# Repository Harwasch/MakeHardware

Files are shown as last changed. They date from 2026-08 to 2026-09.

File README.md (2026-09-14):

# MakeHardware

A Claude Code **plugin** that teaches AI agents to do hardware engineering, and
the cloud environment that gives them the tools to do it.

This repo is not a hardware project. It holds the workflow, practices, skills
and definitions; the projects themselves live in their own repos and install
this plugin.

```
MakeHardware  (this repo)          your-widget  (a project repo)
├── the workflow                   ├── plan.yaml
├── the skills                 ──► ├── requirements/
├── the house practices            ├── cad/  hw/  sim/
└── the environment setup          └── docs/{reference,design,user}
```

## Using it on a project

**Start here: [docs/03-using-it.md](docs/03-using-it.md)** walks through a whole
project from a one-sentence idea to a verified design.

The short version — in the project repo's `.claude/settings.json`:

```json
{
  "extraKnownMarketplaces": {
    "makehardware": {
      "source": { "source": "github", "repo": "Harwasch/MakeHardware" }
    }
  },
  "enabledPlugins": { "makehardware@makehardware": true }
}
```

That is enough on a local machine you have trusted for plugins. **In a cloud
session it is not sufficient on its own** — a repo-declared marketplace is
ignored for an untrusted folder, and `enabledPlugins` never installs anything.
The environment's setup script therefore installs the plugin at user scope; see
[docs/01-environment.md](docs/01-environment.md#why-the-setup-script-installs-the-plugin).

Then point the project at a cloud environment built from [`env/`](env/) and run
`/hw-new-project` to scaffold it.

To stop copying that file into every new repo by hand, make a **GitHub template
repository** out of [`templates/github-repo/`](templates/github-repo) — see
[docs/04-template-repo.md](docs/04-template-repo.md).

## The workflow

```
1 VISION ─► 2 PLAN ─► 3 REQS ─► 4 ARCHITECTURE ─► 5 DESIGN ─► 6 SIMULATE ─► 7 VERIFY
 interview   chunks &  decompose  block diagram    schematic   ngspice       evidence
 + renders   deps      + validate  + power budget   + CAD       FEA           + gate
     ▲          ▲          ▲            ▲              ▲           │            │
     │          │          │            │              └───────────┘            │
     │          │          │            └──── a rail is short ──────┤            │
     │          │          └────────── numbers must move ───────────┤            │
     └──────────┴──────── the thing is not what they meant ─────────────────────┘
```

Stages 1–4 are agreements with a human. Stages 5–7 are a loop. Full detail in
[docs/02-workflow.md](docs/02-workflow.md).

**Every agreement is a recorded one.** The agent is normally working in a cloud
VM, so the human's only review surface is this repository on github.com. At each
milestone the agent commits an artefact that renders there — a vision document,
the plan's scope and Gantt, the requirements map, the block diagram, a schematic
PDF — asks the human directly with the link, and records what they said in
`docs/review/reviews.yaml`. `review-gate check --gate` fails while a milestone
is unanswered, or while an artefact has changed since it was signed off. A
chunk in `plan.yaml` cannot be marked `done` until its review is signed and its
declared outputs exist on disk.

Alongside the repo there is **one review page per project** — `review-artifact`
builds `docs/review/artifact.html` from the repo and it is published as a
Claude Artifact: a tab per phase, every figure and number read from the file
that owns it, and the human comments on it in place. GitHub is the record; the
page is the thing they actually read. `review-artifact --init` writes its
config, and `--url` records where it was published so every later session
updates that page rather than making a second one.

The rule behind it: **an artefact the human has not seen is not a deliverable.**
And its corollary, which is what most of 0.4.0 is about: an artefact they
cannot *read* has not been seen. A schematic nobody can follow, a STEP file
that opens as one unnamed solid, and a wall of numbers where a chart belongs
are all deliverables in name only.

## What the plugin provides

| | |
|---|---|
| **Skills** | `hw-vision`, `hw-planning`, `hw-requirements`, `hw-block-diagram`, `hw-schematic`, `hw-pcb-layout`, `hw-cad`, `hw-optimize`, `hw-review`, `hw-visuals`, `hw-sourcing`, `hw-simulation`, `hw-magnetics`, `hw-verification`, `hw-documentation`, `hw-imagegen`, `hw-retro` |
| **Commands** | `/hw-new-project`, `/hw-status`, `/hw-review`, `/hw-retro` |
| **Gates** | `sch-lint`, `pcb-lint`, `cad-export --check`, `req-trace --gate`, `block-diagram --check`, `plan-render --check`, `review-gate check`, `hw-iterate status --gate` |
| **Tools on PATH** | `hw-doctor`, `hw-repair`, `plan-render`, `req-trace`, `block-diagram`, `vision-board`, `review-gate`, `review-artifact`, `sch-lint`, `pcb-lint`, `cad-export`, `hw-chart`, `hw-iterate`, `hw-feedback`, `imagegen` |
| **MCP servers** | `spice` (ngspice/LTspice), `build123d` |
| **Templates** | An A3 KiCad drawing sheet and the house grid, text sizes and net classes |
| **Practices** | House standards for schematic and board drawing, sourcing, connectors, passives and charts — edited over time to steer the agent |

## The toolchain

| Layer | Tool |
|---|---|
| Human review | `review-gate` — artefacts that render on GitHub, a link put to the human, a committed sign-off with a digest per artefact |
| Requirements | StrictDoc, with a hardware grammar and a traceability gate, plus a draw.io/SVG requirements map |
| Architecture | `block-diagram` — one YAML spec renders an editable draw.io file, a review SVG, and a power budget with a gate |
| Planning | `plan-render` — a dependency Gantt, an editable draw.io graph, and a scope document, with `done` checked against the filesystem |
| Schematic / PCB | KiCad 10 + [KiStack](https://github.com/American-Embedded/KiStack) skills over `kicad-cli` and `kicad-python` |
| Circuit simulation | ngspice via `ltspice-mcp`; LTspice opt-in |
| 3D CAD | build123d + `build123d-mcp` |
| Meshing / FEA | gmsh + CalculiX |
| Vision imagery | build123d renders for geometry; HF Spaces or a keyed API for styling |
| Design review | [kicad-happy](https://github.com/aklofas/kicad-happy) — EMC, thermal, derating, distributor search |

Why each, and what was rejected: [docs/00-stack.md](docs/00-stack.md).

## Setting up the environment

Three fields in the cloud environment dialog at
[claude.ai/code](https://claude.ai/code):

1. **Network access → Full.** Nothing to paste. Sourcing and documentation
   mean fetching datasheets from vendors you can't enumerate in advance, so an
   allowlist makes every new manufacturer a config change.
   [`env/allowed-domains.txt`](env/allowed-domains.txt) has the tighter
   Custom fallback if you'd rather not run open — note that on **Trusted** you
   silently get KiCad 7 instead of 10.
2. **Environment variables** ← [`env/environment-variables.env`](env/environment-variables.env)
3. **Setup script** ← [`env/setup.sh`](env/setup.sh) — this also installs the
   plugin itself, which is why a cloud session gets the skills and MCP servers
   without a trust dialog.

Then run `hw-doctor` in a session. Details and the five failure modes the
script works around: [docs/01-environment.md](docs/01-environment.md).

## Layout

```
.claude-plugin/marketplace.json   marketplace manifest
plugins/makehardware/
├── skills/                       the workflow stages
├── commands/                     /hw-new-project, /hw-status, /hw-review, /hw-retro
├── bin/                          hw-doctor, hw-repair, plan-render, req-trace,
│                                 block-diagram, vision-board, review-gate,
│                                 review-artifact, hw-chart, hw-iterate, imagegen
├── scripts/                      their implementations
└── .mcp.json                     spice, build123d
templates/github-repo/            contents of the GitHub template repository
examples/thermal-probe/           a worked project, part-way through — see below
env/                              cloud environment configuration
docs/                             stack rationale, environment, workflow
tests/smoke.sh                    scaffolds a throwaway project and drives the gates
tests/real-tool-output.sh         what the review page does with real exporter output
tests/version-bump.sh             refuses a plugin change that did not bump the version
CHANGELOG.md                      what changed, per version
CLAUDE.md                         house rules for working on this repo
```

`tests/smoke.sh` needs only `python3` with `pyyaml`. It scaffolds a project
from the template and checks the things that used to have nothing behind them:
a `done` chunk whose outputs are missing, a `done` chunk whose review is
unsigned, an artefact edited after sign-off, and the power budget's voltage
referral.

`tests/real-tool-output.sh` covers the other half: what the review page does
when it is handed what the real tools emit rather than what we would write by
hand. Page size in millimetres, a `<style>` block whose selectors are global
once inlined, KiCad 10's layer-named ids colliding between sheets, a
megabyte-and-a-half render, a PDF, and an export that silently did not happen.

## Releasing

Any change under `plugins/makehardware/` must bump the version in **both**
`.claude-plugin/marketplace.json` and
`plugins/makehardware/.claude-plugin/plugin.json`, with a `CHANGELOG.md` entry
in the same commit.

This is not housekeeping. `claude plugin install` treats an already-installed
plugin at the same version as nothing to do, so a version that does not move
means a user who runs `claude plugin marketplace update makehardware` fetches
the new source, sees a version they already have and **keeps running the old
code**. `tests/version-bump.sh` fails the build when it happens.

Users on an existing cloud environment pick up a release either by rebuilding
the environment — `env/setup.sh` installs the plugin at container build — or
with `claude plugin marketplace update makehardware` in a live session.

## The worked example

[`examples/thermal-probe/`](examples/thermal-probe) is a project caught
part-way through: one milestone approved, one awaiting an answer, one gone
stale because an artefact moved underneath it, and one never requested. It is
what the review page is developed against.

```bash
cd examples/thermal-probe && ./build-fixture.sh
```

rebuilds every artefact from its spec — including the schematic sheets, which
are genuine `kicad-cli sch export svg` output where `kicad-cli` is installed,
because what a plotter emits is nothing like what you would draw by hand.

## Docs

* [docs/00-stack.md](docs/00-stack.md) — choices, rejections, measured build budget
* [docs/01-environment.md](docs/01-environment.md) — environment configuration
* [docs/02-workflow.md](docs/02-workflow.md) — the seven stages and their exit conditions
* [docs/03-using-it.md](docs/03-using-it.md) — how you actually run a project with it
* [docs/04-template-repo.md](docs/04-template-repo.md) — a GitHub template repo so new projects start correct

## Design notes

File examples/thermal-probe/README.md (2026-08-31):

# Thermal Probe

Example project used to develop the MakeHardware review artifact.

<!-- PLAN:BEGIN -->
<!-- generated by plan_render.py — edit plan.yaml, not this block -->

Project plan

**0/11 chunks complete** · 10 sessions on the critical path · [editable version](docs/plan.drawio)

<!-- PLAN:END -->

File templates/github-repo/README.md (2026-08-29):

# <project name>

A hardware project built with the [MakeHardware](https://github.com/Harwasch/MakeHardware)
workflow. Replace this paragraph with one sentence about what the thing is.

<!-- PLAN:BEGIN -->
<!-- PLAN:END -->

## Getting started

This repo was created from the MakeHardware project template, so
`.claude/settings.json` is already correct. In the **first** session, run:

```
/hw-new-project
```

That scaffolds `plan.yaml`, `requirements/`, `hw/`, `cad/`, `concepts/`,
`sim/`, `docs/`, `strictdoc.toml` and a project `CLAUDE.md` from the plugin's
current templates, then runs `hw-doctor` and `imagegen --list` so you know what
the toolchain can actually do before you plan around it.

Then start the vision interview:

```
Use hw-vision. I want to build <one sentence>.
```

## The commands you will use

```bash
hw-doctor                 # what the toolchain can actually do right now
/hw-status                # progress, what is ready to start, what is waiting on you
/hw-review <milestone>    # build the artefact, ask you about it, record the answer
plan-render               # refresh docs/plan.{svg,md,drawio} and the block above
plan-render --check       # exit 1 on a `done` chunk whose outputs or review are missing
block-diagram             # refresh the architecture diagram and power budget
block-diagram --check     # architecture gate; exit 1 on an over-budget rail
req-trace --gate          # traceability gate; exit 1 while gaps remain
req-trace --map           # redraw the requirements map
review-gate list          # where every human review stands
```

## How you get asked things

Claude runs in a cloud VM, so it cannot show you anything directly. At each
milestone — the vision, the plan, the requirements, the architecture, and each
large design stage — it commits something that renders here on GitHub and then
asks you, with the link:

| Look at | For |
|---|---|
| `docs/design/vision.md` | the concepts, their envelopes and masses |
| `docs/plan.md` | what each chunk of work actually is |
| `docs/design/requirements-map.svg` | the requirement tree and its gaps |
| `docs/design/block-diagram.svg` | the power tree and the buses |
| `docs/design/*.pdf` | schematics and board layer plots |

Your answer goes into `docs/review/reviews.yaml`, and nothing downstream is
marked done without it. If Claude later changes something you signed off, that
review goes stale and it has to come back and ask again.

## Before you start: the environment

The plugin's skills are useless without the toolchain behind them. This repo
needs a Claude Code cloud environment built from
[MakeHardware's `env/`](https://github.com/Harwasch/MakeHardware/tree/HEAD/env) —
network access **Full**, the environment variables file, and the setup script.

The setup script is not optional. `.claude/settings.json` declares the plugin
but does not install it: in a cloud session a repo-declared marketplace is
ignored for an untrusted folder, so the setup script installs the plugin at
user scope. Without it you get a repo with no skills in it.

See [docs/01-environment.md](https://github.com/Harwasch/MakeHardware/blob/HEAD/docs/01-environment.md).

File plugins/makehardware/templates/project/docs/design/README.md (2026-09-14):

# Design documentation

How and why this system was built, written as the work happens.

* `adr-NNNN-<slug>.md` — decision records. One per decision that constrains
  anything downstream.
* `architecture.md` — the block-level picture and how the pieces divide.
* `interfaces.md` — board outline, connector pinouts, mounting, anything two
  disciplines have to agree on.
* `verification-report.md` — the output of the verification stage.
* `friction-log.md` — three-line entries written during the work, whenever a
  correction or an avoidable loop happens, each naming the MakeHardware file
  that should change. See the `hw-retro` skill.
* `retro.md` — the synthesis, written by `/hw-retro` at a milestone.
* `feedback/` — one file per finding about the **toolbox**, written by
  `hw-feedback new` and published as an issue on the plugin's repo at the
  retro. Findings about *this design* are not these; they are ADRs.

An ADR has: Status, Context, Decision, Consequences, Alternatives considered.
Write the Consequences honestly, the bad ones included — that section is what a
future session reads when the number has to move.

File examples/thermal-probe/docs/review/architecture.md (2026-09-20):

# Review — Block diagram, power tree and buses

`architecture` · requested 2026-09-20 · branch `claude/board-docs`

Four rails. VBUS is the tight one at 90% of the USB-C default
500 mA while charging, which is fine because it is a charge-only rail — but it
is the number to check. Standby on V3P3 comes to 12 uA of the 40 uA budget.

## What you are agreeing to

**block-diagram.svg**



## For context

Sources and working files. Not part of the agreement — these change as work goes on, and changing them does not invalidate your sign-off.

| File | Opens in |
|---|---|
| [hw/block-diagram.drawio](https://github.com/Harwasch/MakeHardware/blob/claude/board-docs/hw/block-diagram.drawio) | draw.io / VS Code extension |
| [hw/block-diagram.yaml](https://github.com/Harwasch/MakeHardware/blob/claude/board-docs/hw/block-diagram.yaml) | plain text on GitHub |

## What we need decided

1. Is a rail or a part missing?
2. SPI1 shares flash and LCD on one bus — acceptable, or separate them?
3. Is charging at 450 mA off a 500 mA port too close?

## Decision

**Not yet reviewed — this is waiting on you.**

Answer in the Claude session that sent you this link. There is nothing to run and nothing to sign here.

Say which option you want **and why**: the reason is worth more than the choice, and it is what gets re-read later when a number has to move. If something is wrong, say what would be right.

<details><summary>How the answer gets recorded</summary>

The agent writes your decision, in your words, into [`docs/review/reviews.yaml`](https://github.com/Harwasch/MakeHardware/blob/claude/board-docs/docs/review/reviews.yaml):

```bash
review-gate sign architecture --approve --by <name> --note "..."
review-gate sign architecture --changes "what to change"
```

Until that happens, any chunk of work depending on this review cannot be marked done.

</details>

---

<sub>Generated by `review-gate`. The sign-off record is [`docs/review/reviews.yaml`](https://github.com/Harwasch/MakeHardware/blob/claude/board-docs/docs/review/reviews.yaml).</sub>

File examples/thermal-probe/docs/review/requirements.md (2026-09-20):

# Review — Requirements tree

`requirements` · requested 2026-09-20 · branch `claude/board-docs`

Fifteen requirements. SYS-001 moved from 12 h to 7 d after the
logging interval was settled at one minute, which is the number worth arguing
about.

## What you are agreeing to

**requirements-map.svg**



## For context

Sources and working files. Not part of the agreement — these change as work goes on, and changing them does not invalidate your sign-off.

| File | Opens in |
|---|---|
| [requirements/00-vision.sdoc](https://github.com/Harwasch/MakeHardware/blob/claude/board-docs/requirements/00-vision.sdoc) | StrictDoc source |
| [requirements/10-system.sdoc](https://github.com/Harwasch/MakeHardware/blob/claude/board-docs/requirements/10-system.sdoc) | StrictDoc source |
| [requirements/hardware.sgra](https://github.com/Harwasch/MakeHardware/blob/claude/board-docs/requirements/hardware.sgra) | download |

## What we need decided

1. Is 7 days the right target, or is 5 with a smaller cell better?
2. Is anything here that nobody asked for?

## Decision

**Approved** 2026-09-20 by harrison. Nothing is needed from you here.

> 7 days. A week means Friday-to-Friday and nobody has to think.

---

<sub>Generated by `review-gate`. The sign-off record is [`docs/review/reviews.yaml`](https://github.com/Harwasch/MakeHardware/blob/claude/board-docs/docs/review/reviews.yaml).</sub>

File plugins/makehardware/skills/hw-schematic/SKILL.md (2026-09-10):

---
name: hw-schematic
description: House practice for a schematic a human can actually read - how to split a design into sheets from the agreed block diagram, where on the sheet each thing goes, and the gate that checks it. Use before starting schematic capture, whenever a sheet is being laid out or re-laid out, when a schematic needs to go in front of a reviewer, and when asked whether a drawing is readable or why a sheet is too big. KiStack's kicad-schematic does the placing and wiring; this decides what goes where and what good looks like, and wins where the two disagree.
---

# Drawing a schematic somebody can read

The tooling will place a symbol anywhere you tell it to. That is the problem.
Nothing in the toolchain has an opinion about *where*, so a capture loop that
is only trying to satisfy a netlist produces a drawing that is electrically
correct and visually unreadable — and the review that was supposed to catch
the design error instead gets spent on deciphering the picture.

The rule this skill exists to enforce:

> **A schematic is a document, not a netlist with coordinates.** Its job is to
> let a human find a circuit, follow it, and judge it. If it does not do that,
> it does not matter that it is correct.

**Start at `ki-stack-orient`, and work `references/kicad-channels.md` when a
step fails.** Between them they answer the recurring question: `kicad-cli`
cannot author — it has no `add`, `place`, `route` or `connect` verb — so
authoring is either live IPC (`kipy`, needs `hw-kicad-up`) or an edit to the
file itself. It also has the table of where KiStack's house practice and this
skill's disagree — the sheet strategy is the one that matters.

Run the gate:

```bash
sch-lint hw/probe.kicad_sch                    # the report
sch-lint hw/probe.kicad_sch --gate             # exit 1 on any ERROR
sch-lint hw/probe.kicad_sch --svg docs/design/lint      # the findings, drawn
sch-lint hw/probe.kicad_sch --plan hw/block-diagram.yaml
```

`--svg` is the one to use in a review: it writes a light overlay of the sheet
with every finding circled and numbered. About three hundred elements against
the sixty thousand a real KiCad plot costs, so it inlines on the review page
and renders on github.com, which the plot does not.

## Before any symbol is placed: plan the sheets

Capture starts from `hw/block-diagram.yaml`, not from a blank page. The
architecture was already agreed with a human at the architecture review; the
sheet plan is that agreement turned into pages.

The default partition, which you deviate from only for a reason you write down:

| Sheet | Carries | Why it is its own sheet |
|---|---|---|
| 1 | **Root** — one hierarchical block per sheet below, wired to each other | It is the block diagram. A reviewer who has seen the block diagram can read page 1 in ten seconds. |
| 2 | **Power** — the whole tree: input, protection, every regulator, every rail's bulk | A rail is a system-level object. Split across sheets, nobody can see the tree. |
| 3 | **Processor core** — the MCU/SoC, its crystal, reset, boot straps, debug header, and *its* decoupling | Decoupling lives beside its part, never on a "capacitors" sheet. |
| 4..n | **One sheet per functional group** — one sensor chain, one radio, one motor driver | One sheet, one job. A sheet you cannot name in three words is two sheets. |
| last | **Connectors, test points, mounting, fiducials** | The mechanical/external interface, which is what someone bringing the board up looks at first. |

`sch-lint --plan hw/block-diagram.yaml` checks this bound the other way: every
block the human agreed to has to appear on exactly one sheet. A block in the
agreed architecture and on no sheet was dropped without a decision, and that is
the failure this catches — silently, otherwise, until layout.

See `references/sheet-plan.md` for how to derive the plan and how to size a
sheet before you fill it.

## The rules, and what each one costs when broken

Full list with the reasoning in `references/readability.md`. The short version,
in the order they bite:

**Signal flows left to right, power flows top to bottom.** Inputs and their
connectors on the left, processing in the middle, outputs and their connectors
on the right. Rails drawn upward out of a part, grounds downward. This is the
one convention every reader already has, and every violation costs them a
re-read of the sheet. `SCH-FLOW`, `SCH-PWRDIR`.

**Everything on the 1.27 mm grid.** Not aesthetics — a pin 0.01 mm off grid
looks connected and is not, and ERC will not tell you. `SCH-GRID`.

**Wires orthogonal.** No diagonals. `SCH-DIAG`.

**Every net that matters carries a name a human chose.** `3V3_ANA`, not
`Net-(U2-Pad3)`; `SPI1_MOSI`, not `N$32`. A net name is the only handle a
reviewer, a layout engineer and a bring-up engineer share. `SCH-AUTONET`.

**Use labels instead of long wires.** Past about a third of the sheet, a wire
is worse than a label: it crosses things, and following it is work. Short stub,
name it, move on.

**Decoupling is drawn beside the pin it decouples.** Not in a row at the edge
of the sheet. A cap drawn 60 mm from its IC is a cap that ends up 12 mm from it
on the board, because whoever placed the board read the schematic. `SCH-DECAP`,
and then `pcb-lint`'s `PCB-DECAP` measures the copper.

**One text size.** 1.27 mm, with 1.524 and 2.54 for headings. Five sizes on a
sheet reads as five levels of importance that do not exist. `SCH-TEXTSIZE`.

**Designators count the way the eye moves** — left to right, top to bottom, per
sheet. Someone is holding a BOM line looking for R47. `SCH-ANNOT`.

**A filled title block, and the same revision on every sheet.** A printed sheet
with no name, revision or date is not a document, and two sheets at different
revisions means nobody can say which drawing was agreed to. `SCH-TITLE`,
`SCH-REVSKEW`.

**Hierarchical pins match the child's labels exactly.** `VPP-MCLR` against
`VPP_MCLR` is a broken connection that looks fine on both pages.
`SCH-SHEETPIN`.

**A sheet the review page cannot embed is a sheet nobody will review.** KiCad
writes one path per glyph stroke, so an ordinary A4 sheet is 60,000 SVG
elements and three megabytes — twice what `hw-review`'s page can inline. Over
budget is not a rendering problem, it is too much on one page. `SCH-DENSITY`.

## Doing the work

1. **Sheet plan first**, from `hw/block-diagram.yaml`. Write it down in
   `docs/design/` before placing anything.
2. **Create the sheets and the hierarchy**, then the sheet pins, then wire the
   root. Page 1 should look like the block diagram.
3. **Fill one sheet at a time**, in reading order: connectors and inputs on the
   left edge, the main part in the middle, outputs right. Place the main part
   first, then its decoupling against its power pins, then everything else.
4. **Name every net as you make it.** Renaming later is a diff nobody reviews.
5. **Run `sch-lint` after every sheet**, not at the end. Every finding is
   cheaper now than after the next sheet.
6. **Run ERC as well** — `kicad-cli sch erc` — and put the count in the review
   summary as a number, not as an attachment.
7. **Export and look at it yourself** before showing anyone. Half of what a
   reviewer would catch, you will catch first.

Edits go through the **IPC bindings** where a KiCad is running, and through the
file itself otherwise — that is what KiStack's `kicad-schematic` assumes. Never
hand-roll an S-expression edit: `sed` or a regex on a `.kicad_sch` invalidates
UUIDs and symbol instance paths, the file still opens, and the netlist is
quietly wrong. Change one thing, re-export, and look at the plot. `sch-lint`
only ever reads.

## Setting up a new project's schematic

```bash
# The house drawing sheet: A3 frame, title block wired to the project fields.
cp "${CLAUDE_PLUGIN_ROOT}/templates/kicad/makehardware.kicad_wks" hw/
```

Then point the project at it (`Page Settings -> Drawing sheet`, or
`schematic.page_layout_descr_file` in the `.kicad_pro`), and merge the house
grid and text defaults from `templates/kicad/house-defaults.json` into the
`.kicad_pro` — a `.kicad_pro` is JSON, so this is one of the few KiCad files a
structured edit can touch without a KiCad parser. `/hw-new-project` does both.

A3 is the default because A4 forces a split that is about paper rather than
about function, and a sheet split for the wrong reason is worse than a slightly
full one.

## What this skill is not

It is not a circuit-design skill. What the circuit *should be* comes from the
requirements, the block diagram, `hw-sourcing` for the parts and the datasheet
for the topology. This is only about the drawing — which is the half that
decides whether anybody catches the mistake in the other half.

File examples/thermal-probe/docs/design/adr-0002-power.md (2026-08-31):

# ADR-0002: Linear regulator for the always-on rail

## Status
Accepted — 2026-08-14

## Context
`ELE-001` caps standby draw at 40 uA on the always-on rail. The rail is 3.3 V
and carries under 12 mA even when the display is refreshing, so the question is
quiescent current, not efficiency at load.

## Decision
MCP1700 LDO from VBAT, rather than a buck converter.

## Consequences
- Quiescent current 1.6 uA typ, 4 uA max over temperature. That is 10% of the
  40 uA budget, which leaves room for the reference and the MCU's stop-mode
  leakage.
- Dropout is 178 mV at 100 mA, so the minimum usable cell voltage is 3.48 V.
  That truncates the discharge curve and costs roughly 4% of nameplate
  capacity — accepted, and it feeds the `SYS-001` analysis.
- Efficiency above 5 mA is poor. The display refresh burst runs at 12 mA for
  40 ms once a minute, which is 8 uAh per hour of waste. Negligible here, but
  if a backlight is ever added this decision has to be revisited.

## Alternatives considered
- **TPS62740 buck**: 360 nA Iq and far better burst efficiency, but it needs a
  2.2 uH inductor and 4 mm² of board the `MEC-001` envelope does not have at
  the agreed 38 mm width.
- **Direct from VBAT, no regulator**: the ADC reference would then move with
  the cell, and `ELE-003` asks for 0.2 degC over the range. Ratiometric
  measurement against a gated REF3025 was cheaper than a regulator good enough
  to be a reference.

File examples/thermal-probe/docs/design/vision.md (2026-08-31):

# Vision — Thermal Probe

A handheld probe that logs temperature in a walk-in freezer for a week on one charge, readable with gloves on. Every image below comes from a parametric model, so the numbers are measured off the geometry rather than estimated.

## The choice

| | **Wand** | **Bench instrument** |
|---|---|---|
| Envelope (mm) | 38 × 164 × 22 | 92 × 118 × 34 |
| Volume (mm³) | 72,840 | 214,600 |
| Approx. mass (g) | 102 | 300 |

## Wand

One-handed. Probe on a 300 mm flex lead so the body never enters the cold zone. Two-digit display, one button.

**What this one bets on:** That the freezer walk is the whole job, so the display can be small and the body has to survive a glove.

**38 × 164 × 22 mm** · 72,840 mm³ · ~102 g at 1.4 g/cm³

Wand

## Bench instrument

Sits on a shelf in the plant room and gets picked up. Four-digit display with a trend strip, dock contacts on the base.

**What this one bets on:** That it lives in one place and is read at arm's length, so it can be wider and carry a bigger cell.

**92 × 118 × 34 mm** · 214,600 mm³ · ~300 g at 1.4 g/cm³

Bench instrument

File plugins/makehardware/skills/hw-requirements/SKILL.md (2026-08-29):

---
name: hw-requirements
description: Author, decompose and validate hardware requirements as StrictDoc .sdoc files with full parent/child traceability. Use after the vision is agreed, whenever requirements need adding, splitting or renumbering, or when asked whether a design actually satisfies what was asked for.
---

# Requirements

Requirements live in `requirements/*.sdoc` and share the grammar in
`requirements/hardware.sgra`. They are plain text in git, so they diff and
review like code.

## The levels

The UID prefix carries the decomposition level. Nothing else does.

| Prefix | Level | Testable? | Refines |
|---|---|---|---|
| `VIS-` | vision intent, in the human's words | no, deliberately | nothing |
| `SYS-` | system requirement | yes | a `VIS-` |
| `ELE-` `MEC-` `FW-` `MFG-` | discipline requirement | yes | a `SYS-` |

Two rules make the tree mean something:

* **Every non-vision requirement Refines exactly one parent.** If you cannot
  name the parent, nobody asked for the requirement — raise it with the human
  instead of inventing a parent.
* **Every leaf carries EVIDENCE before it can be Verified.** A requirement with
  no evidence is a claim.

## Writing one

One "shall" per requirement, with a number and a unit wherever physics allows
one. "Low power" is not a requirement; "<= 40 uA in standby" is.

`RATIONALE` is the field that earns its keep. Write down *why this number*.
It is what you re-read when the number has to move, and it is what stops a
later session quietly relaxing a limit.

Use `BUDGET` when a parent's number is being divided among children, so the
roll-up can be checked: a 12 h parent against 40 uA + 180 uA children.

Multi-line fields need explicit block markers, and the body is rendered as
RST — a bare `SYS-*` will break the build on an unterminated emphasis span,
so write ``` ``SYS-`` ``` instead:

```
RATIONALE: >>>
Derived from SYS-001: a 900 mAh cell, 12 h active at 65 mA, and a 7-day
standby tail leaves 40 uA for the always-on rail.
<<<
```

## Validating

StrictDoc enforces referential integrity — duplicate UIDs and parents pointing
at nothing both fail the build:

```bash
/opt/hw-py/bin/strictdoc export requirements \
    --output-dir build/requirements --formats=html,json
```

What StrictDoc will not judge is whether the decomposition is any good. That
is `req-trace`, which finds orphans, undecomposed mid-level requirements,
leaves with no evidence, requirements with no design artefact linked, and
status/evidence mismatches:

```bash
req-trace              # report
req-trace --gate       # exit 1 on any gap
req-trace --map        # the requirements map: SVG + draw.io
```

Run the gate before claiming a stage is complete.

## Draw the tree, because that is what a human can review

A requirement set is a graph. Its two real failure modes — something hanging
loose, and a number that traces to nothing anybody asked for — are shape
questions, and reading a list of UIDs is how a gap survives a review.

```bash
req-trace --map        # docs/design/requirements-map.{svg,drawio}
```

The SVG renders inline on github.com: one column per decomposition level,
an arrow from each requirement to the one that refines it, the status on every
node, and the gate's findings marked in red on the nodes that have them. The
`.drawio` is the same graph, editable.

The StrictDoc HTML export is the complete, navigable version:

```bash
/opt/hw-py/bin/strictdoc export requirements \
    --output-dir docs/design/requirements-html --formats=html
```

GitHub will not render it, so it is a download — link it, say so, and do not
mistake generating it for having shown it to anyone. That export was produced
on every validation run of one project and never once mentioned.

## Validate the set, not just each requirement

Before starting design, check the things a per-requirement check cannot see:

* **Roll-up.** Do the children's budgets actually add up to the parent's? Say
  the arithmetic out loud.
* **Contradiction.** Two requirements that cannot both hold (an IP67 seal and
  a passive vent).
* **Over-constraint.** A requirement set with no feasible solution is more
  common than it sounds; if you cannot find one, say so now.
* **Missing verification.** Every leaf's `VERIFICATION` must be something this
  environment or the human can actually perform.

Report what you find to the human and get the numbers changed before design
starts, not after.

## Leaving the stage

The numbers in here are what every later stage is built on, and they are much
cheaper to argue about now. So the stage is not finished when the tree
validates — it is finished when a human has looked at it and agreed to the
numbers, recorded in the repo.

```bash
req-trace --map
git add requirements/ docs/design/requirements-map.* && git commit && git push

review-gate open requirements \
    --title "Requirements tree" \
    --summary "<the numbers that moved, the roll-ups, what you are unsure of>" \
    --artifact docs/design/requirements-map.svg \
    --reference requirements/ --reference docs/design/requirements-html/ \
    --question "Are these the right numbers?" \
    --question "Is anything here that nobody asked for, or missing that you assumed?"
```

Ask directly with the link, block on the answer, and record it with
`review-gate sign` — see `hw-review`. Lead the request with the arithmetic
you had to do to make the budgets roll up, and with any requirement you could
not find a parent for. Those are the two places a human catches something you
cannot.

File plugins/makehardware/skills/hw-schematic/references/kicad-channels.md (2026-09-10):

# Which channel touches a KiCad file, where KiStack fits, and who wins

Four things can read or write a `.kicad_*` file here, and they do not overlap.
Reaching for the wrong one is most of what "KiCad automation is flaky" turns
out to be, so this is the map — followed by the part that actually costs time,
which is what to do where KiStack's house practice and this toolbox's disagree.

**Two packs preceded this one.** Konnect (an MCP server, 214 tools) through
0.6.0; ki-stack through 0.7.0. If you are reading guidance that says "all
writes go through Konnect MCP tools", or that names a `ki-stack-*` skill, it is
stale — run `hw-repair kicad`, which installs
[KiStack](https://github.com/American-Embedded/KiStack) and clears the old pack
out of the snapshot.

## The four channels

| | `kicad-cli` | `kicad-python` (IPC) | direct file edit | `sch-lint` / `pcb-lint` |
|---|---|---|---|---|
| **Authors** | **no** | yes, live | yes, and this is what KiStack assumes | no |
| **Checks** — ERC, DRC | yes | via the running app | no | yes, plus house rules the CLI has no concept of |
| **Exports** — PDF, SVG, Gerber, BOM, 3D | yes | no | no | writes the findings overlay |
| **Needs a running KiCad** | no | **yes** | no | no |

`kicad-cli` has no `add`, `place`, `route` or `connect` verb on KiCad 10 and
never has, so authoring is IPC or the file itself. KiStack's own rule:
**prefer the IPC bindings wherever they are available** — `hw-kicad-up` starts
a KiCad and `kipy` connects to it. Fall back to editing the file when there is
no session to talk to.

When you do edit a file: change one thing, re-export, and look at it. Never
`sed` a `.kicad_sch` — a text-level edit invalidates UUIDs, symbol instance
paths and cross-sheet references, the file still opens, and the netlist is
quietly wrong. `scripts/kicad_sexpr.py` here is a **reader**; `sch-lint` and
`pcb-lint` go through it and only ever read.

## The KiStack skills

`kicad-schematic`, `kicad-pcb`, `kicad-layout`, `kicad-symbol`,
`kicad-footprint`, `kicad-bom`, `kicad-export`, `kicad-gerbers`,
`kicad-panelize`, `pcb-product-render`. `kicad-export` carries a reference page
for every `kicad-cli` verb, which is the fastest way to get an export flag
right.

They are human-written house practice from a working shop, and the best thing
in them is the insistence on **iterating on rendered images**: plot the sheet
to SVG, look at it, fix what is ugly, look again. That is the same instinct as
`review-artifact` and `hw-optimize`, applied at a finer grain, and it is worth
following.

## Where KiStack and this toolbox disagree — and who wins

**The gate wins.** `sch-lint`, `pcb-lint` and `review-gate` are the things that
actually fail a stage, and a design that satisfies advice while failing a gate
is not shippable. KiStack supplies craft where the gates are silent.

Three specific collisions, so nobody has to discover them at review time:

| | KiStack says | This toolbox says | Take |
|---|---|---|---|
| **Sheet strategy** | prefer a single sheet you can see at once, bigger paper if needed | a sheet plan derived from the agreed block diagram, A3 default, one sheet per functional group | **the sheet plan.** `sch-lint --plan` binds every sheet back to the architecture a human signed off, and its density check fails an overfull sheet. A single huge sheet also does not render on the review page. |
| **Changing the schematic during layout** | feel free, do pin swaps to clean up routing | the schematic is an agreed artefact | **do it, then re-open the review.** The advice is right — pin swaps are how a board gets routable. But `review-gate` marks the schematic review stale the moment its artefact changes, and that is correct: the human agreed to a different drawing. Say what moved and why. |
| **Autorouting** | avoid it; route manually unless the board is very dense | `hw-verification/references/pcb-layout.md` documents freerouting | **no conflict.** Both say manual first. The freerouting notes exist for the dense case KiStack also allows. |

One that people expect to collide and does not: KiStack's **50 mil label text**
is exactly the house `text_size_mm: 1.27` in `templates/kicad/house-defaults.json`,
which is what `SCH-TEXTSIZE` checks. They agree.

## When a KiCad step fails

1. **Check the obvious first.** `kicad-cli version` (must be 10.x — a KiCad 7
   from Ubuntu universe has no IPC API at all), and that the path you are
   passing is the project's canonical file.
2. **`kipy` cannot connect.** No KiCad running (`hw-kicad-up`), the API server
   disabled in preferences, a busy KiCad, or a version mismatch. Not a reason
   to reach for a text editor — work on the file with a parser, or export and
   check what you have.
3. **The pack is missing.** `hw-doctor` reports `kistack`; `hw-repair kicad`
   installs it and clears any previous pack.
4. **`kicad-cli` refuses the file.** Almost always a major-version mismatch —
   `kicad-cli sch upgrade` / `pcb upgrade`, and say in the review that the file
   format moved.
5. **Only now escalate**, with the command, its output, and what you tried. A
   failure you worked around silently is worse than one you reported: the next
   session hits it again with none of what you learned.

## What to tell the human

**No success claim without evidence** — an artefact path, ERC/DRC output, a
changed-file list, or a render. A plot-after-edit is the cheapest proof there
is. Put it on the review page rather than describing it.

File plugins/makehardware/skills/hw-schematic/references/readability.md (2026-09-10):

# Every rule, and the failure it prevents

Each rule below has a `sch-lint` code beside it. A rule with no code is one
nothing can check yet — treat those as the ones needing the most attention,
because nothing else will catch them.

---

## 1. Direction

### Signal flows left to right — `SCH-FLOW`

Inputs and their connectors on the left edge, processing in the middle,
outputs and their connectors on the right. Feedback is the exception and is
drawn returning above or below the forward path, never through it.

This is not taste. A reader arrives at a sheet with an expectation about where
things are, and every sheet that violates it costs a full re-read. On a design
review that is the difference between a reviewer spending their attention on
your circuit and spending it on your drawing.

`sch-lint` reports the flow as a number — the mean normalised x of the outputs
minus that of the inputs — and warns below +0.15. It never gates: a power
sheet legitimately flows top to bottom and a connector sheet flows nowhere.

### Power flows up, ground flows down — `SCH-PWRDIR`

A rail symbol points up out of the part it feeds; a ground symbol points down.
A reader scans a sheet for supply structure by silhouette, before reading a
single label. A ground drawn sideways breaks that read for the whole sheet, and
`sch-lint` finds them by comparing each power symbol's body centroid against
its pin.

Corollary: on a part with power pins on the left and right, do not route the
rail through the body. Bring it in at the top.

---

## 2. Geometry

### The 1.27 mm grid — `SCH-GRID`

Everything electrical: symbol origins, pin ends, wire endpoints, junctions,
labels, sheet pins. 1.27 mm is 50 mil, KiCad's default, and the pitch every
library is drawn on.

The failure is not ugliness. **A pin 0.01 mm off the grid looks connected and
is not**, ERC reports nothing, and the defect surfaces as a net missing from
the netlist at layout time. It is the cheapest possible check and it catches
one of the most expensive possible mistakes.

Property *text* positions are deliberately not checked. KiCad's autoplacer
writes a reference at (27.3812, 91.5416) on a design that is otherwise
perfectly on-grid; checking those emits about forty errors on finished work,
and a gate that fires on clean work is a gate somebody switches off.

### Wires orthogonal — `SCH-DIAG`

No diagonals, ever. A diagonal wire cannot be followed across a crossing,
cannot be aligned with anything, and reads as an error even when it is not.
Graphic polylines — a dashed box around a functional group — are exempt and
are encouraged.

### Nothing overlapping — `SCH-OVERLAP`

Two symbol bodies overlapping by more than 0.5 mm² is a drawing defect. It
usually means an automated placement pass ran without a courtyard concept.
Stacked power flags are excluded, because stacking them is deliberate.

---

## 3. Naming

### One net, one name, chosen by a human — `SCH-AUTONET`

`3V3_ANA`, not `Net-(U2-Pad3)`. `SPI1_MOSI`, not `N$32`. `THERM_SENSE`, not
`Net-(R14-Pad2)`.

The net name is the only handle shared by the schematic reviewer, whoever lays
out the board, whoever writes the test plan and whoever brings the board up at
2 a.m. An auto-generated name carries the one fact nobody needs — which pad the
autonamer happened to reach first — and destroys the one they do.

Conventions worth holding to:

* Rails by voltage and domain: `3V3`, `3V3_ANA`, `5V_USB`, `VBAT`.
* Grounds by domain: `GND`, `AGND`, `PGND`. If there is only one, `GND`.
* Buses by peripheral and signal: `I2C1_SDA`, `SPI2_SCK`, `UART_DEBUG_TX`.
* Nets that cross a sheet get a name whether or not they need one. Nets local
  to a corner of one sheet do not.

`sch-lint` warns on an unnamed or auto-named net carrying four or more pins.
Three-pin local nets are ordinary and are left alone.

### Designators in reading order — `SCH-ANNOT`

Per sheet, per prefix: left to right, top to bottom. Someone is holding a BOM
line looking for R47 on a printed sheet; scattered annotation turns that into a
search. Re-annotate rather than arguing about it — it is one command and it is
never controversial.

### Value fields say the value — nothing checks this

`100nF 16V X7R 0603`, not `C`. `10k 1% 0402`, not `RES`. The value on the sheet
is what a reviewer checks against the datasheet; making them open the BOM to
find out what the part is defeats the point of drawing it.

---

## 4. Layout of a sheet

### One sheet, one job

If you cannot name what a sheet does in three words, it is two sheets. Group
related circuits and put a dashed graphic box around each group with a text
label — a "Boost converter, 3V3 -> 13V" box costs four polylines and saves
every reader thirty seconds.

### Labels beat long wires — nothing checks this

Past about a third of the sheet's width, a wire is worse than a label: it
crosses other wires, and following it is work. Draw a short stub, name it, and
put the matching stub where it is used. Buses for anything that travels
together — an address bus, a segment drive, an eight-channel ADC front end.

The failure mode in the other direction is real too: a sheet where *everything*
is a label is a sheet with no visible topology. Wire what is local; label what
travels.

### Decoupling beside the pin — `SCH-DECAP`

Every bypass capacitor is drawn immediately beside the power pin it serves,
with its ground symbol directly below it. Never a row of capacitors at the edge
of the sheet, and never on a separate "passives" sheet.

This is a *drawing* rule with a *layout* consequence, which is why it is worth
a gate. Whoever places the board reads the schematic; a cap drawn 60 mm from
its IC is placed 12 mm from it, and 12 mm of trace at 100 MHz is not a
decoupling capacitor. `pcb-lint`'s `PCB-DECAP` then measures the copper.

`sch-lint` warns past 25.4 mm and errors past 50.8 mm, and always errors when
the cap is on a different sheet from its IC.

### Pin ordering follows function, not the package — nothing checks this

Draw an IC symbol grouped by function: power at the top, grounds at the bottom,
inputs left, outputs right, control and configuration wherever it keeps the
wires short. A symbol laid out in physical pin order is a symbol that forces
every reader to do the mapping the symbol was supposed to do for them. Split a
large part into functional units rather than drawing an 80-pin rectangle.

---

## 5. Typography and the frame

### One text size — `SCH-TEXTSIZE`

1.27 mm, with 1.524 mm and 2.54 mm available for headings. Five sizes on a
sheet reads as five levels of importance, and there are not five.

### A filled title block, and one revision across the set — `SCH-TITLE`, `SCH-REVSKEW`

Title and revision are errors when missing; date and company are warnings. A
set of sheets at mixed revisions is a warning that matters more than it looks:
it means nobody can say which drawing the human agreed to at the review, which
is the whole basis of `review-gate`.

### A drawing sheet that is the house one

`templates/kicad/makehardware.kicad_wks`. A3, a title block wired to the
project's own fields, and a note saying the drawing is generated. Consistency
across projects is worth more than any individual frame.

---

## 6. Hierarchy

### Page 1 is the block diagram — `SCH-PLAN`

The root sheet carries one hierarchical block per sheet below it, wired to each
other, and nothing else. A reviewer who has already agreed to
`hw/block-diagram.yaml` should recognise page 1 immediately. Keep the tree one
level deep unless a sub-assembly genuinely repeats.

`sch-lint --plan hw/block-diagram.yaml` checks the binding: every block in the
agreed architecture appears on exactly one sheet. A block that reaches no sheet
was dropped without a decision — the exact failure the architecture review
exists to prevent, arriving two stages later where it costs a respin.

### Sheet pins match the child's labels exactly — `SCH-SHEETPIN`

`VPP-MCLR` on the parent against `VPP_MCLR` in the child is a broken connection
that looks correct on both pages. `sch-lint` reports the near-miss by name so
the fix is obvious.

Directions have to agree too: a pin declared `input` on the parent against a
label shaped `output` in the child is a warning worth reading.

### A sheet the review page cannot embed — `SCH-DENSITY`

KiCad's SVG exporter writes one path per line segment, glyph strokes included.
An ordinary A4 sheet measures around 60,000 elements and three megabytes,
against the 30,000/1.5 MB budget `hw-review/references/exports.md` documents
for a single inlined SVG.

Do not try to solve this by exporting smaller. It is not a rendering problem —
it is a sheet with too much on it. Split it.

`sch-lint` shells out to `kicad-cli` and measures, because the number cannot be
estimated: the two committed example sheets measure 60 and 29 elements per
rendered character, a factor of two apart on the same design. Where `kicad-cli`
is unavailable the estimate only warns, and only when it is half again over.

---

## What nothing checks, and you have to

* **Is the circuit right.** Everything above is about the drawing.
* **Does the symbol match the datasheet pinout.** A symbol with two pins
  swapped passes every check here and every ERC.
* **Are the values right.** `100nF` where the datasheet says `1uF` is invisible
  to a linter.
* **Is anything missing.** A pull-up that was never drawn has no defect for a
  gate to find. This is what the block diagram and the requirements trace are
  for, and it is why `SCH-PLAN` is the check worth caring about most.

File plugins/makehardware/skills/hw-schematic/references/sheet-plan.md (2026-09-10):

# Planning the sheets before drawing on any of them

Capture starts from `hw/block-diagram.yaml`. That file was agreed with a human
at the architecture review; the sheet plan is that agreement turned into pages,
and `sch-lint --plan` checks the two never drift apart.

## Derive it

```bash
block-diagram --summary        # the blocks, the rails, the current budget
```

Then write `docs/design/sheet-plan.md` — a table, committed, before any symbol
is placed:

```markdown
| Sheet | Name | Blocks from the architecture | Rails present |
|---|---|---|---|
| 1 | Root | (hierarchy only) | — |
| 2 | Power | VIN protection, U1 buck 5V, U2 LDO 3V3, VBAT charger | all |
| 3 | MCU | U3 STM32G031, crystal, SWD, boot straps | 3V3 |
| 4 | Sense | U4 instrumentation amp, thermistor front end, filter | 3V3, 3V3_ANA |
| 5 | Display | U5 segment driver, contrast, backlight | 3V3, 5V |
| 6 | Interface | J1 USB-C, J2 probe, TP1-8, mounting, fiducials | 5V_USB |
```

Two sentences under it: what you split and why, and anything you deviated from
the default partition for. That is what a reviewer reads when a sheet turns out
to be in the wrong place.

## The default partition

| Sheet | Carries |
|---|---|
| 1 | **Root.** One hierarchical block per sheet below, wired to each other. Nothing else. |
| 2 | **Power.** The whole tree in one picture: input, protection, every regulator, every rail's bulk, and the battery path if there is one. |
| 3 | **Processor core.** The MCU/SoC, crystal, reset, boot straps, debug header, and its own decoupling. |
| 4..n | **One sheet per functional group.** One sensor chain, one radio, one motor driver, one display. |
| last | **Interface.** Connectors, test points, mounting holes, fiducials. |

Deviate when a real reason says so, and write the reason down. Two that come up:

* **A repeated channel** — four identical sensor front ends — is one sheet
  instantiated four times, not four sheets. That is what hierarchy is for.
* **A very small design** — under about forty parts — can be one sheet, and
  splitting it into six makes it worse. Skip the hierarchy and say so.

## Two things that are always their own sheet

**The power tree.** A rail is a system-level object; split across sheets,
nobody can see the tree, and "is a rail missing" — the question the
architecture review exists to answer — becomes unanswerable from the drawing.

**Never a "passives" or "capacitors" sheet.** Every bypass capacitor belongs
beside the pin it decouples, on that pin's sheet. A capacitors sheet is the
single most common way a schematic becomes unreadable, and it propagates
straight into a board with 12 mm decoupling loops.

## Sizing a sheet before you fill it

The constraint that actually binds is not paper, it is the review page.
`hw-review/references/exports.md` gives a single inlined SVG 1.5 MB and 30,000
elements. KiCad writes one path per glyph stroke, so an ordinary A4 sheet
measures around 60,000 elements — twice the budget.

Rules of thumb that keep a sheet inside it:

* **Under about 35 placed symbols per sheet**, power symbols excluded.
* **One IC with more than about 30 pins per sheet**, plus its immediate
  support. A 100-pin MCU is its own sheet and probably two.
* **Page fill between 15% and 80%.** Below that, the sheet is too big for what
  is on it; above it, there is no margin left to read or to add anything.

Check it rather than trusting the rule:

```bash
kicad-cli sch export svg hw/probe.kicad_sch --output build/sheets/
sch-lint hw/probe.kicad_sch --svg-measure build/sheets/
```

`sch-lint` does this for you when `kicad-cli` is on `PATH`. When it is not, the
number in the header is a rough estimate and says so.

## Naming sheets

The sheet name shows on the root page, in the hierarchy navigator and on every
sheet's title block. Name it after **what the circuit does**, not after the
part: `Sense front end`, not `INA333`. Parts get substituted; jobs do not.

Filenames follow: `power.kicad_sch`, `mcu.kicad_sch`, `sense.kicad_sch`. The
root takes the project name.

## Wiring the root

Page 1 should be recognisably the same picture as
`docs/design/block-diagram.svg`, laid out the same way: sources left, sinks
right, power along the top. A reviewer who agreed to the block diagram then
reads page 1 in ten seconds and can go straight to the sheet they care about.

Bring out on a sheet pin only what genuinely crosses the boundary. A sheet with
forty pins is a sheet split in the wrong place — the partition, not the wiring,
is what needs fixing.

## Keeping it honest afterwards

```bash
sch-lint hw/probe.kicad_sch --plan hw/block-diagram.yaml --gate
```

Every block in the agreed architecture on exactly one sheet. Two failure modes,
both silent otherwise:

* **A block on no sheet** — dropped without a decision. This surfaces at
  layout, or at bring-up, or in the field.
* **A block on two sheets** — usually a part duplicated during a copy-paste of
  a similar circuit, and it produces two BOM lines and one part.

When the architecture legitimately changes, change `hw/block-diagram.yaml`
first, re-run `block-diagram --check`, and re-open the architecture review —
`review-gate` will already be reading stale, because the artefact the human
signed has moved.

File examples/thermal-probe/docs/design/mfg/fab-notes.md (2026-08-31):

# Fabrication notes

What the fab needs in writing, beyond the gerbers. Everything here is quoted
against, so a change to any of it invalidates the prices in `quotes.csv`.

## Board

| Item | Value |
|---|---|
| Layers | 2 |
| Material | FR-4 TG150 |
| Finished thickness | 1.62 mm ±10% |
| Copper | 1 oz both sides |
| Finish | ENIG |
| Soldermask | Green, both sides |
| Silkscreen | White, top only |
| Outline tolerance | ±0.15 mm |
| Min track / gap | 0.15 mm |
| Min drill, finished | 0.30 mm |
| Min annular ring | 0.13 mm |
| Electrical test | 100% netlist |
| Acceptance | IPC-A-600 class 2 |

## Panelisation

Ship as singles at 25 off. At 100 off, a 2 x 3 panel on 3 mm tab routing with
breakaway rails — the assembler's conveyor needs 3 mm of clearance on the long
edges and the current outline does not leave it.

## Things a fab has queried before

* **ENIG at 25 off.** Two of the three quotes carry a surcharge below 50
  pieces. It is priced in above; if the run grows to 50 the unit cost drops
  more than the quantity alone suggests.
* **The 1.00 mm test point** is the smallest hole on the board and the only
  one not on the M3 pattern. It is deliberate and it is plated.
* **No impedance control is specified.** Nothing on this board is a
  transmission line at the speeds involved, and asking for it adds a coupon
  and about 30% to the fab cost.

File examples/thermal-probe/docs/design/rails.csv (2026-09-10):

name | used | budget | unit
VBUS | 450 | 500 | mA
VBAT | 11.05 | 1200 | mA
V3P3 | 12.38 | 250 | mA
VREF | 0.25 | 10 | mA

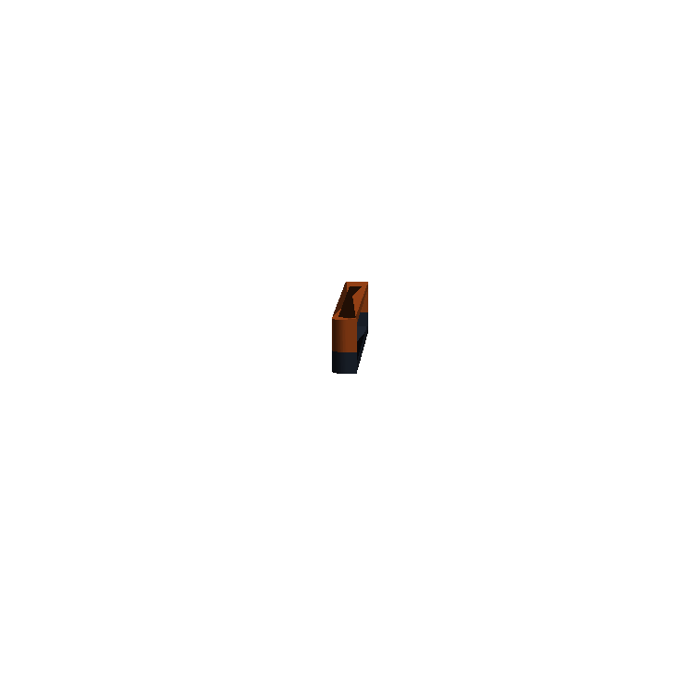
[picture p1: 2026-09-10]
examples/thermal-probe/docs/design/cad/enclosure-section.png

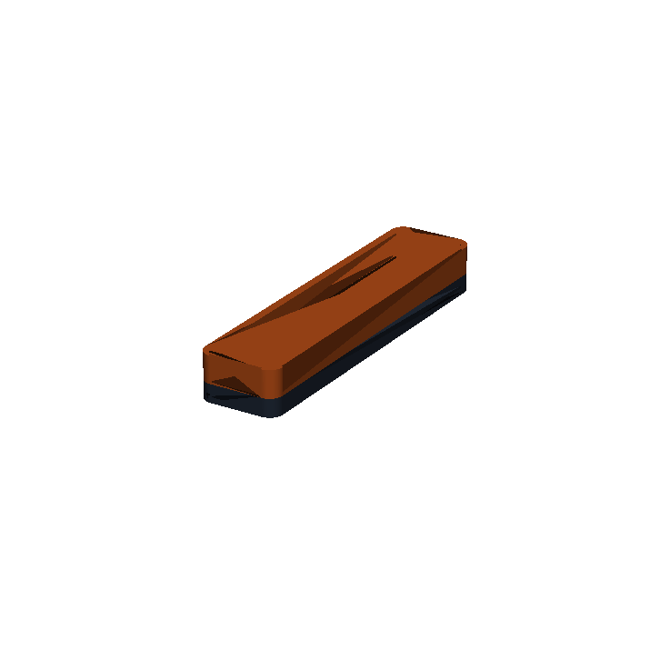
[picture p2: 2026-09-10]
examples/thermal-probe/docs/design/cad/enclosure-render.png

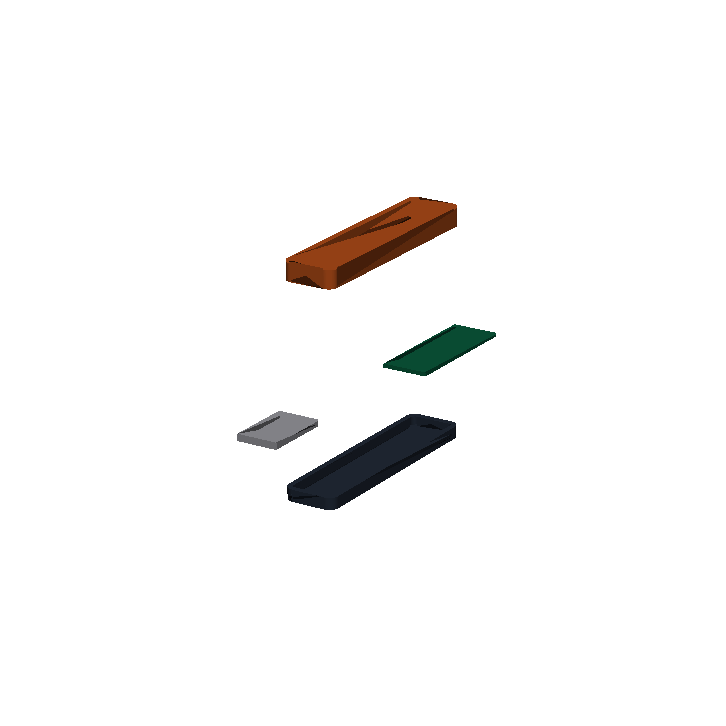
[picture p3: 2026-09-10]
examples/thermal-probe/docs/design/cad/enclosure-exploded.png

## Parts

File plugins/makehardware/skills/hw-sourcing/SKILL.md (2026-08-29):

---
name: hw-sourcing
description: Select components and suppliers according to house practice - how to choose a part, when to prefer a known family over an optimal one, and which brands and series this shop standardises on. Use whenever a part needs picking, a BOM line needs filling, an alternate needs qualifying, or someone asks "what connector should I use".
---

# Sourcing and component selection

House practice lives in `references/` next to this file. Read the relevant one
before picking a part — they encode decisions already made and paid for.

| File | Covers |
|---|---|
| `references/philosophy.md` | How to make a selection decision at all |
| `references/connectors.md` | Connector families this shop standardises on |
| `references/passives.md` | Resistors, capacitors, inductors, tolerances |

These are living files. When the human overrules a choice, **write the new
preference into the reference file in the same session**, with the reason. That
is how this gets better; a correction that only lives in a chat transcript is a
correction you will make again.

## Finding candidates vs. choosing between them

**kicad-happy finds; this skill decides.** Use its `digikey`, `mouser`, `lcsc`
and `element14` skills for real stock, pricing and parametric search, and its
`datasheets` skill to pull specs out of a PDF. Then apply the philosophy below
to pick between what they return. Do not do parametric search from memory when
a distributor skill can answer it.

## Read datasheets locally, and do not fan out

Datasheet research is unusually token-heavy: every PDF arrives as one large
blob, and a parametric comparison wants several of them. Two rules keep that
from consuming a session's whole budget.

**Fetch and extract locally rather than pulling a PDF through an agent's
context.** `WebFetch` cannot read most datasheets — it comes back saying the
specifications are "embedded within the compressed PDF content stream and are
not directly readable". The environment installs `pypdf` and `poppler-utils`
for exactly this:

```bash
curl -sL -o docs/reference/lmg2610-ds.pdf https://www.ti.com/lit/ds/symlink/lmg2610.pdf

/opt/hw-py/bin/python -c '
from pypdf import PdfReader
r = PdfReader("docs/reference/lmg2610-ds.pdf")
text = "\n".join(p.extract_text() or "" for p in r.pages)
open("build/lmg2610.txt", "w").write(text)
print(len(r.pages), "pages,", len(text), "chars")'

grep -n -i -E -A4 "quiescent|thermal resistance|R_DS" build/lmg2610.txt
```

Then read the section you need, not the document. `pdftotext -layout` is the
fallback when `pypdf` mangles a table.

**Serialise the research, or cap it at two or three concurrent agents.** Seven
parallel research agents each fetching and parsing multi-megabyte datasheets
exhausted a five-hour account limit before all but one had returned, taking
out the other six and every verification agent behind them. The work was not
wrong, it was sized wrong. Extract locally as above and fan out over the
*extracted text* if you fan out at all — never over PDF fetches.

Every datasheet you fetch is recorded in `docs/reference/manifest.yaml` with
its revision and retrieval date; see `hw-documentation`.

## The short version

Selection is a constraint problem with a tie-break, not an optimisation:

1. **Filter on the hard constraints** — the electrical and mechanical numbers
   the requirement actually demands, plus temperature range and package.
2. **Filter on availability** — in stock, in quantity, at more than one
   distributor, not marked NRND or last-time-buy. A perfect part you cannot buy
   is not a candidate.
3. **Prefer a family already on the BOM.** Second-sourcing an existing part
   beats introducing a new one, even when the new one is slightly better.
4. **Then** tie-break on cost, footprint size, and datasheet quality.

Never lead with cost. A part chosen on unit price that fails step 2 costs far
more than it saved.

## Always record why

Every non-obvious part choice gets a line in the design documentation — which
alternatives were considered and what decided it. Use
`hw-documentation` and write an ADR when the decision constrains anything
downstream (a regulator that sets the thermal budget, a connector that sets the
enclosure opening).

Link the part choice back to the requirement that drove it with a `File`
relation, so `req_trace.py` can see it.

## What to hand back to the human

When you present a selection, give:

* the part number, and one sentence on why it wins
* the constraint that eliminated the runner-up
* stock and lead time as of now, with the date you checked
* anything that makes it risky: single source, long lead, new silicon, an
  end-of-life notice

If a requirement forces a part that is risky on availability, say so at
selection time — that is a requirements conversation, and it is much cheaper
now than after layout.

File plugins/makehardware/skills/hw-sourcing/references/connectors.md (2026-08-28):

# Connectors

House preferences. **These are placeholders pending the human's real
standards** — ask before treating them as settled, and replace this file with
what they actually use.

## Principles that hold regardless of brand

* **Keyed and polarised** wherever a reversed insertion could damage anything.
* **Locking** for anything that moves, ships assembled, or carries power.
* **Pitch follows current and assembly method**, not board space. Do not put a
  1.0 mm pitch part where a technician has to hand-assemble it in the field.
* **One family per function per product.** Mixing three board-to-wire families
  on one board is an assembly error waiting to happen.
* **Check the mating half is stocked too.** A connector is only as available as
  its least available half, and the crimps and the tool count.

## To be filled in with the shop's actual standards

| Function | Preferred family | Notes |
|---|---|---|
| Board-to-wire, signal | _TBD_ | |
| Board-to-wire, power | _TBD_ | |
| Board-to-board | _TBD_ | |
| External / user-facing | _TBD_ | |
| Debug / programming | _TBD_ | |

Ask the human to fill this in the first time a connector is chosen, then keep
it current.

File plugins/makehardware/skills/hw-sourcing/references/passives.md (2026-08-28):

# Passives

House preferences. **Placeholders pending the human's real standards.**

## Defaults until told otherwise

* **Size:** 0402 for dense digital, 0603 where hand-rework is plausible.
  Nothing smaller than 0402 without a reason recorded in the design docs.
* **Resistors:** thick film, 1%, E96 only where 1% is actually needed;
  otherwise E24 to keep the BOM short.
* **Ceramics:** X7R or better for anything in a control loop, decoupling or
  timing path. **Never Y5V.** Derate MLCC capacitance for DC bias — a 10 uF
  0603 at 5 V can be a third of its marked value, and this is the single most
  common quiet failure in a power design.
* **Voltage rating:** 2x the working voltage as a floor, more on anything
  behind an inductor or exposed to a transient.
* **Electrolytics:** avoid where a ceramic or polymer will do; when required,
  check the ripple current and the endurance rating at the actual operating
  temperature, not at 20 °C.

## Tolerance stack

When several passives set one number (a divider, a filter corner, a current
limit), do the worst-case stack rather than assuming nominal. If the stack
misses the requirement, tighten one part deliberately — do not tighten all of
them.

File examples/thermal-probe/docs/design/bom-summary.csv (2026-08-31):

Ref | Part | MPN | Qty | @1 | @100 | @1k | Basis
U1 | Battery charger | MCP73831T-2ACI/OT | 1 | 0.71 | 0.52 | 0.41 | Quoted — Digi-Key, 8140 in stock, checked 2026-08-28
U2 | 3.3 V LDO | MCP1700T-3302E/TT | 1 | 0.48 | 0.34 | 0.27 | Quoted — Digi-Key, 21k in stock, checked 2026-08-28
U3 | MCU | STM32L071KBU6 | 1 | 3.62 | 3.11 | 2.68 | Quoted — Mouser, 1204 in stock, checked 2026-08-28
U4 | Voltage reference | REF3025AIDBZR | 1 | 1.94 | 1.55 | 1.28 | Quoted — Mouser, 640 in stock, checked 2026-08-28
U5 | Log flash 16 Mbit | W25Q16JVUXIQ | 1 | 0.63 | 0.44 | 0.36 | Quoted — LCSC, 30k in stock, checked 2026-08-28
DS1 | Segment LCD | VIM-878-DP-RC-S-LV | 1 | 4.10 | 3.40 | 2.90 | ESTIMATE — no distributor stock, factory quote requested 2026-08-29
BT1 | LiPo cell 900 mAh | LP503035 | 1 | 3.80 | 3.20 | 2.60 | ESTIMATE — cell pricing moves with lithium; no quote yet
RT1 | NTC thermistor | NTCLE100E3103JB0 | 1 | 0.34 | 0.21 | 0.16 | Quoted — Digi-Key, 46k in stock, checked 2026-08-28
J1 | USB-C receptacle | TYPE-C-31-M-12 | 1 | 0.29 | 0.16 | 0.11 | Quoted — LCSC, 120k in stock, checked 2026-08-28
SW1 | Wake button | TL3305AF160QG | 1 | 0.22 | 0.14 | 0.10 | Quoted — Digi-Key, 90k in stock, checked 2026-08-28
— | Passives (24 parts) | various | 24 | 1.90 | 0.95 | 0.62 | Quoted — LCSC basket, checked 2026-08-28
— | PCB 2-layer ENIG | — | 1 | 12.40 | 2.10 | 0.94 | Quoted — JLCPCB, 5-day, checked 2026-08-28
— | Enclosure | — | 1 | 18.00 | 6.50 | 2.20 | ESTIMATE — printed at 1-100; injection tooling not quoted
— | BOARD TOTAL | — | 1 | 52.43 | 24.62 | 15.63 | Mixed — 3 lines estimated

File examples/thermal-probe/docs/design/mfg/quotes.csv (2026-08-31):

Scope | Supplier | Qty | Unit GBP | Tooling GBP | Lead time | Quoted | Valid until | Basis
PCB fab, 2 layer ENIG | JLCPCB | 25 | 4.12 | 0 | 8 working days | 2026-08-26 | 2026-09-25 | Quoted online
PCB fab, 2 layer ENIG | Eurocircuits | 25 | 11.80 | 0 | 5 working days | 2026-08-26 | 2026-09-26 | Quoted online
PCB fab, 2 layer ENIG | JLCPCB | 100 | 1.94 | 0 | 8 working days | 2026-08-26 | 2026-09-25 | Quoted online
Assembly, top side only | JLCPCB | 25 | 3.60 | 6.40 | +3 working days | 2026-08-26 | 2026-09-25 | Quoted online
Assembly, top side only | Aisler | 25 | 9.10 | 0 | +7 working days | 2026-08-27 | 2026-09-10 | Quoted online
Enclosure, SLS nylon | Protolabs | 25 | 14.70 | 0 | 7 working days | 2026-08-27 | 2026-09-26 | Quoted online
Enclosure, injection moulded | Protolabs | 100 | 2.85 | 4820.00 | 25 working days | 2026-08-28 | 2026-10-12 | Quoted | engineer reviewed
Enclosure, injection moulded | Xometry | 100 | 3.10 | 3950.00 | 30 working days | 2026-08-28 | 2026-09-28 | Quoted online
Probe lead, moulded 4-pin 1 m | Unsourced | 25 |  |  |  |  |  | Estimated at 6.00 from a similar part
Test fixture, bed of nails | Unsourced | 1 |  |  |  |  |  | Estimated at 400 from the last project

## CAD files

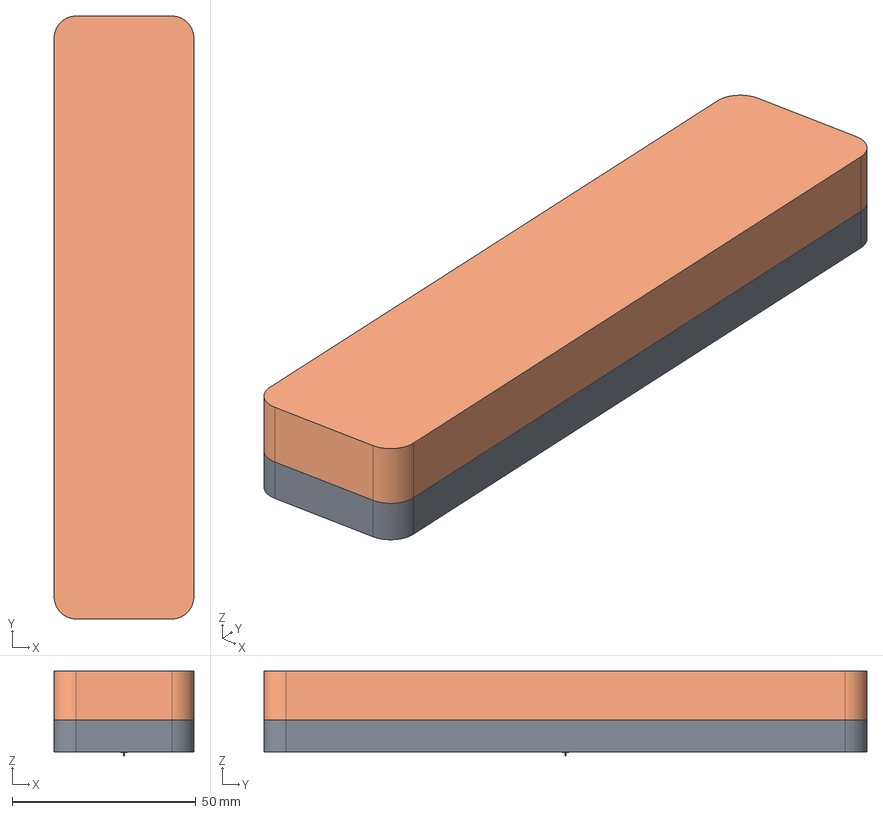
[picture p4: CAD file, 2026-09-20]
examples/thermal-probe/docs/design/cad/enclosure.step
38.0 x 164.0 x 23.0 mm
lid
pcb
cell

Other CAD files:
examples/thermal-probe/docs/design/cad/enclosure.3mf
examples/thermal-probe/docs/design/cad/enclosure.stl

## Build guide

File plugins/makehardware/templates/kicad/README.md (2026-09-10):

# House KiCad templates

Copied into a project by `/hw-new-project`. Two files, and one trap.

## `makehardware.kicad_wks` — the drawing sheet

A3 frame, zone rulers, and a title block at the bottom right carrying the
company, the project title, the sheet name and hierarchical path, the source
filename, the date, the revision and *sheet n of m*. Every field is a KiCad
text variable, so nothing in this file is ever edited per project: set Title,
Revision, Date and Company in Page Settings and they appear here.

The last line of the frame says the drawing is generated and points at the
source. That is not decoration — a reader who thinks a drawing was drawn by
hand will edit the drawing, and the edit will be gone on the next render.

Install it:

```bash
cp "${CLAUDE_PLUGIN_ROOT}/templates/kicad/makehardware.kicad_wks" hw/
kicad-cli sch export pdf hw/probe.kicad_sch \
    --drawing-sheet hw/makehardware.kicad_wks --output build/check.pdf
```

Then point the project at it permanently, either in Page Settings or as
`schematic.page_layout_descr_file` in the `.kicad_pro`.

**The trap: a bad drawing sheet fails silently.** KiCad's page-layout parser is
not the same parser as the rest of the S-expression files — it rejects `;;`
comments, and on any parse error `kicad-cli` prints one line to stderr,
**still exits 0**, and plots with the built-in sheet instead. So a broken
template produces a perfectly good-looking PDF with the wrong frame on it. That
is why this file carries no comments, and why the check above is worth running
once after any edit:

```bash
grep -c MakeHardware build/check.pdf     # 0 means the template did not load
```

## `house-defaults.json` — grid, sizes and net classes

Merged into the project's `.kicad_pro`, which is plain JSON. Every number in it is one that
`sch-lint` or `pcb-lint` checks, so if you change one here, change the gate's
default with it — a house standard and a gate that disagree is worse than
neither.

The net-class widths deserve their own note. They are set to values a router
can physically enter a pad with, not to final current-carrying widths. A
`Power` class at 1.20 mm against a 0.25 mm QFN pad is not an error and not a
DRC violation; it is simply unroutable, and it presents as a router returning
almost every connection as a failure with no explanation. Route at the widths
here, then widen the power nets and re-run DRC. `final_track_width_mm` records
what the widening has to reach. See
`hw-verification/references/pcb-layout.md` §1.

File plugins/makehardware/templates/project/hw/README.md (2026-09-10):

# Electrical design

| File | What it is |
|---|---|
| `block-diagram.yaml` | the architecture spec — **the only file here you hand-edit** |
| `block-diagram.drawio` | generated; open in draw.io to rearrange, positions are kept |
| `*.kicad_sch`, `*.kicad_pcb` | KiCad project — change these through KiStack (live IPC, or the file with a re-render after), never with `sed` |

The block diagram is settled before schematic capture. See the
`hw-block-diagram` skill; run `block-diagram --check` before calling the
architecture agreed.

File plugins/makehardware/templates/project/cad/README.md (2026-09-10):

# CAD

build123d models. Each file defines the geometry as code so a changed number is
a re-render, not a redraw.

**Model an assembly, not a solid.** Every part gets a `label` and a `color`,
and parts are positioned by `Joint`s rather than by `.move()` — a joint is a
relationship and survives a changed dimension, a coordinate does not. Expose
the whole thing as `ASSEMBLY`.

```bash
cad-export cad/enclosure.py --check      # the gate: labels, colours, joints
cad-export cad/enclosure.py --out docs/design/cad --name enclosure
```

That writes the STEP (AP242, assembly tree, part names, colours, and a named
datum at every joint), a GLB for the review page's orbit viewer, an STL for
GitHub's own 3D viewer, a 3MF for print, `joints.json`, a FreeCAD 1.0 macro
that rebuilds the assembly with **real, draggable joints**, and the renders:
assembled, exploded, sectioned and isometric.

STEP carries the tree, the names, the colours and the placement. It does not
carry mates — no CAD tool imports STEP kinematics today. That is what the JSON
and the macro are for. See the `hw-cad` skill.

Link each model back to the requirement it realises with a `File` relation in
`requirements/`.

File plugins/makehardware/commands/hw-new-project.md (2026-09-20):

---
description: Scaffold a new hardware project repository with the MakeHardware workflow structure
# scaffolds a repository, writes files and makes the first commit,
# so it runs when a person asks for it and never on the model's own initiative.
disable-model-invocation: true
---

Set up the current repository for the MakeHardware workflow.

Copy the scaffolding from `${CLAUDE_PLUGIN_ROOT}/templates/project/` into the
repository root, skipping anything that already exists — never overwrite the
human's work:

```
.claude/settings.json     declares the plugins (see step 1)
.env.example              image API keys, if you use a keyed provider
plan.yaml                 project plan (renders into the README)
requirements/             StrictDoc tree + hardware grammar
concepts/                 build123d concept modules for the vision stage
cad/                      design models
hw/                       block-diagram spec + the KiCad project
sim/                      SPICE decks and results
docs/reference/           external datasheets and app notes + manifest.yaml
docs/design/              ADRs, architecture, vision doc, verification report
docs/review/              human sign-off ledger and review packets
docs/user/                manuals and the product spec sheet
strictdoc.toml
CLAUDE.md                 project-level agent instructions
```

Then:

1. Confirm `.claude/settings.json` declares both plugins. It must declare this
   one, or the session would not have loaded this command — but check that
   `kicad-happy` is there too, and add it if not:

   ```json
   {
     "extraKnownMarketplaces": {
       "makehardware": {
         "source": { "source": "github", "repo": "Harwasch/MakeHardware" }
       },
       "kicad-happy": {
         "source": { "source": "github", "repo": "aklofas/kicad-happy" }
       }
     },
     "enabledPlugins": {
       "makehardware@makehardware": true,
       "kicad-happy@kicad-happy": true
     }
   }
   ```

2. Add the plan markers to the README if it has none, so the chart has
   somewhere to render:

   ```
   <!-- PLAN:BEGIN -->
   <!-- PLAN:END -->
   ```

3. Ask the human for the project name and which disciplines apply
   (`mechanical`, `electrical`, `firmware`, `software`, `test`,
   `manufacturing`, `documentation`) and write them into `plan.yaml`. Delete
   the example chunks — they are illustrative, not a starting plan.

4. Replace the example requirements in `requirements/` with empty documents
   that keep the grammar import, and strip `hw/block-diagram.yaml` back to the
   project name with empty `rails`, `blocks` and `buses`. The example widget is
   there to show the shape of the file, not to be edited into a real design.

5. Scaffold the review page's config, which is what decides the human ever
   sees the design stages:

   ```bash
   review-artifact --init      # writes docs/review/artifact.yaml
   ```

   Vision, plan, requirements and architecture are built from the repo and
   need nothing. Every design stage — schematic, layout, enclosure,
   simulation, the release checklist — appears **only if it is listed there**,
   so the file arrives with all of them written out and the ones whose
   artefacts do not exist yet commented. Turning one on later is uncommenting
   three lines; noticing it was never there at all is much harder.

6. Install the house KiCad settings, so the first schematic is drawn on the
   right grid inside the right frame rather than being fixed afterwards:

   ```bash
   cp "${CLAUDE_PLUGIN_ROOT}/templates/kicad/makehardware.kicad_wks" hw/
   ```

   Then point the project at it — Page Settings → Drawing sheet, or
   `schematic.page_layout_descr_file` in the `.kicad_pro` — and load
   merge `templates/kicad/house-defaults.json` into the `.kicad_pro`, which
   is plain JSON. Check the sheet actually took: a bad `.kicad_wks`
   makes `kicad-cli` print one line to stderr, **still exit 0**, and plot with
   the built-in frame, so a broken template yields a good-looking PDF with the
   wrong sheet on it. `templates/kicad/README.md` has the one-line check.

7. Run `hw-doctor` and `imagegen --list` and report what the
   environment can actually do, so the human knows up front if KiCad or a
   simulator is missing.

8. Confirm the repository has a **remote on github.com** — `git remote -v`.
   The whole review mechanism links the human at
   `https://github.com/<owner>/<repo>/blob/<branch>/...`, and without a remote
   `review-gate` can only print paths. If there is no remote, say so now
   rather than at the first review.

Do **not** invent a vision, a plan or requirements here. Scaffolding creates
the empty structure; `hw-vision` fills the first of it, with the human.

Then say plainly how the workflow will run: each of the first four stages —
vision, plan, requirements, architecture — and each large design stage ends
with an artefact committed to this repository and **a question put to them
with a link to it**, and nothing moves on until they answer. That is worth
saying once at the start, because it sets the expectation that they will be
interrupted, which is the point.

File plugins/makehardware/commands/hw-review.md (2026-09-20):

---
description: Put the current stage in front of the human for review - build the artefacts they can see on GitHub, ask them directly with a link, and record the sign-off
# commits, pushes and puts a request in front of a human,
# so it runs when a person asks for it and never on the model's own initiative.
disable-model-invocation: true
---

Run a human review for `$ARGUMENTS` (a milestone id — `vision`, `plan`,
`requirements`, `architecture` — or a design stage id such as `schematic`,
`layout`, `enclosure`). With no argument, report where every review stands and
ask which one to open.

Follow the `hw-review` skill. The short form:

1. **See where things stand.**

   ```bash
   review-gate list
   ```

   A review that is `stale` is the urgent one: the human agreed to something
   and it has since changed.

2. **Build the artefacts they can actually open.** The human is in a browser
   on github.com, not at this terminal. Refresh whatever this stage owns:

   ```bash
   plan-render          # docs/plan.md, docs/plan.svg, docs/plan.drawio
   req-trace --map      # docs/design/requirements-map.svg
   block-diagram        # docs/design/block-diagram.svg
   ```

   and for a design stage, export a PDF or a PNG per
   `hw-review/references/exports.md` — a `.kicad_sch` or a `.step` is a
   download, not a review.

   **Look at what you produced before you send it.** Half of what the review
   would catch, you will catch here.

3. **Rebuild the review page and look at it.**

   ```bash
   review-artifact --init     # once per project: writes docs/review/artifact.yaml
   review-artifact            # rebuild docs/review/artifact.html from the repo
   review-artifact --check    # exits 1 and names anything it cannot show
   ```

   `--check` is not optional. An export that failed leaves no file and an
   oversized render cannot be embedded; both are reported on the page rather
   than dropped, but a page with "not shown here" boxes on it is not a review
   and the human is the most expensive place to find that out.

   Then publish it with the **Artifact tool**. One project has **one** page:

   ```bash
   review-artifact --url https://claude.ai/code/artifact/<id>   # first time only
   ```

   records it in the ledger, and every later run prints that URL back so you
   pass it as `url` and update in place. Publish without it and the human ends
   up with two review pages showing different things.

4. **Commit and push.** A link to an uncommitted file is a 404.

5. **Open the review**, tracking what they are agreeing to and referencing
   what merely churns:

   ```bash
   review-gate open <id> --title "..." --summary "..." \
       --artifact <the thing that renders> \
       --reference <the source file> \
       --question "..." --question "..."
   ```

6. **Ask them directly, with the link.** Use `AskUserQuestion` — not a
   paragraph at the end of a message. Put the github.com URL of the review
   packet in the question, lead with the decision you need, name the thing
   you are least sure about, and offer real alternatives with their
   consequences rather than yes/no.

7. **Block on the answer.** Do not start the next stage. Work on something
   genuinely independent if there is any, and do not answer the question
   yourself.

8. **Record it in their words** and commit:

   ```bash
   review-gate sign <id> --approve --by <name> --note "<what they said>"
   review-gate sign <id> --changes "<what they want different>"
   ```

   On changes: make them, re-run step 2, and ask again.

9. **Confirm the gate is clear** before marking anything done:

   ```bash
   review-gate check --gate
   plan-render --check
   ```

Do not sign a review on the human's behalf, do not infer approval from
silence or from a message about something else, and do not mark a chunk
`done` while its review is open or stale. An artefact the human has not seen
is not a deliverable.

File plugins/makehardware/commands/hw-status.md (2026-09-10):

---
description: Report project status - plan progress, requirements coverage, and what is ready to work on next
---

Give the human an honest status report on this project. Run all three, and
report what they say rather than a summary impression:

1. **Reviews** — `review-gate list`. This goes first because it is the one
   that blocks other people rather than you.
2. **Plan** — `plan-render --summary`, then `plan-render` to refresh
   `docs/plan.{svg,md,drawio}` and the README block so the chart is not stale.
   `plan-render --check` for `done` chunks whose outputs or reviews are
   missing.
3. **Requirements** — `req-trace` for coverage and gaps, and `req-trace --map`
   to refresh the requirements map.
4. **Architecture** — if `hw/block-diagram.yaml` exists, `block-diagram
   --summary` for the power budget, and `block-diagram` to refresh the diagram
   and the review image if the spec is newer than them.
5. **Design checks** — if a KiCad project exists, `kicad-cli sch erc` and
   `kicad-cli pcb drc` against the *current* files.
5b. **Design loops** — `hw-iterate list`. A loop still `running` is unfinished
   work nobody can see; one that closed `escalated` is a decision waiting on the
   human that may never have been asked. Re-render the evolution chart for any
   loop whose ledger is newer than its SVG.
6. **The review page** — `review-artifact` to rebuild it from everything the
   steps above just refreshed, then `review-artifact --check`. A status run is
   exactly when the page goes stale, because the numbers on it come from files
   the earlier steps have just rewritten.

Then report, in this order:

* **What the human owes an answer on** — every review that is `requested` or
  `stale`, with the github.com link. A stale review is the urgent one: they
  agreed to something and it has since changed underneath them. If the page
  moved, republish it to the URL `review-artifact` prints and give them that
  link too — it is the one they will actually open.
* **What is blocked**, and on what.
* **What is ready to start now** — chunks whose dependencies are all done.
* **Requirements coverage**, as the number the gate prints. If it is 60%, say
  60%.
* **Any rail over or near its budget**, with the largest contributors. A rail
  at 95% is worth saying out loud even though the gate passes.
* **What changed** since the last report, if you can tell.

Commit the refreshed artefacts. A status report whose chart is a week old is
worse than none.

Lead with gaps, not with the percentage complete. Do not describe the project
as on track while the gate is failing, a chunk is blocked, or a milestone
review is unsigned — name the blocker and what it would take to clear it. A
stage whose review has never been requested is not done, however much of its
work is finished.

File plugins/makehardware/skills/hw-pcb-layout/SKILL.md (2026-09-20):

---
name: hw-pcb-layout
description: House practice for laying out a board that works and can be reviewed - placement order, stackup and reference planes, decoupling geometry, return paths, silkscreen an assembler can read - plus pcb-lint, the pre-route gate that measures it. Use before placing footprints, while placing or re-placing them, before routing, before generating fabrication output, and when asked whether a board is ready or why a router will not route it. KiStack's kicad-layout does the placing and routing; this decides where things go and what has to be true before a track is drawn, and wins where the two disagree.
---

# Laying out a board

A schematic that is right can still produce a board that does not work, and
the failures are geometric: a decoupling capacitor twelve millimetres from the
pin it serves is not a decoupling capacitor, a signal layer with no reference
plane beside it has no return path, and a via array under an exposed pad lands
on whatever is opposite.

None of those are DRC errors. DRC checks that the copper obeys the rules you
gave it; it has no opinion about whether the rules or the placement were any
good. That is what this skill and `pcb-lint` are for.

```bash
pcb-lint hw/probe.kicad_pcb                     # the report
pcb-lint hw/probe.kicad_pcb --gate              # exit 1 on any ERROR
pcb-lint hw/probe.kicad_pcb --svg docs/design/pcb-lint.svg
pcb-lint hw/probe.kicad_pcb --keepout J5=6.60   # check a constant against the part
```

The `--svg` is the board drawn at 1:1 with every finding numbered on it and
every decoupling loop drawn as a coloured line with its length written beside
it. That is the picture a layout review actually needs; a render shows a human
nothing they can act on.

**Net classes are not in the `.kicad_pcb`.** They are in the sibling
`.kicad_pro`, under `net_settings.classes`. This is worth knowing before you go
looking: a script that searches the board file for them finds nothing and
concludes the board is fine.

## Order of work, and why this order

1. **Stackup first, before a single footprint.** Layer count, which layers are
   planes, and what each signal layer references. Changing it later re-routes
   the board.
2. **Board outline, mounting holes, keepouts and connectors.** These are
   mechanical constraints from the enclosure, not layout choices — read the
   dimensions from `cad/`, never from memory.
3. **Check the net classes against the footprints, before placing.** Arithmetic,
   one minute, and it is what stands between you and a router that returns
   almost every connection as a failure. `pcb-lint --only PCB-TRACKW,PCB-CLEAR`.
4. **Place by function, in the same groups as the schematic sheets.** Power
   input to regulator to load, following the current. Sensitive analogue away
   from switching nodes. The board should be recognisably the block diagram.
5. **Place decoupling with its IC, not after.** Cap on the same side, against
   the pin, ground via at the cap's ground pad. This is placement, not routing.
6. **Run DRC on the placed, unrouted board.** Before a single track. It found
   721 errors on one board, three of them real, and every one of those three
   would otherwise have been found after routing, when fixing it means
   re-routing.
7. **Route the critical nets by hand** — switching node, feedback, crystal,
   differential pairs, anything with a current spike in it. Then the rest.
8. **Pour, re-run DRC, then `pcb-lint --gate`, then look at the render.**

## The rules `pcb-lint` measures

| Code | Rule | Section |
|---|---|---|
| `PCB-THERMVIA` | A `_ThermalVias` footprint's via array must not land on opposite-side copper on another net | §3 |
| `PCB-TRACKW` | A net class track width must fit the narrowest pad on its nets | §1 |
| `PCB-CLEAR` | A net class clearance must be smaller than the pad gaps inside its own footprints | §1 |
| `PCB-KEEPOUT` | A keepout radius must come from the footprint, not from memory | §4 |
| `PCB-DECAP` | Decoupling loop length, ranked worst first | — |
| `PCB-SILK` | No silkscreen crossing a pad | — |
| `PCB-REFTEXT` | A reference designator an assembler can read | — |
| `PCB-COURTYARD` | No overlapping courtyards, by real polygon area | §5 |
| `PCB-REFPLANE` | Every signal layer next to a reference plane | — |

Sections are in `hw-verification/references/pcb-layout.md`, which is where the
diagnosis stories live. Read it once; every one of those hours was spent
looking somewhere else first.

## The rules nothing measures, which you have to hold

**Return current follows the signal, not the schematic.** Above a few
kilohertz, return current runs directly under its trace in the nearest plane.
So a gap or a slot in the plane under a fast signal is a loop the size of the
detour, and it radiates. Never route a fast signal across a plane split.

**Every layer change is a return-path change.** A signal that vias from one
layer to another needs its return to via too — a ground stitching via next to
the signal via, within a couple of millimetres. Without it the return goes the
long way round.

**Decoupling is a loop, not a distance.** The loop is IC power pin → cap →
cap's ground pad → ground via → plane → back to the IC's ground. Shortening
the power side and leaving 8 mm of ground return achieves nothing.
`pcb-lint` reports both halves separately for that reason.

**Place the small capacitor closest.** A 100 nF at 1 mm and a 10 µF at 5 mm,
not the other way round. The small one is the high-frequency one, and it is
the one that cares about the millimetre.

**Analogue and switching share a board, not a return path.** Keep the
switching-converter loop — input cap, switch, inductor, output cap — physically
tiny and on one side, and keep the analogue ground referenced away from it.

**Silkscreen is for the human who assembles and debugs the board.** Reference
designators outside the courtyard, readable from one direction, pin 1 marked on
every polarised part, connectors labelled with what they connect to. A board
with hidden refdes is a board nobody can find a part on.

**Test points are a design feature.** Every rail, every reset, every bus, and
the ground next to them. Add them at placement, not after bring-up fails.

## Then look at it

```bash
kicad-cli pcb drc hw/probe.kicad_pcb --output docs/design/drc-report.rpt \
    --severity-error --severity-warning
kicad-cli pcb render hw/probe.kicad_pcb --output docs/design/pcb-top.png \
    --side top --quality high --width 1600 --height 1200
kicad-cli pcb render hw/probe.kicad_pcb --output docs/design/pcb-bottom.png \
    --side bottom --quality high --width 1600 --height 1200
```

Both sides, always — the opposite side of a board is where the surprises are.
Put the DRC count in the review as a number, and the stackup as a table. See
`hw-review/references/exports.md`.

Board edits go through the **`kicad-python` IPC bindings** where a KiCad is
running (`hw-kicad-up`) — KiStack's `kicad-layout` says to prefer them wherever
they are available — and through the board file otherwise. Never text-edit a
`.kicad_pcb`. Save each milestone back to the project's canonical board rather
than to a staging copy. `pcb-lint` only ever reads.

## When a board step fails mid-layout

`hw-schematic/references/kicad-channels.md` has the recovery list. The short
version: check `kicad-cli version` is 10.x and that you are on the project's
canonical board; a failed IPC connect means no KiCad is running, so
`hw-kicad-up` or work the file directly; and `hw-repair kicad` if the KiStack
pack itself is missing. `kicad-cli pcb` can do your DRC, your Gerbers and your 3D
render directly, but it cannot place or route anything — there is no headless
authoring CLI to fall back to.

## The board documentation gate

The nine layout rules ask whether the board works. Four more ask whether
anybody can build, stuff, test and trace it — the half a contract manufacturer
and a bring-up engineer see first, and the half that is invisible until the
boards arrive and nobody can tell rev B from rev C.

```bash
pcb-lint hw/board.kicad_pcb --only PCB-IDENT,PCB-FIDUCIAL,PCB-TESTPOINT,PCB-PIN1
```

| | what it wants, and why |
|---|---|
| `PCB-IDENT` | A part number and a revision **in silkscreen**, plus a serial and a date/lot field. A bare board with nothing printed on it cannot be told from the previous spin the moment it leaves its bag, and every later question — which rev is this fault on, which build shipped — becomes guesswork. The fab will not add it and it costs nothing now. |
| `PCB-FIDUCIAL` | Three global fiducials, not collinear, and one on the back if anything SMD is placed there. Two fix translation and rotation; the third resolves scale and mirror; three in a row resolve nothing. Without them the placer registers on the board outline, which is routed to a looser tolerance than the copper. |
| `PCB-TESTPOINT` | Every rail and bring-up signal reachable with a probe. A through-hole pad counts. A rail whose only copper is under a QFN gets probed by soldering a wire to a via, which is how a first article dies on the bench. |
| `PCB-PIN1` | A silkscreen polarity mark within 2 mm of pin 1 on every polarised part — not in copper, where the part covers it, and not only in the assembly drawing, which the operator correcting a reel at 2 am does not have. |

`PCB-PIN1` looks for silkscreen geometry near pin 1 and is honest about being
a proxy for a real marker. It is right far more often than it is wrong, and
the failure it catches — a part that was never marked at all — is the one that
costs a build.

**Go further than the gate.** It checks what can be computed; the bar is what
a good board carries. Connector orientation and mate direction on silk. A
polarity legend beside every electrolytic and diode. Net names at test points
so a probe does not need the schematic. Mounting holes with their keepout
drawn. A "do not populate" convention that survives the BOM. An orientation
arrow. None of that is enforced and all of it is noticed.

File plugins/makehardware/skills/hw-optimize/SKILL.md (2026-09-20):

---
name: hw-optimize
description: Run a design as a closed verify-and-refine loop - change a value, simulate it, read the number, change the next thing - and record every pass so the review shows how the design moved rather than only where it landed. Use whenever a target has to be met rather than merely computed (a margin, a temperature rise, a loss, a fit, a cost), whenever a first attempt misses, before reporting that a design meets a requirement, and whenever asked to optimise, tune, converge or "get it to" a number.
---

# The closed design loop

An agent handed *"get the phase margin above 60 degrees without losing the
1 MHz bandwidth"* does not solve it in one pass. It changes a value, simulates,
reads the result, changes the next thing, and repeats. That loop is where
almost all of the engineering happens — and by default none of it survives.
The repository ends up holding the last netlist and a sentence claiming a
number.

That is a bad trade for everyone:

* The human cannot tell a **converged** design from one that **ran out of
  budget**. Both report a number.
* The next session re-explores knobs this one already found useless.
* The trade the loop made is invisible. The objective climbed; what slid?

So the loop is recorded as it runs, in the file that renders as its chart.

## The loop

```
       goal from a human or an orchestrator
                    |
                    v
        +---> change ONE thing ----+
        |                          |
        |                          v
        |                   the verifier runs
        |                (ngspice, Elmer, FastHenry,
        |                 build123d measure, sch-lint...)
        |                          |
        |                          v
        |                   hw-iterate run
        |              (runs it, extracts, records)
        |                          |
        +--- not there yet <-------+
                    |
              target met, or
              plateaued, or
              out of options
                    |
                    v
            hw-iterate close
            hw-iterate chart  --> the review
```

### 1. Open the loop, and say what "better" means

```bash
hw-iterate open loop-gain \
    --goal "phase margin >= 60 deg without giving up the 1 MHz bandwidth" \
    --objective pm_deg --direction max --target 60 --unit deg \
    --track bw_hz --track-limit bw_hz=1M --track-direction bw_hz=max --track-unit bw_hz=Hz \
    --track iq_ua --track-limit iq_ua=250 --track-direction iq_ua=min --track-unit iq_ua=uA \
    --tool ngspice
```

**`--track` is the important half.** An objective on its own is a licence to
wreck everything else to satisfy it, and a loop that does exactly that looks
like a success from the inside. Name what the objective is not allowed to cost
*before* you start optimising, while you still have no stake in the answer.

If you cannot say what the target is, you do not have a loop — you have an
open question, and that goes to the human now, not after ten iterations.

### 2. One pass: run it, and let the tool read its own numbers

```bash
hw-iterate run loop-gain \
    --cmd "ngspice -b sim/loop.cir" \
    --var Cc=22p --var Rz=1k5 \
    --metric pm_deg=meas:pm --metric bw_hz=meas:bw --metric iq_ua=meas:iq \
    --note "zero in series with Cc buys the margin without the bandwidth"
```

`run` executes the verifier, keeps its output as the evidence file, reads each
number out with a named extractor, and records the pass — one call, and no
number passes through your hands.

**Never type a measured number into `--metric`.** That is what the extractors
are for:

| | reads |
|---|---|
| `meas:NAME` | an ngspice `.meas` or `print` line — the default form |
| `line:PREFIX` | the number after a literal prefix, e.g. Elmer's `ElectroMagnetic Field Energy:` |
| `json:a.b.c` | a dotted path — build123d `measure()`, `req-trace --json` |
| `csv:COL[:how]` | a column reduced by `last`/`max`/`min`/`mean`/`absmax` |
| `re:PATTERN` | first capture group, for anything else |

`hw-extract <file> --metric ...` runs one on its own, which is how you get the
spec right before wiring it into a loop.

* **The verdict is derived, not asserted.** With a `--target`, `run` decides
  pass/fail from the objective. Override with `--verdict` only when the number
  is not the whole story, and say why in `--note`.
* **Every number is re-derivable.** `hw-iterate verify` re-reads each recorded
  figure from the file it came from, and `status --gate` fails the loop if one
  no longer reproduces. A deck edited after the run, an extractor that changed
  meaning, a figure someone typed — all of it surfaces here rather than on the
  review page.
* `record` still exists, and is right for a measurement with no machine-readable
  output: a bench reading, a scope photograph, a supplier's quoted figure. It
  takes numbers on the command line, and `verify` reports those passes as
  unverifiable rather than as wrong.
* **Run the passes that got worse, and keep them.** They are the ones that carry
  information — they say which direction is wrong, and they are what stops the
  next session repeating them. A ledger of only wins is a ledger nobody can
  check.
* **Change one thing at a time** where you can. Two knobs at once and the
  ledger cannot tell you which one did it, so neither can anyone else.
* Engineering notation is read as written: `22p`, `1k5`, `4R7`, `1M`.

### 3. Know when to stop

`hw-iterate record` tells you when the last three passes are within 2% of each
other. **That is the signal to change the approach, not to run a fourth
variation of the same idea.** Three tweaks of the same resistor that move the
objective by a tenth of a degree each are not progress; they are a loop
mistaking motion for work.

Stop when any of these is true:

| | Then |
|---|---|
| Target met | `close --status converged --accept N` and go to review |
| Plateaued below target | Change the *approach* — a different topology, a different mechanism. If you have no other approach, escalate with the chart. |
| The objective can only be met by breaching a `--track` limit | **Escalate.** That is a requirements conflict, not an optimisation problem, and it is not yours to resolve. |
| Out of ideas | `close --status escalated`, and say what you tried |

Accept the pass you would actually build, not the highest number. Taking #4
when #6 scored a fraction higher — because #6 needs a part variant nobody
stocks — is a judgement, and the chart shows both so the reviewer sees you made
it.

### 4. Put the trajectory in the review

```bash
hw-iterate chart loop-gain --out docs/design/loop-gain-evolution.svg
review-gate open loop-gain --title "Loop compensation" \
    --summary "60 deg needed a zero, not more Cc. #4 accepted: 66 deg, 1.35 MHz." \
    --artifact docs/design/loop-gain-evolution.svg \
    --question "Take 66 deg at 1.35 MHz, or push for margin and drop below 1 MHz?"
```

The chart shows the objective against its target, each tracked metric against
its own limit, and a strip of which variable moved on which pass. A reviewer
reads three things off it in a second that no paragraph delivers: that it
converged rather than stopped, which change bought the improvement, and what it
cost elsewhere.

## Perseverance and escalation

The two failure modes are symmetric and both are expensive. An agent that stops
at the first obstacle wastes the human's time on things it could have solved.
An agent that never stops burns a day building the wrong thing confidently.

**Push through, without asking, when the problem is in your way:**

* **A tool is missing or broken.** `hw-doctor`, then `hw-repair`. Elmer absent
  is ninety seconds, not a blocker. A missing KiStack pack is
  `hw-repair kicad`. See `hw-schematic/references/kicad-channels.md` for the
  KiCad failure list.
* **A tool fails on one input.** Read the error, read the log
  (`/opt/makehardware/logs/`, `hw-doctor`), try the documented
  alternative. Most of these tools name their replacement in the failure.
* **A solve does not converge, a mesh is bad, a netlist errors.** That is
  ordinary work. `hw-magnetics`, `hw-simulation` and the lint references carry
  the known traps for exactly this reason.
* **The first approach did not work.** Try the second. Three genuinely
  different approaches before you call something hard.
* **You do not know a number that is written down somewhere.** Fetch the
  datasheet. Never ask a human for a figure a document has.

**Stop and ask, before doing the work, when the decision is the human's:**

* **A trade between things they said they wanted.** Margin against bandwidth,
  cost against size, one requirement against another. You cannot rank their
  priorities from the brief, and guessing is how a project builds the wrong
  product correctly.
* **Anything expensive or hard to reverse** — ordering parts, generating fab
  output, committing to a package, a process or a supplier.
* **A number that was agreed, moving.** Re-open the review; do not quietly
  update it.
* **Two readings of the brief lead to different hardware.**
* **The work turns out much bigger than the plan said.** The plan is an
  agreement too.

**The line:** it is a decision if a well-informed human could reasonably
disagree with either answer. It is an obstacle if there is a right answer and
you simply have not found it yet. Obstacles are yours.

**When you do escalate, escalate with work behind it.** Not "the loop did not
converge" but the chart, the three approaches you tried, what each cost, and
the two options you want ranked. An escalation is a decision request with
evidence attached — which is the same standard as any other review, and it is
what makes an interruption worth the human's attention.

**Never fake convergence.** Reporting a target as met when the loop plateaued
below it is the one failure this whole mechanism exists to prevent.
`hw-iterate status --gate` exits 1 on it, and so should you.

## Where the verification comes from

The loop is only as good as the thing closing it. Match the verifier to the
claim:

| The claim | Closed by |
|---|---|
| bias point, gain, margin, noise, transient | `hw-simulation` — ngspice through the spice MCP server |
| L, M, k, Q, R_ac, B field, force | `hw-magnetics` — FastHenry for air-core, Elmer for anything with a core |
| fit, clearance, mass, volume, interference | `hw-cad` — build123d `measure()`, and `compare()` between snapshots |
| thermal rise | Elmer or CalculiX |
| readability, decoupling, DFM | `sch-lint`, `pcb-lint` — they are gates, and a gate is a verifier |
| requirement satisfied | `hw-verification` — the loop's accepted pass is the evidence, cited by path |

A loop whose "verifier" is your own judgement is not a loop. If nothing in the
toolbox can measure the thing, say so — that is a genuine escalation, and a
useful one.

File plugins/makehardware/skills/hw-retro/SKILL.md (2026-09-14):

---
name: hw-retro
description: Capture what went badly during hardware work and turn it into specific proposed edits to the MakeHardware toolbox. Use when a task took far more iterations than it should have, when the human corrects or overrules the agent, and at the end of a project or a milestone.
---

# Retrospective

The toolbox only improves if friction gets written down while it is still
fresh and specific. This skill has two granularities, and the cheap one matters
more than the ceremonial one.

## 1. The friction log — during the work

Append to `docs/design/friction-log.md` **in the session it happens**, when any
of these occur:

* the human corrects or overrules a choice you made
* something took markedly more loops than it should have
* you had to guess because information was missing
* a tool behaved differently than the skill said it would
* the human sounds frustrated, or repeats themselves
* **a review came back with changes** — what you built was not what they
  wanted, and the reason is the most useful sentence in the log
* **you got a long way without asking anyone** — if a stage finished with no
  review requested, that is a finding about the workflow, not just about you

One entry, three lines, no ceremony:

```markdown
## 2026-08-28 · E2 schematic capture
**Friction:** Picked a JST-PH connector; human wanted Molex PicoBlade. Third
time connectors have been relitigated across projects.
**Cost:** ~20 min and a re-layout of the board edge.
**Where it belongs:** skills/hw-sourcing/references/connectors.md — the
board-to-wire row is still a TBD placeholder.
```

That third line is the one that matters. **An observation without a named file
is not actionable.** If you genuinely cannot name a file, say so — that itself
is a finding, and it usually means the toolbox has no home for that kind of
knowledge yet.

Do not log ordinary iteration. Design is iterative; two passes at a value is
work, not friction. Log the loops that a better instruction would have avoided.

## 2. The project retro — at a milestone or at the end

Run `/hw-retro`. It reads the friction log, the plan (how estimates compared to
reality), the git history, and the requirements that moved, then writes
`docs/design/retro.md`.

Structure it as **evidence → proposed change**, never as sentiment:

```markdown
# Retro — Thermal Probe

## What worked
- Vision board with two concepts settled the form factor in one session.
  Keep.

## What cost time
### Connector choice was relitigated three times
**Evidence:** friction log 2026-08-28, 2026-09-02; commits a1b2c3, d4e5f6.
**Cost:** roughly one session.
**Proposed change:** fill in the board-to-wire row of
`skills/hw-sourcing/references/connectors.md` with Molex PicoBlade, and add
the reason (crimp tooling already owned).

### Plan underestimated PCB layout by 2 sessions
**Evidence:** E3 estimated 2, took 4.
**Proposed change:** `skills/hw-planning/SKILL.md` — note that layout chunks
on boards with a fixed enclosure envelope typically need double the estimate.

## What to leave alone
- The requirements gate caught two unverified leaves before fab. No change.
```

## Closing the loop

The retro lives in the *project* repo, but the changes it proposes are to
**MakeHardware**. Do not leave it there to rot.

### What counts as a system finding

The test is mechanical: **the edit changes a file in the plugin.** A finding
qualifies if you can name a path under `skills/`, `scripts/`, `references/`,
`templates/` or `env/` and say what it should say instead.

Not this: "the motor housing conducts 35% more heat through the bearing
carrier than we modelled." True, expensive, and about *this design* — it
belongs in an ADR. The system finding hiding next to it is "the thermal
skill never prompts for conduction through mounting hardware", and that one
names `skills/hw-magnetics/SKILL.md`.

### Record first, publish second

```bash
hw-feedback new --file skills/hw-sourcing/references/connectors.md \
    --title "Connector choice is relitigated every project" \
    --edit "Fill in the board-to-wire row with Molex PicoBlade, and say why" \
    --evidence "friction log 2026-08-28, 2026-09-02; commits a1b2c3, d4e5f6" \
    --cost "about one session" --kind "Missing guidance"
```

The friction log's third line — *where it belongs* — is exactly what
`--file` takes, so entries feed the tool directly.

This writes `docs/design/feedback/<date>-<slug>.md` in **this** repo and
commits with the work. It needs no network, no GitHub account and no
credentials, which is the point: the finding is cheapest to capture at the
moment it happens, and that moment is never one where somebody wants to open
a browser.

Then, at the retro:

1. Write `docs/design/retro.md` and commit it, along with the records.
2. Run `hw-feedback publish`. It prepares one issue for the batch and prints
   a link, a dedup search, and the body to paste.
3. **The human files it.** Unless the session happens to have a working `gh`
   channel to the plugin's repo, `hw-feedback` cannot — a cloud session's
   token is scoped to this project repo. It will say `NOT FILED`.
4. When they tell you the issue URL, `hw-feedback mark <slug> <url>` so the
   record knows where it went. A record whose `published:` stays empty
   forever is a finding that did not make it.

**Never report a prepared issue as filed.** "I've filed the issue" when what
exists is a URL is the most likely way this goes wrong, and it is the kind of
wrong nobody catches until they go looking for an issue that was never there.
Say "prepared", give the link, and wait.

If the human is working in the MakeHardware repo itself, offer to make the
edits directly instead — the record is still worth writing, because it is the
evidence the edit rests on.

## Be honest about your own performance

The point of this is not to produce a document that says things went well.
Name the places where you guessed, where you were wrong, and where the human
had to push back twice. Those are the entries with the most value in them, and
you are the only one who can see them all.

If nothing went badly, say that in a sentence and stop. A padded retro is worse
than a short one, because it dilutes the entries that matter.

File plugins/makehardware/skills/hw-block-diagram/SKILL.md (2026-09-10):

---
name: hw-block-diagram
description: Settle the electrical architecture as a functional block diagram before schematic capture - the major ICs, the power tree with a current budget, and the data buses - written as a spec that renders to an editable draw.io file and a review image. Use after requirements and before any schematic work, when asked for a block diagram or an architecture, when the power tree or a rail budget is in question, or when a new IC or bus is added to a design.
---

# Electrical block diagram

The block diagram is the architecture agreement. It comes **after requirements
and before schematic capture**, and it answers three questions that are
expensive to answer later:

* **What major parts exist?** The ICs, connectors and modules — not passives.
* **What powers each of them?** The whole power tree, with a current budget.
* **What talks to what?** The data buses, with their controllers.

Finding out during layout that the 3.3 V rail is 400 mA short is a respin.
Finding out here is an edit.

## The spec is the source of truth

`hw/block-diagram.yaml` is written by hand. Both outputs are generated from it,
so the editable file and the review image cannot drift apart:

| File | What it is |
|---|---|
| `hw/block-diagram.yaml` | the spec — **the only file you edit** |
| `hw/block-diagram.drawio` | editable diagram, opens in draw.io and the VS Code extension |
| `docs/design/block-diagram.svg` | the review image, renders inline on GitHub |
| `docs/design/block-diagram.png` | optional raster, for slides — `--png` |

```bash
block-diagram              # write all three, then print the power budget
block-diagram --check      # validate only; exit 1 on a broken tree or an over-budget rail
block-diagram --summary    # power budget per rail, no files written
block-diagram --png        # also rasterise
block-diagram --relayout   # discard hand-tidied positions and lay out fresh
```

Never hand-edit the `.drawio` or the `.svg` to change *content* — the next run
overwrites it. Moving blocks around in draw.io **is** fine and is the point:
positions are read back on the next run and reused, keyed by block id.

## What goes in, and what does not

**In:** ICs, regulators, connectors, modules, sensors, actuators, and anything
with a part number that a reviewer would ask about.

**Out:** decoupling caps, pull-ups, series resistors, test points. If it does
not appear in the power budget or on a bus, it belongs in the schematic, not
here. A block diagram with 60 blocks is a schematic drawn badly.

Aim for 6–25 blocks. If you have three, you have drawn a photograph of the
datasheet's typical application circuit.

## The power tree is the part that earns its keep

Every rail declares what makes it and what it can deliver; every block declares
what it draws. The tool then does the arithmetic you would otherwise do wrong:

```yaml
rails:
  - id: V3P3
    voltage: 3.3
    from: VBUS          # the rail that feeds it
    source: U2          # the block that converts it
    max_current_a: 2.0  # what the source can actually deliver

blocks:
  - id: U1
    name: MCU
    kind: mcu
    part: STM32H563ZIT6
    powered_by:
      - rail: V3P3
        typ_current_a: 0.11
        max_current_a: 0.28
```

A rail carries its own loads **plus everything drawn by the rails derived from
it, referred through the voltage ratio**. A child rail's amps are not the
parent's amps: 67 A at 48 V is 8.0 A off a 400 V input, so the roll-up
multiplies by `V_child / V_parent` and says so in the output.

Converter **efficiency** is deliberately not modelled — this is a headroom
check, not an energy model, and inventing a curve at an unknown operating point
would be worse than a conservative number. The referred current is therefore
the ideal one and is optimistic by exactly the converter's loss. If you need
the input-side number for a thermal or battery-life claim, work it out
explicitly and record it in an ADR.

`--check` exits 1 when a rail's max draw exceeds what its source can deliver,
and names the contributors largest first. Wire it into the same place you run
`req-trace --gate`.

### Currents come from datasheets

`max_current_a` is a number someone has to defend. Take it from the datasheet
at the operating condition you actually intend — not the typical at 25 °C when
you will run it at 85 °C, and not from memory. If the datasheet cannot be
fetched, record the block as blocked in `docs/reference/manifest.yaml` and ask
the human, exactly as `hw-documentation` requires. A budget built from guesses
that passes is worse than no budget, because it will be believed.

Declare peak, not average, unless there is a bulk capacitor sized to cover the
difference — and if there is, say so in the rail's `notes`.

## Buses

A bus with a `controller` and `members` draws as a shared spine; a two-block
link uses `between`. Put the thing that matters for layout in `notes` — the
clock rate, the number of chip selects, whether it is a differential pair.

```yaml
buses:
  - id: SPI1
    kind: spi
    controller: U1
    members: [U5, U6]
    notes: 10 MHz, two chip selects
  - id: USB2
    kind: usb
    between: [J1, U1]
    notes: full speed
```

`kind` is one of `usb i2c spi uart can ethernet i2s swd gpio analog rf`, which
sets the colour. Anything else still draws, in grey.

Two buses that are alternates for the same connection (an IMU wired for either
SPI or I2C) should both appear, with the choice recorded in `notes`. That is
real design information and it disappears the moment someone picks one.

## Reading the warnings

The tool distinguishes what is broken from what is suspicious, and only the
first kind is an error:

* *"nothing powers it"* — usually a missing `powered_by`, occasionally a block
  that genuinely runs off a bus, like a USB device.
* *"on no bus"* — either a missing bus or a block that should not be here.
* *"is higher than its parent"* — a step-up that is not declared as one. Almost
  always a typo in a voltage.
* *"no current declared"* — the block is invisible to the budget. Fix it or the
  budget is a lie by omission.

Do not silence a warning by deleting the block. Say what you found.

## Exit condition

Four things have to be true, and the first one is not a formality:

* **a human has looked at the image and agreed to it**, recorded in
  `docs/review/reviews.yaml`;
* every block has a part number, or an explicit "TBD" with the decision named
  as a chunk in `plan.yaml`;
* every rail has a declared limit, and `--check` passes;
* every current in the budget traces to a datasheet in `docs/reference/`;
* each requirement that constrains the architecture — a power budget, an
  interface, a part choice — has a `File` relation to
  `hw/block-diagram.yaml`, so `req-trace` can see it.

This is the cheapest artefact in the project that can be wrong in a way a
human can see. A page of boxes takes an hour to write and a minute to read,
and a reviewer will catch a missing rail or a bus on the wrong controller far
faster here than in a schematic. Not showing it to them wastes the entire
reason it exists:

```bash
block-diagram
git add hw/block-diagram.yaml hw/block-diagram.drawio docs/design/block-diagram.svg
git commit && git push

review-gate open architecture \
    --title "Block diagram, power tree and buses" \
    --summary "<the power budget headline: which rail is tightest and at what %>" \
    --artifact docs/design/block-diagram.svg \
    --reference hw/block-diagram.yaml --reference hw/block-diagram.drawio \
    --question "Is a rail or a part missing?" \
    --question "Is any bus on the wrong controller?"
```

Put the budget table in the summary as text. A rail at 95% of its limit is the
most useful fact in an architecture review and it is invisible in the picture.
Ask directly with the link, block on the answer, and `review-gate sign` it —
see `hw-review`.

Then, and only then, start schematic capture. KiStack builds the schematic; the
block diagram is what tells it what to build.

## When the design changes

It will. When a part changes or a rail moves, edit the spec and re-render **in
the same session** — a block diagram that disagrees with the schematic is worse
than none, because it is the document reviewers read first. If the change
invalidates a decision recorded in an ADR, update the ADR too; `hw-documentation`
covers how.

A re-render also makes the architecture review **stale**, and `review-gate
check` will say so. That is the mechanism doing its job: the human agreed to a
different diagram, and everything downstream is now resting on that agreement.
Re-open the review, say what changed and why, and ask again. It is a short
conversation.

## Put the budget in front of the human as a picture

`block-diagram --summary` prints the power budget as text, which is right for a
terminal and wrong for a review. A rail at 95% of its limit is the single most
useful thing in an architecture review and it is invisible in the diagram:

```bash
block-diagram --summary --csv build/rails.csv
hw-chart budget build/rails.csv --out docs/design/power-budget.svg \
    --title "Rail current against budget"
```

Bars inside their own budget outline, amber past 85%, red past 100% with the
overage named. Commit it beside `block-diagram.svg` and put both in the review.
See `hw-visuals`.

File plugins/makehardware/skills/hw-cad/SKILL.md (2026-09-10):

---
name: hw-cad
description: Model mechanical parts as a real assembly - labelled, coloured, held together by joints rather than by coordinates - and export files a human can open and manipulate in their own CAD tool. Use when modelling an enclosure, a bracket, a fixture or any multi-part mechanical design, when a CAD file has to go to somebody else, when asked for a STEP or a 3D model, and when a model needs a render, a section or an exploded view for review.
---

# Modelling for somebody else's CAD tool

The default way a model gets written is one `BuildPart`, one `PART`, one
`export_step`. What arrives at the other end is a solid: no part names, no
colours, no way to hide the lid and look inside, and nothing that says which
face mates to which. That is a screenshot with a file extension.

Two rules make the difference, and `cad-export --check` enforces both.

## 1. Model an assembly, and give every part a name and a colour

```python
shell = _shell.part
shell.label = "shell"                       # what it is called in the CAD tree
shell.color = Color(0.16, 0.20, 0.26)       # how a reviewer tells it apart

ASSEMBLY = Compound(children=[shell, lid, board, cell])
ASSEMBLY.label = "thermal-probe-enclosure"
```

Labels and colours survive the STEP, the GLB and the 3MF. Without them the
tree reads `Solid, Solid, Solid` and every render is one uniform colour, which
is the same as no render.

## 2. Position by joint, never by `.move()`

```python
RigidJoint("rim",  shell, Location((0, 0, DEPTH * SPLIT)))
RigidJoint("seam", lid,   Location((0, 0, 0)))
shell.joints["rim"].connect_to(lid.joints["seam"])
```

A joint is a *relationship*; a `.move()` is a coordinate. Raise `WALL` by
0.2 mm and every jointed part follows; a hand-placed part stays exactly where
it was and quietly ends up inside a wall. Nothing warns you, and the render
still looks fine. `cad-export --check` fails on a part no joint reaches, for
exactly that reason.

Use the joint that describes the real freedom: `RigidJoint` for something
bolted, `RevoluteJoint` for a hinge (with its angular range),
`LinearJoint` for a slide, `CylindricalJoint`, `BallJoint`. The type is what
gets written into `joints.json` and turned into a real FreeCAD joint.

## Export

```bash
cad-export cad/enclosure.py --out docs/design/cad     # everything
cad-export cad/enclosure.py --check                   # the gate, writes nothing
```

| File | For |
|---|---|
| `.step` | **The CAD deliverable.** AP242, assembly tree, part names, colours, placement, plus a named datum cross at every joint |
| `.glb` | The interactive viewer on the review page — node tree, names and colours preserved |
| `.stl` | GitHub's own 3D viewer, which renders `.stl` in the blob view and nothing else |
| `.3mf` | Print and mesh workflows, with part names and colours intact |
| `-joints.json` | Every joint: type, parts, position, orientation, axis, limits |
| `-freecad.py` | A macro that rebuilds the assembly in FreeCAD 1.0 **with real joints** |
| `-render.png`, `-exploded.png`, `-section.png`, `-iso.svg` | The pictures a review needs |

The exploded view slides each part along the axis of the joint holding it, so
it stays correct when the model changes. A hand-picked offset does not.

## The thing to be honest about: STEP carries no mates

STEP carries the tree, the names, the colours and the placement. It does
**not** carry editable constraints. AP242 edition 2 defines kinematics, OCCT
does not write them, and FreeCAD does not read them. Telling somebody
otherwise has them open the file expecting to drag the lid and find they
cannot.

So the constraints travel three other ways, and the review request should say
which one you mean:

1. **The build123d module is authoritative.** It is the only place the
   relationship survives a changed number.
2. **Named mate datums in the STEP.** Every joint is exported as a small
   labelled cross, `MATE_<part>_<joint>`, at its own location and orientation.
   A CAD user snaps a mate to a datum in three clicks instead of hunting for
   the right face on a part they did not model.
3. **`-freecad.py`.** Run it in FreeCAD 1.0 (Macro → Macros… → Execute) and it
   imports the STEP and builds real `Assembly::Joint*` objects from the JSON.
   That is the one path where the constraints are live and draggable.

FreeCAD is not installed here — Ubuntu 24.04 ships 0.21, which has no Assembly
workbench, and an AppImage would not fit the environment build budget. So the
macro is written for the human's own machine, and run automatically only if a
`freecadcmd` 1.0 or newer happens to be on `PATH`.

`references/assemblies.md` has the full format table and the mate-datum
convention.

## For review

Commit the renders and the STL — GitHub shows `.stl` in an interactive viewer,
so that is the one file a human can rotate without installing anything, and it
beats any static image. Say in the request that it is a review mesh.

Put the GLB on the review page, where `review-artifact` embeds it in a
pan-and-zoom viewer with the parts in their own colours.

A **cross-section is usually the most informative single image** of an
enclosure: it shows the wall thicknesses, the internal clearances and where the
board actually sits, which is the one view a 3D viewer will not give by
default. `cad-export` writes one every time.

## Working with the build123d MCP server

Where the `build123d` MCP server is available, build there — it keeps a live
session, so you can `measure()` after every boolean and `render_view()` to look
at what you just made, instead of re-running a script and hoping. Write the
finished model back out as a module with `ASSEMBLY` in it, and run
`cad-export --check` over that. The module is what gets committed and reviewed;
the session is scratch.

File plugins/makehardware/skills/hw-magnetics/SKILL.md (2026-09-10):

---
name: hw-magnetics
description: Field simulation - inductance, coupling, eddy and proximity loss, magnetic force - with FastHenry, Elmer, GetDP and Gmsh. Use when a coil, transformer, inductor, motor, magnet or wireless-power link needs L, M, k, Q, R_ac(f), a B field or a force, when a design has ferrite or a core in it, or when a magnetics geometry needs parameterising and sweeping. Not for circuit simulation - that is hw-simulation.
---

# Magnetics and field simulation

SPICE cannot tell you an inductance. These tools can, and each answers a
different question — picking the wrong one is the main way this goes wrong.

Run `hw-doctor` if a tool is missing; the environment build reports what it
managed to install. **A missing tool is not the end of the task.** If Elmer is
absent, `hw-repair elmer` installs it into this container in about ninety
seconds — do that and carry on, rather than reporting a degraded toolchain and
stopping. Only escalate if the repair itself fails, and then say which host it
could not reach.

## Which tool

| The question | Tool | Why not the other |
|---|---|---|
| L, M, k, Q, R_ac(f) of **air-core** conductors | **FastHenry** | PEEC: no air mesh at all. Seconds, against a 200k-element FEA of the same problem. |
| Anything with **ferrite, a core, a shield, or saturation** | **Elmer** | FastHenry is conductors only, µr = 1 everywhere. It has nothing to say about a core. |
| Frequency-domain eddy and proximity loss | **Elmer** harmonic | complex-valued A-v edge elements |
| 3-D magnetostatics, permanent-magnet machines | **Elmer** | PM and circuit support |
| Fast permanent-magnet field or force screening | **magpylib** | analytic, milliseconds, no mesh |
| Structural: contact, nonlinear, modal | **CalculiX** | Abaqus `.inp`, which agents write far more reliably than `.sif` |
| Meshing, for any of the above | **Gmsh** | Elmer has no geometry kernel and no mesher |
| **Core loss** | Python, iGSE/Steinmetz against the FEA B field | never a solver output; the coefficients are a datasheet number |

If the answer is FastHenry, take it. A ferrite-free coil problem that lands in
an FEA is an afternoon that should have been a minute.

## The shape of a study

A parametric study is **a Python driver that generates input, shells out to
the solver, parses the result and plots** — never a hand-edited input file.
That is what makes this stack agent-drivable and what lets a geometry fix
re-run an entire sweep. One module owns the geometry; the deck writer, the
mesher and the drawing all call it, so they cannot disagree about the part.

Refine until the answer stops moving, and record where that was. Two
discretisations usually converge from opposite directions — a mesh from below
and a filament count from above — so a single setting proves nothing.

## Cross-check before believing

Every result gets an independent check. Not another solver: a closed form.

| Case | Reference |
|---|---|
| Mutual inductance of coaxial loops | Maxwell's elliptic-integral formula |
| Planar spiral self-inductance | Mohan's current-sheet fit (±8 %) |
| DC resistance | ρL/A on the same geometry |
| Round-wire AC resistance | the Bessel-function ratio |
| Anything Elmer, air-core | FastHenry on identical geometry |

Solver defects here are **silent**. In the WPT coil demo, two of six were
caught by a cross-check disagreeing and none by an error message.

## FastHenry

```
.units mm
.default sigma=5.8e4          <- PER MILLIMETRE, because .units is mm
N1 x=.. y=.. z=..
E1 N1 N2 w=5 h=0.035 nwinc=8 nhinc=1 rw=2
.external N1 Nlast portname
.freq fmin=1.5 fmax=150e3 ndec=1
.end
```

Run it as `fasthenry -o4 deck.inp`.

* **`-o4` is not optional.** The multipole expansion defaults to order 2,
  which is 0.40 % low on a mutual inductance that has a closed-form answer.
  That error lands directly on k. Order 4 gives 0.016 %.
* **`sigma` is per `.units`.** `.units mm` means S/mm — 5.8e4 for copper, not
  5.8e7. Get it wrong and every resistance is 1000× too small while every
  inductance looks perfect.
* **`nwinc=1` returns R_ac exactly equal to R_dc**, with no warning. One
  filament cannot represent current crowding. If a trace is wide against the
  skin depth, converge `nwinc` or your Q is fiction. `nhinc` matters only when
  the conductor is thick against the skin depth — for 35 µm foil below a
  megahertz it is not.
* **`ndec` is points per decade.** `fmin=1 fmax=150e3 ndec=100` is 518 solves.
* **FastHenry can write `nan` and exit 0.** No error, a normal timing summary,
  a successful shell. The only symptom is `nan +nanj` in `Zc.mat`. **Always
  check the parsed matrix is finite** and treat a NaN as a failure. It needs
  `nwinc > 1` and depends on the exact geometry in a way that is not monotonic
  in anything; re-discretising rescues some cases and no filament setting
  rescues others. Fall back to `nwinc=1` with the result flagged as DC-only
  rather than dropping the point silently.
* **`Zc.mat` has a fixed name** in the working directory. Give every run its
  own directory or two drivers will read each other's answers, both plausible.

## Elmer

Do **not** author a `.sif` from scratch. Copy a working one:
`/opt/elmer-elmag` carries 24 worked cases including `CoilOnIronCore` and
`CoilWithFerriteCoreAndShield`; the Elmer source tree carries ~1000
regression tests, 72 of them magnetodynamics.

* **No `LD_LIBRARY_PATH` is needed.** Elmer is the packaged `elmerfem-csc`
  build and finds its own solver modules under `/usr/share/elmersolver/lib`,
  including from a subprocess with a scrubbed environment. Older notes told you
  to export `/usr/local/lib/elmersolver`; that path belonged to a source build
  that is no longer how this is installed, and setting it does nothing.
* **`Max Output Level` below 5 suppresses the result line.** The solve still
  succeeds. `ElectroMagnetic Field Energy:` is how inductance is read out, and
  below level 5 it is simply not printed.
* **`Desired Coil Current` is NOT multiplied by `Number of Turns`.** It is
  total ampere-turns and the arithmetic is yours. Getting it wrong is a factor
  of N² on the energy — 81× for a 9-turn coil.
* **A homogenised winding is turns in parallel, not in series.** Model a
  multi-turn coil as one solid annulus and the CoilSolver finds the current
  distribution a *conductor* would take: it crowds onto the short inner path,
  where it links less flux, and the inductance comes out ~33 % low with the
  mesh and the air box both fully converged. **Mesh the turns as separate
  bodies**, one Component each, all at the same current. That brought a
  worked case to within 4 % of FastHenry.
* **A coil body present but not energised must not sit in the CoilSolver's
  equation.** `CoilSolver body 11 active in Equation but not in Component!`
  So the equation assignment depends on which solve you are doing, and the
  three solves of a mutual-inductance measurement each need their own `.sif`.
* **`Coil Normal(3)`** must be given for any winding that is not a simple
  disc. The solver's guess is wrong for a racetrack and the current then
  circulates in the wrong plane.
* The air box boundary `AV {e} = 0` is a perfect flux return — a
  superconducting enclosure. Stand it well off the coil and **converge the box
  size**, or it acts as a shorted turn.

**Inductance from energy**, which needs one scalar per solve rather than a
parsed field:

```
tx alone        W1  = ½ L₁ I²
rx alone        W2  = ½ L₂ I²
both, in phase  W12 = ½ L₁ I² + ½ L₂ I² + M I²    ->  M = W12 − W1 − W2
```

W1 and W2 must agree for a symmetric stack. That they do is the check that
both coils are wired the same way round.

**Report ferrite results as ratios** against the air-core solve on the same
mesh, and apply them to a FastHenry absolute. Homogenisation and truncation
bias is common to both and divides out of a ratio; it does not divide out of
an absolute.

## Gmsh

* Write `-format msh2` (`Mesh.MshFileVersion = 2.2`), then
  `ElmerGrid 14 2 mesh.msh -autoclean -out <dir>`. Check `<dir>/mesh.names`
  rather than assuming the mapping, and use `Use Mesh Names = True` in the
  `.sif` so bodies are matched by name.
* **`occ.fragment` renumbers every volume.** The tags returned by
  `addBox`/`fuse` are stale the instant it runs. Record each solid's centre of
  mass *before* the boolean and match parts to it afterwards; assert that
  nothing is left unclaimed.
* Build the model **in metres**. Elmer has no units, and millimetre geometry
  with SI material data is how an inductance comes out by 10³.

## Capacity

Measured on a 4-vCPU cloud session: a 200k-element Elmer magnetostatic solve
runs in ~20 s; 340k complex DOF is about the ceiling. A PCB coil with its
copper traces resolved in 3-D is ~250k tetrahedra **per coil** — over budget
and the wrong approach anyway. Homogenise the winding, or use FastHenry.

FastHenry is not the constraint: a 9-turn coil pair at 6600 filaments solves
in about 5 seconds.

## Evidence

A field result becomes evidence the same way a SPICE result does: it names the
tool and version, the geometry it came from, the convergence settings it was
taken at, and the cross-check that agreed with it. A solver number with none
of those is a guess with more decimal places.

## Sweeping is a loop, so record it

A parameter sweep looking for a target inductance or an acceptable loss is
a closed loop. Run it under `hw-optimize`: `hw-iterate record` each solve
with the `.sif` or the FastHenry deck as its `--evidence`, and chart the
trajectory for the review. It is also the only thing that stops the next
session re-meshing geometry this one already ruled out.

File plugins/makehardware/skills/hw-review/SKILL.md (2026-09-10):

---
name: hw-review
description: Get a human to actually look at and agree to the work, at every milestone - produce an artefact they can open on github.com, ask them directly with a link, and record the sign-off in the repo so a stage cannot be called done without it. Use before declaring the vision, the plan, the requirements, the architecture or any design stage complete, whenever an agreed artefact has changed since it was signed off, and any time you are about to build on something nobody has confirmed.
---

# Human review

Two rules, and the second is enforced as hard as the first.

**An artefact the human has not seen is not a deliverable.**

**A review is a decision, not a report.** Lead with the interactive figure;
keep the words to what the figure cannot say. `review-gate` will refuse a
review that is more prose than it is evidence:

| | Budget | Why |
|---|---|---|
| `--summary` | **60 words** | It orients the reviewer. It does not brief them — the page does that. |
| each `--question` | **25 words** | A question someone has to re-read gets answered vaguely. |
| prose per viewable artefact | **80 words** | Text has to earn its place against a picture carrying the same number. |

The worked example's five reviews run 24-46 words of summary and 5-14 a
question, and none of them are thin. If a request will not fit, the problem is
almost never that the design is complicated — it is that the summary is doing a
figure's job. Every figure this toolbox needs has a generator: `hw-chart`,
`sch-lint --svg`, `pcb-lint --svg`, `cad-export`, `req-trace --map`,
`plan-render`, `block-diagram`, `hw-iterate chart`. `--long` overrides the
budget, and every use of it is a review somebody skimmed.

The same restraint applies to what you say in the session. The link and one
line beat a summary of the page you are linking to.

This exists because the workflow used to state an exit condition for every
stage — "the human points at one concept", "the human has looked at the image
and agreed to it" — and had nothing that caused it to happen. So it did not:
concepts were rendered and never shown, the requirements export was generated
on every run and never mentioned, and the plan, the requirements and the
architecture were all built on top of an agreement that had never been made.
The cost was not the wasted renders. It was that four stages were reported
complete.

## Where the human actually is

You are almost certainly running in a **cloud VM**. The human is not at this
terminal, does not have KiCad, draw.io, build123d or your filesystem, and will
not run a command to see your work. What they have is **the repository on
github.com, in a browser**.

That constraint decides everything about what a review artefact is:

| You made | They can review | So commit |
|---|---|---|
| a KiCad schematic | nothing | a **PDF** — `kicad-cli sch export pdf` — and the **`sch-lint --svg` overlay**, which is 340 elements against the plot's 60,000 and shows what is wrong |
| a KiCad board | nothing | **PDF** layer plots, a **PNG** 3D render top and bottom, and the **`pcb-lint --svg`** overlay with the decoupling loops on it |
| a build123d model | nothing | **`cad-export`**: renders, section, exploded view, an **`.stl`** GitHub shows in its own 3D viewer, and a **`.glb`** the review page orbits |
| a `.drawio` diagram | nothing | the **SVG** rendered from the same spec |
| a StrictDoc tree | nothing | the **SVG** requirements map — `req-trace --map` |
| a SPICE run | nothing | **`hw-chart corners`** or **`hw-chart bode`**, with the numbers on the chart |
| a `plan.yaml` | badly | `docs/plan.md` and `docs/plan.svg` — `plan-render` |
| a budget, a BOM, a coverage report | badly | **`hw-chart`** — `budget`, `waterfall`, `coverage` |

Commit the source too, so anyone who wants to open it in the real application
can. But the review is over the thing that renders in a browser. **If nothing
in a review renders in a browser, it is a download, not a review**, and
`review-gate` will tell you so.

GitHub renders `.md`, `.png`, `.jpg`, `.svg` and `.pdf` inline. It does not
render `.drawio`, `.kicad_*`, `.step` or `.html`.

## The four milestones, at a minimum

Never skip these. Each one is an agreement everything after it rests on.

| id | Stage | The artefact that renders | Ask them |
|---|---|---|---|
| `vision` | 1 | `docs/design/vision.md` + the renders under `docs/design/vision/` | which concept, and why |
| `plan` | 2 | `docs/plan.md` (scope and task descriptions) + `docs/plan.svg` (the dependency Gantt) | is this all the work, is the order right |
| `requirements` | 3 | `docs/design/requirements-map.svg` + the StrictDoc HTML export | are the numbers right, is anything missing |
| `architecture` | 4 | `docs/design/block-diagram.svg` + the power budget | is a rail missing, is a bus on the wrong controller |

Then **one per large design stage** — schematic capture, PCB layout, the
enclosure, each simulation campaign — using the same mechanism with an id of
your choosing (`schematic`, `layout`, `enclosure`, `thermal`).

## The loop

### 1. Produce the artefact and commit it

Generate it, look at it yourself first, then `git add` and **push**. A link to
an uncommitted file is a 404, and that is the fastest way to waste the
human's time. `review-gate open` checks this and names anything not yet
committed.

### 2. Open the review

```bash
review-gate open vision \
    --title "Vision and concept selection" \
    --summary "Two concepts: A is one-handed with the probe on a lead, B is
               bench-shaped with a bigger display. Numbers under each." \
    --artifact docs/design/vision.md \
    --artifact docs/design/vision/ \
    --reference concepts/ \
    --question "Which concept, and what made you pick it?" \
    --question "Is 164 mm too long for a coat pocket?"
```

That writes `docs/review/vision.md` — a page with the images inline, the
questions, and links to everything — records the digest of each artefact in
`docs/review/reviews.yaml`, and prints the github.com URLs.

**`--artifact` is the agreement; `--reference` is a link.** A tracked artefact
that changes after sign-off makes the review stale. Use `--reference` for
sources that legitimately churn — `plan.yaml`, a live `.kicad_sch`, the
`concepts/` modules — so the review does not go stale on every ordinary edit.
Choose the tracked artefact so that *what the human agreed to* is what makes
it stale: `docs/plan.md` carries no statuses precisely so the plan review
survives a week of progress and breaks when the scope changes.

Commit the packet and the ledger.

### 2b. Check the page before you send it

```bash
review-artifact --check     # exits 1, and names anything it cannot show
```

An export that failed leaves no file, and a render that is too big cannot be
embedded. Both are reported on the page rather than silently dropped — but a
page with "not shown here" boxes on it is not a review, and the human is the
most expensive place to discover that. Fix the export, then publish.

### 2c. Publish the page, and lead the request with it

```bash
review-artifact                      # writes docs/review/artifact.html
review-artifact --check              # and names anything it could not show
# publish it with the Artifact tool, then:
review-artifact --url <the artifact URL>
```

**The published page is the review; the repository is the archive.** They are
not the same surface and neither replaces the other:

* On the **page**, a schematic sheet zooms, a 3D assembly orbits, a BOM sorts
  by price and every value is one hover from its exact number. That is the
  difference between a picture of a schematic and a schematic.
* In the **repository** are the committed SVGs, PNGs, PDFs and `.stl` that
  render on github.com — what the human still has tomorrow, and what a
  reviewer with no session open can read.

So: commit everything, publish the page, and put the **page** URL in the
question with the repository link beneath it. Recording the URL matters — the
next session updates the same page instead of leaving a trail of orphans.

### 3. Ask them, with the link, and block

Use whatever tool this session has for putting a direct question to the human
— in Claude Code that is **`AskUserQuestion`**. Not a paragraph at the end of
a message they may not read: a question that stops and waits.

The question must carry:

* **the github.com URL of the review packet**, so one click gets them there;
* what you are asking, in one line;
* options that are real decisions, not "yes / no".

```
Vision is ready for review — two concepts, numbers under each.
https://claude.ai/.../artifact/...        <- the page: zoom, orbit, sort
https://github.com/<owner>/<repo>/blob/<branch>/docs/review/vision.md

  [ Concept A — the wand ]  [ Concept B — the instrument ]
  [ Neither, here's why  ]
```

`review-gate urls vision` prints the links; `review-gate open` prints the
whole request ready to use.

Then **stop**. Do not start the next stage. If there is genuinely independent
work that does not depend on the answer, do that and come back — but do not
build anything on an unanswered question, and do not answer it yourself.

### 4. Record what they said

```bash
review-gate sign vision --approve --by harrison \
    --note "Concept B. The instrument look reads as trustworthy in a
            commercial kitchen, which is where these get bought."

review-gate sign vision --changes "Too tall. Wants it under 140 mm and the
                                   display readable with gloves on."
```

Record it **in their words**. The reason they gave is worth more than the
choice, and it is what a later session re-reads when a number has to move.
Then commit — the ledger is the record, and a decision that lives only in a
chat transcript is a decision you will have to ask for again.

On `--changes`: fix it, re-run `review-gate open`, and ask again. A review is
a loop, not a form.

### 5. Only now is the stage done

```bash
review-gate check --gate     # exit 1 while any milestone is open or stale
plan-render --check          # a done chunk with an unsigned review fails here
```

Declare a chunk `done` in `plan.yaml` with a `review:` field naming its
review, and `plan-render --check` will refuse the claim until the sign-off
exists. That is the `req-trace --gate` discipline — evidence before a claim —
applied to agreement.

## Staleness is not bureaucracy

`review-gate` re-hashes every tracked artefact. If one changed after sign-off,
the review reads **stale** and the gate fails.

This is the case the whole mechanism exists for: the human agreed to a block
diagram, you changed a rail two sessions later, and everything downstream is
now resting on an agreement about a different diagram. Re-open it, say what
changed and why, and ask again. It is a short conversation and it costs
nothing compared to the alternative.

## Reviewing continuously, not only at milestones

Milestones are the floor, not the ceiling. Also go back to the human when:

* **you had to guess.** A guess you did not surface is a defect with a delay
  on it. Ask, and if you must proceed, say plainly what you assumed.
* **you are about to do something expensive** — order parts, generate fab
  output, commit to a package or a process.
* **a number moved after it was agreed.** Requirements that change silently
  are how a project ends up building something nobody asked for.
* **two readings of the brief lead to different hardware.** That is not a
  detail to resolve with a default.
* **the work turned out much bigger or smaller than the plan said.** The plan
  is an agreement too.

Between milestones, keep the generated artefacts current and committed —
`plan-render`, `block-diagram`, `req-trace --map` all re-render from their
specs in one command. A repository whose pictures are current is one the human
can review whenever they feel like it, which is worth more than any scheduled
checkpoint.

## What a good review request looks like

Short, specific, and answerable without opening a terminal:

* **Lead with the decision you need**, not with what you did.
* **Say what changed since last time**, if there was a last time.
* **Name the thing you are least sure about.** Reviewers find what you point
  at; a request that projects total confidence gets a rubber stamp, and a
  rubber stamp is not an agreement.
* **Offer real alternatives with their consequences.** "A is 12 g lighter, B
  is £4 cheaper at 1k" is a decision. "Does this look OK?" is not.
* **Never ask them to review something you have not looked at yourself.**
  Open the PDF. Look at the render. Open the page and use it — zoom a sheet,
  orbit the model, sort the table. Half of what a review would catch, you will
  catch first, and a control that does not work is worse than one that is not
  there.
* **Show, do not describe.** If a number can be plotted, plot it. `hw-chart`
  covers the standard ones. A paragraph explaining which rail is tight is a
  paragraph that a bar chart would have made unnecessary — and the bar chart is
  the one that gets looked at.
* **If you iterated, show the iteration.** A loop that reports only its final
  number is asking to be trusted; the same loop with `hw-iterate chart` on the
  page is asking to be checked. See `hw-optimize`.

## What this is not

It is not a status update, and it is not a request for approval of your
process. It is a specific question about a specific artefact, and the answer
changes what you do next. If the answer would not change anything, do not ask
it — say what you did and carry on.

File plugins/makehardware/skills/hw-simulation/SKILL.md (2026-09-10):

---
name: hw-simulation
description: Run and interpret circuit simulation with ngspice or LTspice through the spice MCP server. Use when a circuit needs its bias point, frequency response, transient behaviour, stability margin or noise checked, and when a simulation result needs turning into evidence against a requirement.
---

# Circuit simulation

The `spice` MCP server (ltspice-mcp) drives both simulators and parses the
binary `.raw` output, so measurements come back as numbers rather than as
something you have to read off a plot.

**ngspice is the default here.** It is headless, needs no Wine, and is a
first-class backend in this server. LTspice is only installed when
`MH_ENABLE_LTSPICE=1` — reach for it when you need vendor-encrypted ADI models
or `.asc` schematic editing, and say which simulator produced a number when it
matters.

## Dialect traps that will cost you a run

ngspice is not LTspice, and the differences bite in `.meas` first.

* `.meas` at the top level of a deck does not accept LTspice's `vdb()`; you
  get `Warning: can't parse 'vd': ignored` followed by
  `Error: no data saved`, which looks like the analysis failed rather than the
  measurement. Put the analysis and the measurement in a `.control` block
  instead, where `vdb()` works:

  ```
  .control
  ac dec 100 10 1meg
  meas ac fc when vdb(out)=-3
  .endc
  ```

* `ngbehavior = "hsa"` is set in `/etc/ltspice-mcp.toml`. That is what makes
  ngspice select the right section out of a sectioned `.lib`, which is how
  most vendor corner models ship. Without it you silently get the wrong corner.

* Per-device small-signal parameters are addressed differently:
  `.save @m1[gm]` on ngspice, `.options logopinfo` on LTspice. The server
  normalises the read-back to `m1.gm`.

## Trust the warnings, not the numbers

ngspice will print `singular matrix` once, deep in a log nobody opens, then
finish the run and write perfectly plausible numbers. The server attaches such
warnings to the value they affect in an `observations` field. **Read it.** A
result with observations attached is not evidence until you have explained
them.

The server reports facts, not verdicts. Deciding whether a number is good is
your job and the requirement's, not the simulator's.

## Sanity-check before you believe

Every simulation gets a closed-form cross-check where one exists. An RC corner
at `1/(2*pi*R*C)`, a divider ratio, a current limit. If the simulator and the
arithmetic disagree, the deck is wrong — find out which before moving on.

Sweep corners before calling anything done: component tolerance, temperature,
and supply extremes. A design that only works at nominal is not a design.

## Before concluding that an approach cannot work, list the levers you did not vary

A negative result from one configuration is a result **about that
configuration**. Corner sweeping covers tolerance, temperature and supply; it
does not cover the geometry and topology choices, which are usually the real
levers and are usually the ones held fixed without anyone noticing.

A coil analysis tested a single-layer etched spiral, found it 70 W short, and
wrote up *"PCB coils cannot reach the efficiency the thermal path requires"*.
Parallel layers — the obvious lever — were never modelled. Six layers turn a
190 W failure into a 73 W pass. The headline finding of the project was wrong
for two days.

So whenever a simulation says an approach fails, write the sentence out
before you write the conclusion:

> Held fixed: single layer, 35 µm copper, 2 mm trace pitch, 120 kHz.
> Not varied: layer count, copper weight, pitch, frequency, core material.

Then either vary the one most likely to move the number, or state the
conclusion at the scope you actually tested — "a single-layer 35 µm spiral
falls 70 W short", not "PCB coils cannot do this". The two sentences send a
project in completely different directions.

This is also why requirements are written against physics rather than against
a named conductor. A requirement phrased in terms of k·Q and dissipation
survives this correction; one that names "PCB coil" has to be rewritten, and
everything below it with it.

## Turning a run into evidence

A simulation closes a requirement only when it is reproducible, **and it is
evidence only once a human can read it**. Numbers go into a markdown table in
`docs/design/`, committed, with the failing corner first — a `.raw` file is
not a result and a plot with no number beside it is decoration. See
`hw-review` for the shape of a simulation review.

Commit the deck, record the result, and link them:

* commit the `.cir` / `.asc` under `sim/`
* put the number and the run into the requirement's `EVIDENCE` field
* add a `File` relation from the requirement to the deck
* move `STATUS` to `Verified`

Then `scripts/req_trace.py` will stop counting it as a gap. If it still does,
believe the tool.

## Turning a run into something a human will look at

The numbers go in a markdown table in `docs/design/`, committed. The *shape*
goes in a chart beside them, generated from the same rows:

```bash
hw-chart corners docs/design/standby-corners.csv \
    --out docs/design/standby-corners.svg --title "Standby current"
hw-chart bode docs/design/loop.csv --out docs/design/loop-gain.svg
hw-chart trace docs/design/startup.csv --out docs/design/startup.svg \
    --mark "x=1.2e-3,label=regulator enable"
```

`corners` is small multiples on one shared scale with the spec line drawn and
the failing corner marked — which is what makes corner evidence readable at a
glance, and what makes nominal-only evidence look as thin as it is. `bode`
computes the crossover and both margins from the data rather than taking them
from a caption. See `hw-visuals`.

Lead the summary with the corner that fails, never with the average.

## When the first run misses the target

A simulation that does not meet its number is the start of a loop, not a
result. Open one with `hw-optimize` — `hw-iterate` records each pass and
`hw-iterate chart` puts the trajectory in the review, which is what lets a
reviewer tell a converged design from one that ran out of time.

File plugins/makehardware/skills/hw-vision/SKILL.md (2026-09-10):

---
name: hw-vision
description: Run the vision stage of a hardware project - interview the human about what they actually want, then turn it into vision-board renders they can judge by eye. Use at the start of a new product, when the brief is still a sentence or a paragraph, or when someone says "I want to build X" without dimensions, budgets or constraints.
---

# Vision stage

The goal is a shared, concrete picture of the thing — not a requirements
document. Requirements come next, and they come out much better if this stage
did its job.

## Interview first, and go for the load-bearing questions

Start high level, but spend your questions where the answer changes the most
downstream. A question is high-leverage when different answers lead to
different architectures. Ask about those; assume sensible defaults for the rest
and say what you assumed.

The usual load-bearing set, roughly in order of leverage:

1. **Who holds it, and where.** Pocket, bench, rack, outdoors, inside another
   machine. This sets size, ingress protection, thermal path and connectors
   all at once.
2. **Power source.** Mains, battery, harvested, PoE. Battery immediately
   forces a capacity/runtime/size triangle you can put numbers on.
3. **The one number that must be true.** Runtime, accuracy, latency, weight,
   price. There is almost always exactly one the human really cares about.
4. **Volume and cost.** Ten units or ten thousand. This decides PCB layer
   count, connector choice, whether you can mould a housing at all.
5. **What it must not be.** The anti-goals are usually sharper than the goals
   and people give them up readily.
6. **Regulatory and environment.** Radio, mains isolation, medical, automotive,
   temperature range. Cheap to ask, ruinous to discover late.

Ask a few at a time and reflect back what you heard. Do not send a
questionnaire.

## Then show, do not tell

People judge a picture in a second and a paragraph in a minute, less
reliably. As soon as you can put numbers on an envelope, build the massing
model and render it.

A concept is one shape in one material, and `vision-board` is the right tool
for it — do not model an assembly at the vision stage. The moment the concept
is chosen and the envelope agreed, the model moves to `cad/` and becomes a
real assembly with labels, colours and joints: see `hw-cad`.

Write each concept as a plain build123d module under `concepts/`, defining
`PART`, plus optional `TITLE`, `NOTES`, `MATERIAL`, `RATIONALE`:

```bash
vision-board concepts/concept_a.py concepts/concept_b.py \
    --project "Thermal Probe" \
    --description "<the vision in the human's own words>"
```

That writes shaded three-quarter, front and top views, an isometric line
drawing with hidden edges, and a `manifest.json` carrying the bounding box,
volume and approximate mass for each concept — **into `docs/design/vision/`,
not `build/`** — plus `docs/design/vision.md`, the vision document.

The document is the point. It renders inline on github.com with every concept,
its numbers side by side, the styling proposals labelled as such and the open
questions at the end. You are almost certainly running in a cloud VM; the
human is looking at the repository in a browser, so a render under `build/` is
a render nobody sees. **Commit and push it before you ask anyone to look.**

## Build the thing they asked for, at the scope they asked for it

Two bare coil pads is not a product. If the human described something they
would hold, sell or install, the concept has to be recognisable as that thing
— an envelope, the interface they touch, the ports, roughly where the mass
is. A concept scoped to the sub-assembly you find most interesting invites a
polite yes to a question nobody asked, and there is nobody in a position to
catch it until much later.

When you genuinely cannot model the whole product yet, say what the model
covers and what it leaves out, in the document, above the picture.

**Always offer at least two concepts that differ in a way the human can name**
("softer vs. more instrument-like", "one-handed vs. two-handed"). A single
concept invites polite agreement; a pair forces a real preference, and the
reason they give you is worth more than the choice.

Then commit the document and the renders, and put it in front of the human —
see **`hw-review`** for the mechanism. Iterate on the parameters in the
concept modules, not on prose.

These renders come from real geometry, so they cannot show something
unbuildable, and every picture is tied to a bounding box and a volume. Say so:
the human should know they are judging a real envelope.

## Then style it, without losing the proportions

Geometry renders answer "is it the right size and shape". They do not answer
"does it look like something I want", which is about material, finish and
context.

Do them in this order so styling never quietly invents a different product:

1. **Render the geometry first.** That fixes the proportions and the numbers.
2. **Generate styling imagery from it** — see the **`hw-imagegen`** skill,
   which covers finding a backend in this environment and how to prompt for
   hardware. Prefer an image-*editing* model seeded with the geometry render,
   so the proportions survive.
3. **Label every generated image** *generated — styling only*, and keep the
   dimensioned line drawing beside it. Never let a generated image carry a
   number.

If no image backend is available, say so, ship the geometry renders, and tell
the human what enabling one would take. A board of dimensioned concepts is
still a good board.

## Leaving the stage

The vision stage is done when **a human has looked at the document and said
which concept, and that is recorded in the repository.** Not when the renders
exist. This stage has been reported complete on renders nobody saw, and the
plan, the requirements and the architecture were then all built on an
agreement that had never been made.

```bash
git add docs/design/vision.md docs/design/vision/ concepts/ && git commit && git push

review-gate open vision \
    --title "Vision and concept selection" \
    --summary "<what the two concepts are and how they differ>" \
    --artifact docs/design/vision.md --artifact docs/design/vision/ \
    --reference concepts/ \
    --question "Which concept, and what made you pick it?"
```

Then ask them directly — `AskUserQuestion`, with the github.com URL that
`review-gate` printed — and **block on the answer**. When they answer:

```bash
review-gate sign vision --approve --by <name> --note "<what they said>"
```

Record the *reason* they gave, not just the choice; it is worth more, and it
is what a later session re-reads when a number has to move. Write what they
agreed into `requirements/00-vision.sdoc` as `VIS-*` entries in their words,
commit the ledger, and move to `hw-planning`.

If they ask for changes, change the parameters, re-render, re-open the review
and ask again. That loop is the stage working.

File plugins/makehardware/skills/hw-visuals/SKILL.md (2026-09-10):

---
name: hw-visuals
description: Make the deliverable a picture rather than a wall of text - which chart answers which review question, how to draw one that survives Tufte's rules, and hw-chart, which generates them from the file that owns the numbers. Use whenever a result, a budget, a sweep, a coverage report or a comparison is about to be written as a paragraph or a table, when building anything for a review page, and when asked for a plot, a chart, a summary or a presentation.
---

# The picture is the deliverable

A hardware review is a set of numbers with a decision attached. Handed forty of
them as a table, a reviewer skims. The same forty in the right picture answer
the question in one second — *which rail is closest to its limit*, *which corner
fails*, *how much phase margin is left* — and that is the entire job of the
document.

So the default is inverted from how it usually goes:

> **If a number can be plotted, plot it. If a comparison can be drawn, draw it.
> Prose is for the thing the picture cannot say — why it matters and what you
> want the human to decide.**

Three or four sentences of text around a chart is a review. Fifteen paragraphs
with a render at the top is a document nobody finishes.

```bash
hw-chart budget    rails.csv     --out docs/design/power-budget.svg
hw-chart corners   corners.csv   --out docs/design/standby-corners.svg
hw-chart bode      ac.csv        --out docs/design/loop-gain.svg
hw-chart trace     tran.csv      --out docs/design/startup.svg
hw-chart coverage  coverage.csv  --out docs/design/coverage.svg
hw-chart waterfall bom.csv       --out docs/design/cost.svg
hw-chart stackup   stackup.csv   --out docs/design/stackup.svg

hw-chart <kind> --schema        # exactly what columns it wants
```

Every one is a themed SVG of two to seven kilobytes and under a hundred
elements, so it inlines on the review page, renders on github.com, stays crisp
at any zoom, follows the reader's light or dark theme, and puts the exact value
one hover away in a `<title>`.

## Which chart answers which question

| The question a reviewer is actually asking | Chart |
|---|---|
| *Is any rail close to its limit?* | `budget` — bars inside their budget outline, worst annotated |
| *Does it still meet spec at the corners?* | `corners` — small multiples on one scale, spec line drawn, failure marked |
| *Is the loop stable, and by how much?* | `bode` — margins computed from the data and annotated |
| *What does it do over time?* | `trace` — series direct-labelled, events marked |
| *What is left to verify?* | `coverage` — gaps first, then partial, then verified |
| *Where did the cost / the power / the mass go?* | `waterfall` — biggest first, running total |
| *Does every signal layer have a return path?* | `stackup` — the cross-section, unreferenced layers flagged |
| *What is the architecture?* | `block-diagram` (its own tool) |
| *What is the plan and what is next?* | `plan-render` (its own tool) |
| *Where are the requirements and how do they connect?* | `req-trace --map` |
| *What does the board or the schematic look like, and what is wrong with it?* | `sch-lint --svg`, `pcb-lint --svg` |
| *What does the part look like, and does it fit?* | `cad-export` renders, section and exploded view |

If none of those fits, read `references/engineering-plots.md` before inventing
one, and `references/tufte.md` before drawing it.

## The rules every chart here follows

1. **Direct labelling, never a legend.** A legend makes the reader hold a
   colour in their head and walk back and forth between key and data. Put the
   name at the end of the line.
2. **Show the limit, and the distance to it.** A bar chart of current draw says
   nothing. The same bars inside their budget say everything, and the reviewer
   never has to do arithmetic.
3. **Annotate the anomaly.** The failing corner gets the callout. If nothing is
   annotated, the reader has to find the story themselves, and they will not.
4. **No chartjunk.** No 3D, no gradients, no drop shadows, no frame, no
   gridlines the eye trips over. Ink that is not data is ink working against
   data.
5. **Small multiples share one scale.** Six panels with six y-axes is six
   charts. Six panels on one scale is a comparison, which is what was wanted.
6. **State is never colour alone.** A failing bar is red *and* carries its
   number *and* a marker, so it survives a mono print and a colour-blind
   reader.
7. **Generated, not typed.** Every number comes from the file that owns it. A
   figure typed into markdown is already wrong; it just does not know yet.

`references/tufte.md` is where these come from and why they hold.

## Where the picture goes

Both surfaces, and they are not the same surface:

* **The repository** gets committed SVG and PNG, because that is what the human
  still has tomorrow and what renders on github.com. `.stl` too, for anything
  3D — it is the only 3D format GitHub shows in an interactive viewer.
* **The review page** (`review-artifact`) is where the interaction lives:
  pan-and-zoom on every diagram, an orbitable 3D model, hoverable values,
  sortable tables. That is the artefact to lead the review request with.

`hw-review/references/exports.md` has the byte budgets and the recipes. The one
to remember: **prefer SVG for anything that is line art** — a schematic, a plot,
a diagram, a drawing. It inlines, it themes, it has no meaningful size limit.
Reserve rasters for what is genuinely photographic.

## Writing around the picture

Three or four sentences, in this order:

1. What this is, and what changed since they last saw it.
2. **The number or the choice you want confirmed** — the one the chart is about.
3. What you are least sure about.
4. What happens next if they say yes.

Lead with the gap, not the percentage. "Firmware has eleven requirements with
no evidence" is a review; "62% coverage" is a number that ends the
conversation.

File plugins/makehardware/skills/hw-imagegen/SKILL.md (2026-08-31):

---
name: hw-imagegen
description: Generate or restyle product imagery for the vision stage, using whichever image backend this environment actually has - an already-connected MCP image server, a keyed API, or neither. Use when a vision board needs styling imagery, when a concept needs to be shown in a material or a context, or when asked to make a render look real.
---

# Image generation

Geometry renders answer *"is it the right size and shape"*. They do not answer
*"does it look like something I want"*, which is about material, finish, colour
and context — and that is what generated imagery is for.

**Never let a generated image carry a number.** It is a styling proposal. The
dimensioned line drawing stays beside it on the board, and every generated
image is labelled *generated — styling only*.

## Find the backend before you plan the work

Backends differ per environment and per account. Do not assume; look. Work down
this ladder and use the first rung that answers:

### Rung 1 — an MCP image server that is already connected

Cheapest and most likely. Check the tools available in this session for an
image-capable MCP server before anything else.

* **Hugging Face connector** — `dynamic_space` with `operation: "discover"`
  lists what it can do. No API key, no allowlist entry. The ones that matter:

  | Space | Use |
  |---|---|
  | `mcp-tools/FLUX.1-Kontext-Dev` | **Image editing.** Feed it a geometry render; proportions survive. Prefer this. |
  | `mcp-tools/FLUX.1-Krea-dev`, `mcp-tools/Qwen-Image` | Text-to-image for mood and context shots |
  | `mcp-tools/Qwen-Image-Fast` | Quick iterations while hunting a direction |

  Always `view_parameters` on a space before `invoke` — the schemas differ.

  If `invoke` returns *"disabled because gradio=none is set"*, Space invocation
  is switched off on the connector rather than unavailable. `discover` and
  `view_parameters` keep working, which makes it look like a transient failure;
  it is not, and no amount of retrying or picking a different Space changes it.
  Two things have to happen, in this order:

  1. **The connector has to stop sending `gradio=none`.** That parameter is on
     the Hugging Face MCP endpoint the connector was added with, and which
     Spaces are exposed is chosen at
     [huggingface.co/settings/mcp](https://huggingface.co/settings/mcp). Adding
     Spaces there does not by itself clear a `gradio=none` that is pinned on
     the connector's URL — check the URL in claude.ai → Settings → Connectors.
  2. **Start a new session.** A running session negotiated its tool list at
     startup, so reconnecting a connector mid-session changes nothing you can
     see: the tool list, and `gradio=none` with it, are fixed until the next
     session. If `discover` still lists exactly what it listed before the
     reconnect, that is the tell.

  Say both of these to the human rather than only the first, and do not try to
  route around it.

* **Any other MCP server** exposing image generation works the same way. This
  ladder is about capability, not about a particular vendor.

### Rung 2 — a keyed API through `imagegen`

**This is the rung to reach for when rung 1 is blocked**, and it usually is:
Space invocation is off by default on the connector, and a running session
cannot see a connector change anyway. Rung 2 needs no connector at all.

```bash
imagegen --list          # which providers have a key, and what each supports
```

Four providers, easiest key first:

| Provider | Key | Why |
|---|---|---|
| `hf` | `HF_TOKEN` or `HF_KEY` | **Start here.** A free read token from [huggingface.co/settings/tokens](https://huggingface.co/settings/tokens). No connector, no Space invocation, no billing. |
| `fal` | `FAL_KEY` | Paid, fast, and the best image-to-image of the four. |
| `bfl` | `BFL_API_KEY` | Paid. FLUX Kontext, for restyling a render while keeping its proportions. |
| `openai` | `OPENAI_API_KEY` | Paid, text-to-image only here. |

Put the key in `.env` at the project root (gitignored) or in the environment.
On a **Custom** network policy the host also has to be reachable — see
`env/allowed-domains.txt`; on **Full** there is nothing to do.

### Adding a key to a session that is already running

You cannot, and it is worth knowing why before you ask someone to try.

A cloud session's environment variables are read when its **container starts**.
Adding one in the environment's settings afterwards changes what the *next*
session gets, not this one — the same is true of connector settings, so
reconnecting a connector mid-session does not change the tool list either. So
the sequence is: add the key in the environment's **Environment variables**
field, then **start a new session**. Both `HF_KEY` and `FAL_KEY` can go in at
once; `imagegen` picks whichever is present and `--provider` chooses between
them.

**Never ask the human to paste a key into the chat.** The transcript is stored,
so a key that arrives that way has to be treated as disclosed and rotated, and
you will have cost them a credential to save one session's wait. If they offer
anyway, say that, write it to `.env` rather than anywhere tracked, and tell
them plainly to rotate it afterwards.

A cold Hugging Face model returns 503 on the first call while it loads. That is
normal; wait and retry rather than switching provider.

If one is configured:

```bash
imagegen --prompt "brushed aluminium body, soft studio key light, neutral grey seamless" \
         --init-image build/vision/concept_a/view-hero.png \
         --out build/vision/style-a.png
```

`--init-image` is the important flag: it restyles the geometry render instead
of inventing a new object, so the proportions you just agreed survive. `fal`
and `bfl` support it; `openai` is text-to-image only here.

Keys live in `.env` at the project root (gitignored) or in the environment.
`--dry-run` prints the exact request without sending it, which is how you debug
a provider without spending a call.

**These endpoints have not been exercised against live keys from this repo.**
Treat the first call with a new provider as a test, and read the error rather
than assuming the key is wrong.

### Rung 3 — nothing configured

Say so plainly, produce the geometry renders, and carry on. A vision board of
dimensioned concepts is still a good vision board. Tell the human what they
would need to do to get styling imagery — enable Space invocation on the HF
connector, or drop a key in `.env` — and let them decide whether it is worth
it. Do not silently skip the styling step and do not describe a geometry render
as if it were a product photo.

## Adding a provider

`scripts/imagegen.py` has a `PROVIDERS` table. A provider is four things: the
env var(s) holding its key, how to build the request, how to pull an image out
of the response, and whether it accepts an init image. Append an entry; nothing
else changes. `--dry-run` will exercise it without a key.

Prefer adding a rung-1 MCP server over a rung-2 provider when you have the
choice — no key to manage, and nothing to put in `.env`.

## Prompting for hardware

Generic prompts give generic gadgets. What actually helps:

* **State the real dimensions** in the prompt even when restyling. "66 x 118 x
  17 mm handheld instrument" anchors proportion.
* **Name the material and process**, not just a colour: "bead-blasted anodised
  aluminium", "matte glass-filled nylon", "polished ABS with a soft-touch
  overmould". These read very differently and they cost differently too.
* **Describe the lighting** — "soft key from upper left, neutral grey seamless"
  gives a product shot; "on a workbench under fluorescent light" gives context.
* **One change at a time** when iterating, or you will not know what moved.

Generate two or three material directions for the concept the human chose,
rather than one image per concept. At this point the shape is settled; you are
asking a different question.

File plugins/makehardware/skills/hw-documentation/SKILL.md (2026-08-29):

---
name: hw-documentation
description: Manage the three kinds of hardware documentation - external reference material (datasheets, app notes, standards), internal design documentation (how and why we built it), and user documentation (manuals, spec sheets). Use when fetching a datasheet, recording a design decision, writing an ADR, or producing a manual.
---

# Documentation

Three kinds, with different owners, lifetimes and failure modes. Keeping them
apart is most of the discipline.

```
docs/
├── reference/    external — what other people published    (fetched, never edited)
├── design/       internal — how and why WE built it        (written as we go)
├── review/       agreement — what the human signed off     (see hw-review)
└── user/         outbound — how to use the thing           (written near the end)
```

A fourth constraint runs across all of them: **the human is reading this in a
browser on github.com**, because the agent is working in a cloud VM. Markdown,
PNG, SVG and PDF render there; `.drawio`, `.kicad_*`, `.step` and `.html` do
not. Write to what renders, and keep the source beside it for anyone who wants
the real application.

## 1. Reference — external material

Datasheets, application notes, standards, errata, reference designs. **Never
edit these.** They are evidence, and an edited datasheet is worse than none.

Every file is recorded in `docs/reference/manifest.yaml`:

```yaml
- id: mcp1700-datasheet
  title: MCP1700 Low Quiescent Current LDO
  part: MCP1700T-3302E/TT
  publisher: Microchip
  revision: DS20001826D
  url: https://ww1.microchip.com/downloads/en/DeviceDoc/20001826D.pdf
  local: docs/reference/mcp1700-DS20001826D.pdf
  retrieved: 2026-08-28
  sha256: ...
  needed_by: [ELE-001]
```

Record `revision` and `retrieved`, always. A datasheet that silently revised
under you is a real failure mode, and the revision is how you notice.

**Fetch the PDF, then extract locally.** `WebFetch` cannot read most datasheets
— it returns text saying the specifications are "embedded within the compressed
PDF content stream". `curl` the file into `docs/reference/`, then pull the text
out with `pypdf` or `pdftotext -layout`, both installed. See `hw-sourcing` for
the recipe and for why datasheet research must not be fanned out across
parallel agents.

**When you cannot fetch it.** On an environment with Full network access most
vendor sites are reachable, so fetch first and cite the file. Some material is
still out of reach: behind a login, an NDA, a paywall (IEC and ISO standards),
or an allowlist if the environment uses one. Do not guess at a number from
memory and do not silently proceed. Add the entry with
`local: null` and `blocked: <reason>`, then **ask the human to fetch it**, with
the exact URL and what you need from it. A parameter taken from memory instead
of a datasheet is exactly the confident wrong answer that gets a board
fabricated wrong.

Cite what you use: when a number comes from a datasheet, put the reference `id`
and the page or table in the requirement's `RATIONALE` or the ADR.

## 2. Design — how and why we built it

The documentation that makes the design maintainable by someone who was not
there. Written **as the work happens**, not reconstructed at the end.

Decisions that constrain anything downstream get an ADR in
`docs/design/adr-NNNN-<slug>.md`:

```markdown
# ADR-0002: Linear regulator for the always-on rail

## Status
Accepted — 2026-08-28

## Context
ELE-001 caps standby draw at 40 uA. The always-on rail is 3.3 V at under 5 mA.

## Decision
MCP1700 LDO rather than a switcher.

## Consequences
- Quiescent current 1.6 uA typ, which fits the 40 uA budget with margin.
- Dropout sets the minimum usable cell voltage at 3.5 V, which feeds SYS-001.
- Efficiency is poor above 5 mA; if the active rail ever moves here, revisit.

## Alternatives considered
- TPS62740 buck: better efficiency, 360 nA Iq, but 4x the cost and needs an
  inductor the enclosure has no room for at the current envelope (MEC-001).
```

Write the **Consequences** honestly, including the bad ones. That section is
what a future session reads when the number has to move.

Also in `docs/design/`: the architecture overview, interface definitions
(board outline, connector pinouts, mounting), and the verification report.

## 3. User — how to use the thing

Manuals, quick-start guides, the spec sheet for *our* product, safety and
regulatory statements. Written late, but **stub it early**: a product whose
specification sheet cannot be filled in is usually a product with a
requirements gap.

Pull the numbers from the requirements tree, not from memory — the spec sheet
and `requirements/` must not disagree. If they do, one of them is wrong and it
is worth finding out which before it ships.

## The rule that matters

**A number in any document traces to a source.** A datasheet reference, a
requirement UID, or a simulation result. A number with no source is a guess
wearing a document's clothes, and it will be believed.

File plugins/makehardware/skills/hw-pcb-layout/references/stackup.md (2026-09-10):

# Stackup, planes and return paths

Decided before the first footprint is placed. Changing it later is a re-route.

## Choosing a layer count

| Layers | Use it when | Arrangement |
|---|---|---|
| 2 | Nothing faster than a few MHz, no switching converter, cost dominates | Signal / ground pour. Every signal on top, an uninterrupted pour below. |
| 4 | The default for anything with an MCU, a switcher or a bus | Signal / **GND** / power / signal. |
| 6 | Two or more high-speed interfaces, or a dense BGA | Signal / GND / signal / signal / GND / signal. |

**Four layers, arranged signal-ground-power-signal, is the answer for most
boards** and it is worth the extra few dollars long before it is worth the
argument. The second layer being a solid, unbroken ground plane is what makes
every other rule in this file work.

The seductive mistake is signal / power / ground / signal, which puts each
signal layer next to a plane that is chopped into rail-shaped islands, so half
the signals have no continuous return. Do not.

## Reference planes

Every signal layer must have a plane layer immediately adjacent to it. That
plane is the return path; without one, return current finds its own way and the
loop it makes is the antenna.

`pcb-lint`'s `PCB-REFPLANE` checks the declared layer types and the pours. It
is suppressed on two-layer boards unless `--strict`, because there a signal
layer with a pour opposite it is the correct arrangement.

## Rules that follow from having a plane

**Never route a fast signal across a split in its reference plane.** The return
current has to go around the split, and the loop is the length of the detour. If
a split is unavoidable, route the signal around it too, or bridge it with a
stitching capacitor right where the signal crosses.

**Every signal via needs a return via.** A signal changing layers changes its
reference plane; the return has to change with it. A ground stitching via within
a couple of millimetres of the signal via does that. Without it, the return goes
to the nearest connection between the two planes, which may be centimetres away.

**Do not fragment the ground plane with traces.** A ground plane with a track
routed through it is two ground planes. If a plane layer must carry a signal,
route it where nothing above or below needs the return.

**Stitch the planes at the board edge and around any high-current loop.** Vias
every few millimetres. It costs nothing and it is what stops the board edge
radiating.

## Impedance

Anything that is a transmission line — USB, Ethernet, a display's differential
pairs, anything above about 50 MHz — needs a controlled-impedance stackup, and
that means the fabricator's stackup, not a guess. Ask them for it, put the
dielectric thicknesses into the KiCad stackup, and set the trace widths from
their calculator, not from a rule of thumb.

Put the resulting stackup in the review as a table:

| Layer | Type | Copper | Dielectric to next | Reference |
|---|---|---|---|---|
| F.Cu | signal | 35 µm | 0.20 mm prepreg | In1.Cu |
| In1.Cu | **GND** | 35 µm | 1.10 mm core | — |
| In2.Cu | power | 35 µm | 0.20 mm prepreg | — |
| B.Cu | signal | 35 µm | — | In2.Cu |

A reviewer can find a missing reference plane in that table in five seconds and
cannot find it in a render at all.

## Copper thickness and current

1 oz (35 µm) is the default. A 0.25 mm track in 1 oz outer copper carries about
1 A at a 10 °C rise; a 1 mm track about 3 A. Inner layers are worse — roughly
half — because there is no air to convect into.

Two consequences worth holding:

* **A power net's final track width is a thermal number, and it is usually far
  wider than a router can enter a pad with.** Route at pad width, widen
  afterwards, and record the target width in the layout notes so the widening
  is not forgotten. `templates/kicad/house-defaults.json` has a
  `final_track_width_mm` field for exactly this.
* **Vias carry current too.** A 0.3 mm via is good for roughly 1 A. Parallel
  them on a power path; one via is a fuse.

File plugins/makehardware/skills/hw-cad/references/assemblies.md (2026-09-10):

# What each format actually carries

Measured on this toolchain — build123d 0.11.1 on OCCT 7.9 — by exporting an
assembly and re-importing it, not from documentation.

| | Tree | Names | Colours | Placement | Editable joints |
|---|---|---|---|---|---|
| **STEP AP242** | yes | yes | yes | yes | **no** |
| **glTF / GLB** | yes | yes | yes | yes | **no** |
| **3MF** | yes | yes | yes | yes | **no** |
| **STL** | no | no | no | baked in | **no** |
| **FreeCAD `.FCStd`** | yes | yes | yes | yes | **yes** |

## STEP

`cad-export` writes AP242, not the AP214 build123d produces by default.

That is worth knowing if you ever write the export yourself:
`build123d.export_step` calls `STEPCAFControl_Controller.Init_s()` partway
through its own body, which resets the `write.step.schema` static back to its
default **after** any caller has set it. Setting the parameter before calling
`export_step` therefore appears to succeed — `SetCVal_s` returns True — and has
no effect on the file. `cad-export` drives `STEPCAFControl_Writer` directly and
sets the schema between the controller init and the transfer.

Verified by re-import: the tree, every label and every colour come back.

**What it does not carry is mates.** AP242 edition 2 defines kinematics; OCCT
does not write them and FreeCAD does not read them. There is currently no
portable file format that moves an editable constraint between CAD tools.

### The mate-datum convention

Since STEP does carry named solids at known locations, `cad-export` writes one
per joint: a 2 mm cross at the joint's own origin and orientation, labelled
`MATE_<part>_<joint>` and coloured magenta so it is obvious and easy to hide.

A CAD user opening the STEP then has something to snap to. Selecting a datum's
axis and mating it to another datum's axis is three clicks; finding the right
face on a part somebody else modelled is not.

Hide the `MATE_*` bodies before rendering or measuring. They are annotation.

## glTF / GLB

The node tree, node names and per-part colours all survive. Colours are written
linearised, which is correct for glTF and is why the numbers in the file do not
match the `Color(...)` you wrote.

This is the format for the interactive viewer on the review page. GitHub does
**not** render it in the blob view.

## STL

Geometry only — one merged mesh, no names, no colours, no tree.

Worth exporting anyway for exactly one reason: **GitHub renders `.stl` in an
interactive 3D viewer in the blob view**, up to 10 MB, and it is the only 3D
format it does render. That makes it the one file a reviewer can rotate and
zoom with nothing installed. Keep it coarse — it is for looking at — and say in
the review request that it is a review mesh, not a manufacturing one.

## 3MF

Neither build123d nor OCCT has a 3MF exporter, so `cad-export` writes one: it
is a zip of two small XML files, and it is the only *mesh* format that carries
part names and colours. Use it when a print or mesh workflow would otherwise
lose the assembly.

## FreeCAD

The only path where a constraint arrives alive. `<name>-freecad.py` imports the
STEP and creates `Assembly::JointFixed`, `JointRevolute`, `JointSlider`,
`JointCylindrical` or `JointBall` objects from `<name>-joints.json`, including
angle and length limits where the build123d joint declared a range.

Needs **FreeCAD 1.0 or newer** — the Assembly workbench does not exist before
that, and the macro says so and still saves the geometry rather than failing.

## joints.json

```json
{
  "name": "rim",
  "part": "shell",
  "type": "RigidJoint",
  "freecad_type": "Fixed",
  "position_mm": [0.0, 0.0, 8.8],
  "rotation_deg": [0.0, 0.0, 0.0],
  "connected_to": {"part": "lid", "joint": "seam"}
}
```

Readable by a person and by the macro. A `RevoluteJoint` additionally carries
`axis_origin_mm`, `axis_direction` and `angle_limits_deg`; a `LinearJoint`
carries `linear_limits_mm`.

This is the file to hand somebody working in a CAD tool the macro does not
cover. It says, in numbers, where every mate goes.

## The gate

`cad-export --check` fails on:

* a module exposing `PART` instead of `ASSEMBLY` — a single solid;
* a part with no label, which arrives as `Solid` in the tree;
* a part with no colour, which makes every render one flat shape;
* **no joints at all**, or a part no joint reaches — positioned by hand, so it
  will not follow the next changed dimension;
* duplicate part labels, which the CAD tree cannot tell apart;
* parts sharing solid volume, which is a real interference and not a
  rendering artefact.

None of those are opinions about style. Each one is a way the file is worse for
the person who has to open it.

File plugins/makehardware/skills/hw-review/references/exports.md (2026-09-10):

# Making a design reviewable from a browser

Every recipe here turns something only an application can open into something
github.com renders. Run it, look at the result yourself, commit it, then open
the review.

Keep the exports under `docs/design/` (or `docs/review/`) rather than `build/`
— `build/` is gitignored, and an artefact that is not committed is an artefact
nobody sees.

## Export at review size, not at native size

Two different consumers, two different limits, and the second one bites:

* **GitHub** will render whatever you commit, at any size.
* **The review page** (`review-artifact`) has three budgets, and the whole
  page has to stay inside the 16 MB artifact cap:

  | | Limit | What blows it |
  |---|---|---|
  | raster, as a data URI | 220 kB | `pcb render --width 3000`, `dpi=300` |
  | one SVG | 1.5 MB / 30,000 elements | any dense plotted schematic |
  | one `.glb` model | 2.5 MB | exporting at manufacturing tolerance |
  | the page, in total | 9 MB inlined | a tab with six sheets on it |

  Anything over is reported on the page instead of shown, which is honest but
  is not a review.

**A plotted schematic is far bigger than you expect.** KiCad's SVG exporter
writes one `<path>` per *line segment*, including every stroke of every
character of text. Measured on KiCad's own `pic_programmer` demo:

```
root sheet   3.0 MB    61,681 elements     linked, not inlined
sub-sheet    1.0 MB    21,265 elements     inlines fine
```

So one ordinary A4 sheet can be a megabyte, and a four-sheet design will not
fit. Put the two or three sheets that carry the decision on the page, commit
the PDF for the whole set, and say in the request which sheets you chose.

So export twice when it matters: full size for the record, and a review-sized
copy for the page.

```bash
kicad-cli pcb render hw/probe.kicad_pcb --output docs/design/pcb-top.png \
    --side top --quality high --width 1400 --height 1000     # ~150-200 kB
```

For matplotlib, `savefig(..., dpi=110)` on a 7×5 in figure lands around 150 kB.

**A plotter's colours cannot be themed, and that is fine.** KiCad fills the
page with `#F5F4EF` and draws in black, written inline on every `<g>`, so no
stylesheet on the page can reach it. The review page detects a full-page light
fill and mats the sheet, the way it mats an opaque raster — a schematic then
reads as a sheet of paper on a dark page rather than a hole in it. Do not try
to recolour a plot for the page: it would misrepresent what you exported.

**Export rasters with a transparent background** where the tool allows it —
`savefig(..., transparent=True)`, which `vision-board` already does. A render
exported against white is a bright slab on a dark page; the review page mats
those deliberately so they read as a mounted photograph, but transparent is
better. And **never bake a title or a label into a raster**: a bitmap cannot
follow the reader's theme, so dark text in it stays dark on a dark page. Labels
belong in the caption or in an SVG overlay.

**Prefer SVG wherever the thing is line art** — a schematic, a plot, a diagram,
a dimensioned drawing. It inlines as markup, stays crisp at any zoom, themes
with the page, and has no byte budget at all. Reserve rasters for what is
genuinely photographic: a shaded 3D render, a photo of a board.

Run `review-artifact --check` before publishing. It exits 1 and names every
artefact that could not be embedded, which is much cheaper than finding out
from the human.

---

## The lint overlays — the cheapest useful picture there is

```bash
sch-lint hw/probe.kicad_sch --svg docs/design/lint
pcb-lint hw/probe.kicad_pcb --svg docs/design/lint/board.lint.svg
```

Each writes the artefact drawn at 1:1 with every finding circled, numbered and
listed underneath. About three hundred elements against the sixty thousand
KiCad's own plot of the same sheet costs, so they inline on the page *and*
render on github.com — which the real plot does not.

Put these on the review page next to the plot, not instead of it. The plot is
what the design is; the overlay is what is wrong with it.

## KiCad schematic

```bash
kicad-cli sch export pdf hw/probe.kicad_sch \
    --output docs/design/schematic.pdf

# One SVG per sheet, which renders inline in markdown rather than needing
# GitHub's PDF viewer. Worth it for a design with one or two sheets.
kicad-cli sch export svg hw/probe.kicad_sch \
    --output docs/design/schematic/

# The netlist and the ERC report belong with them: they are what makes the
# review a review rather than a look.
kicad-cli sch erc hw/probe.kicad_sch \
    --output docs/design/erc-report.rpt --severity-error --severity-warning
kicad-cli sch export bom hw/probe.kicad_sch --output docs/design/bom.csv
```

`--black-and-white` if the colour plot is hard to read. Put the ERC result in
the review summary as a number — "ERC: 0 errors, 3 warnings, all
unconnected-pin on the debug header" — not as an attachment nobody opens.

**Prefer the per-sheet SVGs over the PDF, for the two or three sheets that
carry the decision.** Pass them as `--artifact` and `review-gate` embeds each
inline in the review packet, so the human scrolls one page instead of opening
GitHub's PDF viewer — serviceable on a desktop, unpleasant on a phone. Commit
the PDF too, for printing and for the sheets that did not make the page.

`sch export` offers PDF, SVG, DXF and PS — there is no PNG, in KiCad 10 either
— so a sheet too dense for the page has no smaller raster to fall back on.
Choose fewer sheets rather than hoping.

## KiCad board

```bash
# The board in 3D, which GitHub renders interactively in the blob view.
kicad-cli pcb export step hw/probe.kicad_pcb --output docs/design/pcb.step
# (and an STL alongside it if you want the viewer: kicad-cli has no STL
#  exporter, so convert the STEP, or export from build123d.)

# Layer plots, one page each, in one PDF.
kicad-cli pcb export pdf hw/probe.kicad_pcb \
    --output docs/design/pcb-layers.pdf \
    --layers F.Cu,In1.Cu,In2.Cu,B.Cu,F.SilkS,B.SilkS,Edge.Cuts \
    --include-border-title

# What it will look like. Both sides — the opposite side of a board is where
# the surprises are.
kicad-cli pcb render hw/probe.kicad_pcb --output docs/design/pcb-top.png \
    --side top --quality high --width 1600 --height 1200
kicad-cli pcb render hw/probe.kicad_pcb --output docs/design/pcb-bottom.png \
    --side bottom --quality high --width 1600 --height 1200

kicad-cli pcb drc hw/probe.kicad_pcb --output docs/design/drc-report.rpt \
    --severity-error --severity-warning
```

A layout review needs the stackup, the board outline with its overall
dimensions, and the DRC count as a number. A render alone shows a human
nothing they can act on.

## Mechanical (build123d)

One command, and it produces everything a mechanical review needs:

```bash
cad-export cad/enclosure.py --out docs/design/cad --name enclosure
```

| File | Where it is reviewed |
|---|---|
| `enclosure-render.png`, `-exploded.png`, `-section.png` | Inline, on the page and on GitHub |
| `enclosure-iso.svg` | Inline, line art, themes with the page |
| `enclosure.glb` | **The review page's orbit viewer** — drag to turn it over |
| `enclosure.stl` | **GitHub's own 3D viewer**, the only 3D format it renders |
| `enclosure.step` | Anyone who wants it in CAD: tree, names, colours, MATE_* datums |
| `enclosure-joints.json`, `-freecad.py` | The constraints STEP cannot carry |

Put the `.glb` in the phase's `images:` and the page builds the viewer. Commit
the `.stl` too and keep it coarse — it is a review mesh, not a manufacturing
one, and say so in the request.

**A cross-section is still the most informative single image of an enclosure.**
It shows the wall thicknesses, the internal clearances and where the board
actually sits, and it is the one view an orbit viewer will not give you by
default. `cad-export` writes one every time.

For a vision-stage concept rather than a finished assembly, `vision-board` is
still the tool — it renders one shape in one material, which is what a concept
is.

## Requirements

```bash
req-trace --map                     # docs/design/requirements-map.{svg,drawio}
/opt/hw-py/bin/strictdoc export requirements \
    --output-dir docs/design/requirements-html --formats=html
```

The SVG map is the artefact — it renders inline and shows the shape of the
tree, which is what a human can actually judge. The HTML export is complete
but GitHub will not render it; link it as a `--reference` and say it needs
downloading. **Do not generate the HTML export on every validation run and
never mention it**, which is what used to happen.

## Architecture

```bash
block-diagram                       # writes the .drawio and the .svg
block-diagram --summary             # the power budget, as text
```

The SVG renders on GitHub; the `.drawio` is the editable one. **Always emit
both.** The review page finds the `.drawio` that goes with a rendered diagram —
including across directories, which this pair needs, since the `.drawio` lands
in `hw/` and the SVG in `docs/design/` — and puts *Open in draw.io* under the
picture. That link hands diagrams.net the raw URL, so the human is one click
from an editable diagram with nothing to install and nothing to download. It
fetches anonymously, so it works on a public repository; on a private one they
download the file from GitHub and drop it on the canvas instead, and the link
to the file is there for exactly that.

The rule generalises: **a diagram you generate should have a `.drawio` beside
it.** A picture someone cannot change is a picture they can only complain
about.

Put the power budget in the review as a **chart**, not as a sentence:

```bash
hw-chart budget hw/rails.csv --out docs/design/power-budget.svg
```

A rail at 95% of its limit is the single most useful thing in an architecture
review, it is invisible in the block diagram, and it is the first thing the eye
lands on in a bar inside its own budget outline.

## Simulation

```bash
hw-chart corners docs/design/corners.csv --out docs/design/standby-corners.svg
hw-chart bode    docs/design/ac.csv      --out docs/design/loop-gain.svg
```

`hw-chart corners` draws the corners as small multiples on one shared scale,
with the spec line and the failing corner marked. `hw-chart bode` computes the
crossover, phase margin and gain margin **from the data** and annotates them —
a margin typed into a caption is a margin that stopped being true at the next
simulation.

Keep the numbers in a markdown table beside the chart. A `.raw` file is not a
result and a plot without the number beside it is decoration.

```markdown
| Corner | Measured | Required | Margin |
|---|---|---|---|
| 25 °C, 3.3 V nom | 38.2 µA | ≤ 40 µA | +4.5% |
| 85 °C, 3.0 V min | 41.7 µA | ≤ 40 µA | **−4.3% FAIL** |
```

Lead with the corner that fails. Commit the deck beside it so the run is
reproducible, and state which simulator produced the number.

## Fabrication output

Ordering parts is expensive and irreversible, so this is exactly the point
where an extra question is cheap. But the review here is **not** a gallery: a
fabrication drawing shrunk to page width tells nobody anything they can act
on, and nobody reads an assembly traveller inside a review page.

What the human needs at this stage is a **checklist** — the set of documents a
run requires, which of them exist, and one click to each. Give the phase a
`links:` list in `docs/review/artifact.yaml`, grouped with `group:`, and the
page renders it with a present/missing tally at the top:

```yaml
  - id: mfg
    links_title: Release checklist
    links:
      - {group: Fabrication, path: docs/design/pcb-fab.zip,
         label: Gerbers and drill files,
         why: "RS-274X plus the drill schedule"}
      - {group: Assembly, path: docs/design/mfg/assembly-process.md,
         label: Assembly and test process,
         why: "The traveller — paste, placement, reflow, then the test sequence"}
```

**List the documents that do not exist yet too.** A row saying *Not produced*
is the entire value of a checklist; a list of only what you have is a list
that cannot tell anyone what is missing.

Cover, at least: gerbers and drill, the fabrication drawing, the stackup, the
written fab notes, the assembly drawing, the pick-and-place, the BOM, the
assembly and test process, the test fixture, the quotes with their dates, and
which supplier was chosen and why.

---

## Writing the summary that goes with it

The artefact is what they look at. The summary is what makes them look at the
right part of it. Three or four sentences:

1. What this is, and what changed since they last saw it.
2. The number or the choice you want confirmed.
3. What you are least sure about.
4. What happens next if they say yes.

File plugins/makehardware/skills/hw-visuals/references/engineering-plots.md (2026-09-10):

# Which plot, for which decision

A chart earns its place by changing what somebody does. Every entry below names
the decision first, because if there is no decision, the chart is decoration and
a sentence would be better.

---

## The budget bar — *is any rail close to its limit?*

`hw-chart budget rails.csv`

One row per rail or per consumer, drawn as a filled bar inside the outline of
its budget. The reviewer never does arithmetic: the fraction is the picture.

The single most useful thing in an architecture review is *a rail at 95% of its
limit*, and it is invisible in a block diagram. Put this beside the diagram and
the review has something to be about.

Amber past 85%, red past 100% with the overage named, and the worst row
annotated whether or not it fails — because that is the row the conversation is
going to be about.

## The corner small-multiple — *does it still meet spec at the corners?*

`hw-chart corners corners.csv`

One panel per measurement, one bar per corner, **one shared scale per panel**,
the spec drawn as a dashed line, failures in red with a marker and their value
in bold.

`hw-verification` is explicit that evidence at nominal is not evidence. This is
the shape that shows corner evidence honestly: a nominal-only result has one bar
and looks obviously thin, which is the point.

Lead the summary with the corner that fails. Never with the average.

## Bode with the margins marked — *is the loop stable, and by how much?*

`hw-chart bode ac.csv`

Gain and phase against log frequency, with the crossover, phase margin and gain
margin **computed from the data** and annotated on it. Nothing is typed in: a
margin typed into a caption is a margin that stopped being true at the next
simulation.

Under 45 degrees of phase margin the annotation turns red and says so. That is
usually the whole review.

## The annotated trace — *what does it actually do over time?*

`hw-chart trace tran.csv --mark "x=1.2e-3,label=regulator enable"`

Series direct-labelled at the end of the line, events marked where they happen.
Use it for startup, for a load step, for an inrush, for a shutdown.

A transient plot with no annotation is a picture of a squiggle. The annotation
is the content: *this is where the rail comes up*, *this is the overshoot*,
*this is where the brownout detector would trip*.

## The coverage bar — *what is left to verify?*

`hw-chart coverage coverage.csv`

Gaps drawn **first**, then partial, then verified. That ordering is deliberate
and it matches the house rule: lead with gaps, not percentages. "Firmware has
eleven requirements with no evidence" starts a conversation; "62% coverage" ends
one.

## The waterfall — *where did the cost, the power or the mass go?*

`hw-chart waterfall bom.csv`

Contributions biggest first, accumulating to a total. Almost always the top two
items are the entire story, and a waterfall is the shape that shows that in one
look. A pie chart is the shape that hides it.

Same tool for BOM cost, for a current budget by consumer, and for a mass budget.

## The stackup cross-section — *does every signal layer have a return path?*

`hw-chart stackup stackup.csv`

Layers top to bottom, compressed so 35 µm of copper is still visible next to
1.1 mm of core, with the real micrometre figure printed beside each. A signal
layer with no adjacent reference plane is called out in red.

`hw-review/references/exports.md` says a layout review needs the stackup as a
table. This is that table, in a form where a missing reference plane is visible
rather than deducible.

---

## The ones with their own tools

| Question | Tool |
|---|---|
| What is the architecture? | `block-diagram` — draw.io plus SVG, both generated |
| What is the plan, what is next, what is blocked? | `plan-render` — dependency Gantt |
| Where do the requirements come from and what realises them? | `req-trace --map` |
| What is wrong with this schematic sheet? | `sch-lint --svg` |
| What is wrong with this board? | `pcb-lint --svg` |
| What does the part look like, and does it fit? | `cad-export` — render, section, exploded |
| What will the board look like? | `kicad-cli pcb render`, both sides |

Use the tool rather than drawing the picture yourself. Each one reads from the
file that owns the data, so it is right on the next run.

---
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

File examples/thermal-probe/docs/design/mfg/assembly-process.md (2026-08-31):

# Assembly and test process

For a first article run of 25. Written so someone who has not seen the board
can run it, because at 25 pieces that is who will.

## Assembly

1. **Solder paste**, top side only, from the supplied stencil. 0.12 mm
   stainless, 1:1 apertures except `DS1`, which is reduced to 90% — the
   display frame bridged on the prototype at 1:1.
2. **Place** the ten top-side parts. Seven are polarised; the assembly drawing
   marks pin 1 with a red dot and the position file carries the rotations.
3. **Reflow** to the paste manufacturer's SAC305 profile. Peak 245 °C, time
   above liquidus 60–90 s.
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

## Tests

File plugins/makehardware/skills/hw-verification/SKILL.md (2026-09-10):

---
name: hw-verification
description: Close out hardware requirements against evidence and report honest coverage, and run the pre-route and pre-fabrication checks that catch a defect before it is expensive. Use at the end of a design sprint, before claiming a design is done, before placing or routing a PCB, before generating fabrication output, or whenever asked "does this meet the requirements" or "what is left".
---

# Verification

Verification is the step where claims become evidence. It is also the step
where it is easiest to be quietly dishonest, so the rules are narrow.

## The only way a requirement becomes Verified

All four, or it stays where it is:

1. `VERIFICATION` names how it was closed — Analysis, Simulation, Test or
   Inspection.
2. `EVIDENCE` points at something a person can go and look at: a committed
   simulation deck and its result, an ERC/DRC report, a measurement log, a
   calculation.
3. A `File` relation links the requirement to the design artefact that
   realises it.
4. The evidence actually shows the number in the `STATEMENT` being met, at the
   corners that matter — not just at nominal.

Never set `STATUS: Verified` to make the gate pass. If a requirement cannot be
met, say so and propose the change: relax the number with the human's
agreement, or `Waived` it with a rationale. An unmet requirement reported
plainly is a normal engineering outcome. An unmet requirement marked Verified
is a defect you have hidden.

## Run the gate and report what it says

```bash
/opt/hw-py/bin/python scripts/req_trace.py --gate
```

Report the number it prints, including the gaps. When coverage is 60%, say
60%. Do not describe a design as complete while the gate is failing; name what
is outstanding and what it would take to close it.

## What to check beyond the gate

The gate is structural. These are not, and they are where real problems hide:

* **Budget roll-ups reconcile.** Children's `BUDGET` values against the
  parent's. Do the arithmetic and show it.
* **Corners, not nominal.** Tolerance, temperature, supply. Evidence taken
  only at nominal does not close a requirement that has a range in it.
* **Electrical rule checks pass.** `kicad-cli sch erc` and `kicad-cli pcb drc`
  on the current files, not on a remembered earlier run.
* **The vision still holds.** Walk back up the tree to the `VIS-` entries and
  ask whether the thing you have designed is the thing the human described. A
  design can satisfy every requirement and still miss the point; that is worth
  saying out loud.

## Checks that must happen before the board is routed

These are verification too — they are the cheapest place to catch a defect,
and every one of them has been diagnosed as something else first, at a cost of
hours.

**Most of them now run as one command:**

```bash
sch-lint hw/probe.kicad_sch --gate --plan hw/block-diagram.yaml
pcb-lint hw/probe.kicad_pcb --gate
```

`pcb-lint` automates items 1, 2 and 4 below plus the keep-out check, ranks the
decoupling loops worst-first, and finds silkscreen on pads, unreadable
reference designators, overlapping courtyards and a signal layer with no
reference plane. `sch-lint` does the same for the drawing, and `--plan` binds
it to the architecture the human already agreed to. Both are read-only, both
run headless, and neither needs KiCad.

Run them, then item 3 — DRC on the placed, unrouted board — which nothing else
substitutes for. **`references/pcb-layout.md` next to this file has the full
workflow, the commands and the diagnosis stories.** The four that matter most:

1. **Net class widths against pad sizes.** A 1.20 mm track cannot enter a
   0.25 mm QFN pad and a router will not neck down. This presents as "180 of
   234 connections unroutable" with no stated reason, and gets blamed on
   density. Route at pad width, restore the carrying width afterwards.
2. **Net class clearances against pad pitch.** A 0.30 mm clearance against a
   VSON-10's 0.255 mm pad gap is violated *inside the footprint*, before a
   track exists.
3. **DRC on the placed, unrouted board.** It found 721 errors on one board,
   three of them real defects, long before there was anything to route.
   Placement errors are cheap; routed-board errors are not.
4. **`_ThermalVias` footprint variants.** The via array punches through to the
   other side and lands on whatever is opposite — 47 shorting pairs on one
   board, and it would have reached fabrication. Check the opposite side under
   every exposed pad.

Also: where a keep-out in a layout script mirrors a footprint dimension, read
it from the footprint rather than writing the number down. A keep-out at
6.60 mm guarding pads at 8.50 mm protects bare laminate and leaves the pads
exposed. `pcb-lint --keepout J5=6.60` checks a declared number against the real
footprint.

One fact worth holding before writing any board script: **net classes are not
in the `.kicad_pcb`.** They live in the sibling `.kicad_pro` under
`net_settings.classes`. A check that looks in the board file finds none and
reports the board clean.

And know which half of the toolchain you are in: **the schematic tools
are file-based; its PCB tools need a live KiCad.** When `check_kicad_ui`
reports `ipc_responsive: false`, scripted layout goes through KiCad's own
`pcbnew` Python API — the same object model, so still not text manipulation.

If the layout is going to be autorouted, read the freerouting section of the
reference first. Its CLI stop conditions do not work and it writes its output
only on a clean exit, so an unbounded run that you kill produces nothing at
all.

## Reporting

Publish the traceability output as an Artifact for anything the human will
share or act on — the coverage number, the table by level, and an explicit
list of what is not yet closed. Lead with the gaps, not the percentage.

**Draw it rather than tabulating it.** `hw-chart coverage` puts the gaps first
in every bar, which is the same rule in visual form; `hw-chart corners` shows
whether the evidence covers the corners or only nominal — a nominal-only result
has one bar and looks as thin as it is.

And put it where the human can actually see it. They are reviewing from
github.com while you work in a cloud VM, so the verification report belongs in
`docs/design/`, committed, with the ERC and DRC counts as numbers in the text.
Before claiming the design is done, open the review — see `hw-review`. A
verification report nobody has read is not a verification.

## Evidence from a design loop

Where a requirement was met by iterating rather than by a single run, cite
the accepted pass, not the loop: `hw-iterate status <loop> --gate` exits 1
unless the accepted iteration meets the target and names the run file it
was read from. That gate passing is what makes the loop's number usable as
evidence here. Attach the evolution chart to the verification review — see
`hw-optimize`.

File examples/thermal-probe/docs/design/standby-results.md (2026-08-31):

# Standby current — corner sweep

ngspice, deck at `sim/standby/standby.cir`, run 2026-08-27.
Cross-checked against the closed-form leakage sum (1.6 + 42 + 1 + 12 uA typ).

| Corner | Measured | Required | Margin |
|---|---|---|---|
| 25 °C, 3.7 V nom | 12.4 µA | ≤ 40 µA | +69% |
| −30 °C, 4.2 V max | 9.1 µA | ≤ 40 µA | +77% |
| +40 °C, 3.5 V min | 31.8 µA | ≤ 40 µA | +20% |
| +60 °C, 4.2 V max (beyond spec) | 58.2 µA | ≤ 40 µA | **−46% FAIL** |

The +60 °C corner is outside the `SYS-002` range of −30 to +40 °C and is
reported for information: it shows the margin is dominated by the reference's
temperature coefficient, so a hotter variant of this product would need the
reference gated rather than always on.

**Not yet varied:** the reference could be duty-cycled with the ADC instead of
running continuously, which would remove 42 µA of the 31.8 µA worst case
outright. That is the obvious lever and it has not been modelled.

`observations` was empty on all four runs — no singular-matrix or
convergence warnings.

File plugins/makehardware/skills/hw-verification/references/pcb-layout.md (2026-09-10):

# PCB placement, routing and fabrication

Every item here cost hours on a real board, and every one of them was
diagnosed as something else first — board density, outline geometry, keepouts,
layer types — because the actual cause is invisible from where you are
standing. Work the checks in order. They are cheap; the misdiagnoses are not.

---

## 0. Which tool drives the board

**Board work through IPC needs a live KiCad.** `kicad-python` (`kipy`) talks to
a running application, not a file, so in a headless session there is nothing to
connect to until you start one:

```bash
hw-kicad-up hw/board.kicad_pro     # Xvfb + KiCad, socket at /tmp/kicad/api.sock
kicad-python-smoke connect         # prove it answers before scripting against it
```

`ipc_connect=failed` means no KiCad, the API server disabled in preferences, a
busy KiCad, or a version mismatch. It is
never a reason to fall back to text-editing a `.kicad_pcb`, which is never
acceptable.

The offline route is the board file itself, one change at a time with a render
after each. That distinction is the one to hold on to: **schematic, usually
file-based; board, usually live.**

---

## 1. Before you place: check the net classes against the footprints

`pcb-lint --only PCB-TRACKW,PCB-CLEAR` now does both checks below in about a
second. Read this section anyway — the checks are cheap, and the reason they
exist is the expensive part.

**The net classes are not in the `.kicad_pcb`.** They live in the sibling
`.kicad_pro`, under `net_settings.classes`, with assignment through
`net_settings.netclass_patterns`. Grepping the board file for `net_class` finds
nothing on any KiCad 9 or 10 board, which reads as "no net classes, nothing to
check" and is how a whole check quietly becomes a no-op.

Nothing in KiCad warns you when a net class asks for something the parts on
that net cannot physically accept. It is not an error — it is simply
unroutable, and it presents as a router that returns almost every connection
as a failure with no explanation.

Two checks, both arithmetic:

**Track width against pad width.** A `Power` class at 1.20 mm and a `Rail`
class at 0.40 mm are correct current-carrying widths and both are impossible
to route: a QFN pin pad is 0.25 mm wide and an 0402 pad 0.5 mm, and a router
will not neck down to enter them. This is what "180 of 234 connections
unroutable" looks like.

**Clearance against pad pitch.** A `Power` class clearance of 0.30 mm against
a VSON-10's 0.255 mm pad-to-pad gap violates itself *inside the footprint*,
before a track exists. The part becomes unreachable and DRC reports clearance
errors within a component you have not touched.

```python
import pcbnew
board = pcbnew.LoadBoard("hw/probe.kicad_pcb")
for fp in board.Footprints():
    for pad in fp.Pads():
        net = pad.GetNetname()
        w = min(pcbnew.ToMM(pad.GetSize().x), pcbnew.ToMM(pad.GetSize().y))
        # compare w against the track width of the class carrying `net`,
        # and the smallest pad-to-pad gap in `fp` against its clearance
```

**The fix is to route at pad width and restore the carrying width
afterwards.** Set the class to something the pads accept, route, then widen
the tracks on the power nets and re-run DRC. Do not lower the current-carrying
width and leave it there — record in the layout notes what the final widths
must be, and check them at the end.

## 2. Run DRC on the placed, unrouted board

`pcb-lint hw/probe.kicad_pcb --gate` first, and DRC second — the linter catches
the things DRC has no opinion about (an unroutable net class, a via array over
the wrong copper, a decoupling loop) and it runs without KiCad.

Before there is a single track. It found 721 errors on one board — three of
them real defects — and every one of those three would otherwise have been
found after routing, when fixing them means re-routing.

```bash
kicad-cli pcb drc hw/probe.kicad_pcb --output build/drc-placed.rpt \
    --severity-error --severity-warning
```

Placement errors are cheap; routed-board errors are not. Read the report
before you route, not after.

## 3. Thermal-via footprint variants collide through the board

A `_ThermalVias` footprint variant contains a via array under its exposed pad.
Those vias **punch through to the other side** and land on whatever is there —
on one board, 47 shorting pairs against a MOSFET drain pad and a hall-sensor
network. Nothing in the placement flow knows a footprint contains vias, and
`score_placement` will not tell you: it reasons about courtyards, and a via is
not a courtyard.

During placement review:

```bash
grep -l "ThermalVias" hw/*.kicad_pcb hw/**/*.kicad_mod
```

For every footprint whose name contains `ThermalVias` (or that has pads of
type `SMD` with a drill, or any `pad` on `*.Cu`), **look at what is directly
opposite it on the other side**. Either move the opposite-side parts clear,
strip the vias from the variant and place your own, or use the plain variant.

This one reaches fabrication if you do not check it.

## 4. Derive keep-outs from footprints, never from a remembered number

A keep-out written as `RING_R = 6.60` while the footprint it is guarding
(`MOTOR_TERM_RING_8_D17mm`) places its pads at 8.50 mm protects bare laminate
and leaves the actual pads exposed — and parts get placed on four of them.
DRC finds it; inspection does not, because the number looks plausible.

Read the dimension out of the footprint:

```python
fp = board.FindFootprintByReference("J5")
r = max((pad.GetPosition() - fp.GetPosition()).EuclideanNorm()
        for pad in fp.Pads())
keepout_r = pcbnew.ToMM(r) + clearance_mm
```

Wherever a constant in a layout script mirrors a footprint dimension, it will
drift the first time the footprint changes, and nothing will say so. Read it.

## 5. Placement checks worth doing by hand

* **A bounding-box courtyard check lies about annular parts.** Any automated
  overlap score that works from bounding boxes — including one you write —
  reports an annular footprint (a motor terminal ring, a connector shell with a
  central cutout) as solid, so anything inside the ring comes back as a
  courtyard overlap. On one board that was four 24 mm² "overlaps" where the
  real copper clearance was 1.45 mm. Read the courtyard polygon before
  believing a hard failure on an annular or L-shaped part, and note that a
  deterministic check does not change on a re-run — re-running is not a test.
* **Fill the whole argument set from the first error.** Board-editing APIs
  validate one field per call, so a partially-specified edit gives you a chain
  of rejections one at a time. Read the API's expectations once and build the
  complete call, rather than fixing one field per round trip.

---

## 6. Autorouting with freerouting

Two defects in freerouting 2.1.0 and one in KiCad's DSN export make this
process fail in ways that look like board problems.

### 6a. KiCad's DSN export writes fractional coordinates into an integer file

The header declares `(resolution um 10)` — integer tenths of a micron — and
then arc tessellation in the board outline emits values like `78497.5`.
freerouting does not report a parse error. It reports *"the maze search
algorithm could not be created"* for **every** connection and routes nothing,
which reads exactly like an outline or a keepout problem.

**Always round-trip the DSN before using it:**

```bash
kicad-cli pcb export specctra hw/probe.kicad_pcb --output build/probe.dsn

python3 - <<'PY'
import re
src = "build/probe.dsn"
text = open(src).read()
# The resolution line says the file is integers. Make that true.
fixed, n = re.subn(r"(?<![\w.])(-?\d+)\.\d+(?![\w.])",
                   lambda m: m.group(1), text)
open(src, "w").write(fixed)
print(f"integerised {n} coordinate(s)")
PY
```

If that prints a non-zero count, the file you were about to route was
invalid. Check the count every time: it is the cheapest possible test and it
saves an hour of testing the board instead of the file.

### 6b. freerouting ignores every stop condition, and only writes on a clean exit

None of these bind: `-mp 60` (ran to pass 79), `router.max_passes` in
`freerouting.json`, `optimizer.max_passes: 0`, `job_timeout: 00:20:00` (a run
asked for 30 passes was at pass 67 after 22 minutes).

That would merely be annoying, except the session file is **written only when
the job ends cleanly**. An unbounded run that you kill produces **nothing at
all** — a route that had reached 75 unrouted of 234 was lost three separate
times this way.

**Drive it through its API server instead**, where the job result can be
fetched without waiting for the process to exit:

```bash
java -jar freerouting.jar --gui=false --api_server=true --port=37864 &
# POST the session, poll the job, GET the output when the pass count or the
# unrouted count stops improving — and keep every intermediate result.
```

If you must use the CLI, treat every run as disposable and snapshot whatever
it has produced before it can be lost. A partial route you still have beats a
better one you do not.

### 6c. Do not blame the board first

The order to check, when freerouting routes nothing:

1. The DSN round trip above — is the file actually integers?
2. Net class widths against pad sizes (§1) — can a track physically enter?
3. Net class clearances against pad pitch (§1) — is the class self-violating?
4. DRC on the placed board (§2) — is the placement legal at all?
5. Only then: the outline, the keepouts, the layer types.

That order is the reverse of the order they get investigated in, and the first
three cost about a minute each.

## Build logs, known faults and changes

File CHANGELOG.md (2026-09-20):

# Changelog

The version in `.claude-plugin/marketplace.json` and
`plugins/makehardware/.claude-plugin/plugin.json` is what a client uses to
decide whether it has an update to install. If it does not move, an existing
install treats `claude plugin marketplace update makehardware` as nothing to
do and keeps running the old code. So every change to `plugins/makehardware/`
bumps it, and `tests/version-bump.sh` fails the build when it does not.

## 0.13.0

The board documentation gate, the design at every zoom level, and CI.

### Added

* **Four rules that ask whether anybody can build, stuff, test and trace the
  board.** The nine layout rules ask whether it works. These ask about the
  half a contract manufacturer and a bring-up engineer see first — and the
  half that is invisible until the boards arrive and nobody can tell rev B
  from rev C. All four are computed off the board; none is a reminder.

  | | |
  |---|---|
  | `PCB-IDENT` | part number and revision in silkscreen, plus serial and date/lot fields |
  | `PCB-FIDUCIAL` | three global fiducials, not collinear, and one on the back if anything SMD is placed there |
  | `PCB-TESTPOINT` | every rail and bring-up signal reachable with a probe |
  | `PCB-PIN1` | a silkscreen polarity mark within 2 mm of pin 1 on every polarised part |

  `PCB-FIDUCIAL` measures collinearity as the height of the thinnest triangle
  the fiducials form, because three in a row fix no more than two do and the
  placer cannot tell you so. `PCB-PIN1` looks for silk geometry near pin 1 and
  is honest in the skill about being a proxy — right far more often than
  wrong, and the failure it catches is a part that was never marked at all.

  Tested in **both** directions: a board carrying PN, rev, serial, fiducials,
  test points and a pin-1 mark is silent, and the same board with each of
  those removed fails and names why. A gate that fires on everything teaches
  an agent to ignore it, which is worse than not having one.

* **The design strip.** The review page showed the architecture in one tab,
  the schematic in another and the enclosure in a third, so seeing what the
  thing *is* took three clicks and a good memory. It now sits in one row,
  coarse to fine — Architecture, Circuit, Board, Object — each opening its own
  tab for the detail. The circuit thumbnail is `sch-lint`'s overlay, found by
  name rather than hardcoded: a real `kicad-cli` plot is tens of thousands of
  elements and will not embed, and the overlay is a few hundred and was built
  for exactly this.

* **CI.** Six suites existed and nothing ran them, so `tests/version-bump.sh`
  — the check `CLAUDE.md` opens by insisting on — only fired when someone
  remembered to type it. That is the gap every gate here was built to close,
  left open in the repository itself. A workflow now runs all six plus
  `claude plugin validate --strict` on every push and pull request. It checks
  out with `fetch-depth: 0`, because `version-bump.sh` diffs against
  `origin/main` and a shallow clone would leave it nothing to compare and
  silently pass.

### Changed

* **`/hw-new-project`, `/hw-review` and `/hw-retro` no longer fire on the
  model's own initiative.** Each scaffolds a repository, commits and pushes,
  or files feedback; the plugin documentation names an unguarded side-effect
  command as an antipattern in as many words. `/hw-status` is read-only and
  stays model-invocable.

## 0.12.0

The review page now opens on the question a reviewer actually has.

### Added

* **The parameter board.** The page led with Stage 1 — a vision comparison
  signed off weeks ago — and scattered every number that says how the design
  is doing across ten tabs. A reviewer could not answer *"is this working?"*
  without clicking through all of them and holding the answers in their head.

  It now opens on a board: one row per key performance parameter, worst first.
  Where it sits, what it is allowed to be, how much room is left as a signed
  margin, and — where a design loop produced it — a sparkline of how it got
  there. Nothing on it is typed. The loop ledgers already carry objective,
  target, unit and trajectory; the block diagram already carries every rail's
  worst-case draw against what its source can supply.

  The rails come through `block_diagram.budget()` rather than off the YAML,
  because a rail carries the draw of every rail derived from it *referred
  through the voltage ratio* — re-deriving that on the page would be a second
  implementation of the one calculation most likely to be wrong, and the two
  would disagree the first time either changed.

  The board reports the **accepted** pass, not the last one. The last pass is
  only where the search stopped, and putting a rejected experiment on a review
  page as the design's figure is a specific way to mislead.

### Fixed

* **A value and the limit it is measured against picked different SI
  prefixes.** "250 uA against max 0.01 A" is arithmetic the reader has to do
  before they can make the comparison the row exists to hand them. The limit
  now sets the scale for both — it is the stable half of the pair, so the
  column does not change units as the design improves.

* **`0.01238 A` where an engineer reads `12.4 mA`.** The prefix threshold was
  tight enough to leave ordinary values unscaled.

* **The "tight" state borrowed `--wait`**, which is this page's blue for
  *waiting on your answer*. A rail at 90% of budget was rendering as a
  question for the reviewer rather than a margin to watch. There is a proper
  `--warn` amber now, defined in all three theme states — light, the
  `prefers-color-scheme` block, and the explicit `[data-theme="dark"]` stamp.
  It was missing from the third on the first pass, which is the classic
  token-defined-in-one-state bug and invisible until someone toggles a theme.

* **Rows were labelled with raw metric keys** — `i_standby_ua`, `wake_ms`. A
  reviewer should not have to read variable names, so the trailing unit token
  is dropped (the unit is in the next column) and the rest reads as a label.

## 0.11.0

The design loop was a diary. It is now a loop.

### Fixed

* **Every number on an evolution chart was typed in by the agent.**
  `hw-iterate record` took metrics on the command line, so each figure had
  been read off a simulator's output and retyped — a transcription, unchecked,
  of a number nobody could re-derive. `--evidence` named the file it came from
  and nothing ever opened that file. The chart looked like evidence and was
  testimony.

  That broke this repository's second founding rule, in its newest subsystem:
  *"Generated, not hand-written. Every number on a review page is read from
  the file that owns it. If you find yourself typing a figure into markdown
  that a tool could compute, that number is already wrong — it just does not
  know it yet."*

* **A pass that met its target by breaching a `--track` limit recorded as a
  clean `pass`.** `--track` exists precisely because an objective alone is a
  licence to wreck everything else to satisfy it, so the one trade the loop is
  open to catch was the one it recorded as a success. A derived verdict now
  downgrades it to `partial` and names the breached limit on the console.
  Found by rebuilding the worked example and reading the chart, not by reading
  the code.

* **"Best" meant best on the objective, breaches included.** It now means best
  among the passes that respected their limits, falling back to the overall
  best when none did. The verdict already carries the breach, so the chart and
  the ledger apply the same rule.

### Added

* **`hw-iterate run`** — executes the verifier, keeps its output as the
  evidence file, reads each number out with a named extractor, and records the
  pass. One call where there were four, and no figure passes through anyone's
  hands. The verdict is derived from the objective against its target and the
  tracked limits; `--verdict` overrides it for the case where the number is not
  the whole story.

* **`hw-extract`** — the extractors, usable on their own to get a spec right
  before wiring it into a loop:

  | | reads |
  |---|---|
  | `meas:NAME` | an ngspice `.meas` or `print` line — measured against ngspice 42, both forms |
  | `line:PREFIX` | the number after a literal prefix, e.g. Elmer's `ElectroMagnetic Field Energy:` |
  | `json:a.b.0.c` | a dotted path — build123d `measure()`, `req-trace --json` |
  | `csv:COL[:how]` | a column reduced by `last`/`first`/`max`/`min`/`mean`/`absmax` |
  | `re:PATTERN` | first capture group, for anything else |

  Every extractor fails loudly when its metric is absent. A loop that silently
  records nothing for a missing measurement is worse than one that stops,
  because the chart still draws and the gap does not show. `run` refuses to
  record a pass whose objective could not be read, rather than recording a
  hole.

* **`hw-iterate verify`** — re-derives every recorded number from the file it
  was read out of, and `status --gate` now fails on a figure that no longer
  reproduces. A deck edited after the run, an extractor that changed meaning, a
  number someone typed: all of it surfaces here instead of on a review page.
  Passes recorded by `record` carry no extractor and are reported as
  unverifiable rather than as wrong — `record` remains right for a bench
  reading or a scope photograph.

### Changed

* **The worked example's standby loop is now driven by `run`.** Its five
  passes come from a stand-in model that emits ngspice's own `.meas` format —
  the same convention `build-fixture.py` already uses for the vision renders —
  so `run` and `verify` take exactly the path they take against a real
  simulator. The run logs are committed, which is what lets `verify` pass on a
  fresh clone. Two of the five passes now read `partial`: they hit the current
  target by breaking the wake-up budget, which is the trade the whole chart
  exists to show.

## 0.10.0

`hw-repair` could repair two of the seven things `setup.sh` installs, and
`hw-repair kicad` installed the skill pack rather than KiCad. The phase most
likely to fail was the one it could not touch at all: `phase_python` pulls
`cadquery-ocp`, a ~400 MB wheel and by far the most likely thing in the build
to time out. A session learned its toolchain was broken and could do nothing
but wait for somebody to rebuild the environment.

### Added

* **`hw-repair python [group]`** — re-run one of `phase_python`'s install
  groups. The groups exist so one flaky dependency cannot take out the rest;
  this finishes the thought by letting a session re-run the one that failed.
  `hw-repair python` with no argument lists which groups import and which do
  not; `all-groups` does every missing one.

  It is more likely to work than the build was: the five-minute snapshot
  budget does not apply to a session, which is exactly the constraint that
  makes cadquery-ocp time out at build time.

  Three refusals, all deliberate. It **will not `uv venv`** — recreating
  `/opt/hw-py` to fix matplotlib would throw away a working strictdoc, and
  that is a rebuild, not a repair. It **resolves `uv` explicitly** across
  `/root/.local/bin` and `/root/.cargo/bin` and fails loudly when it is
  absent, with **no pip fallback**, because `uv venv` creates a venv without
  pip and `python -m pip` then fails with an error that explains nothing. And
  it **verifies by import**, not by exit code — a resolver can succeed and
  leave an import broken, which is a different problem with a different fix.

* **`hw-repair base`** — re-install `phase_base`'s package set.

* **`env/bootstrap.sh`** — bring a container up from nothing.

  Not a `hw-repair` subcommand, and it cannot be one: `hw-repair` ships inside
  the plugin, so a container bare enough to need a bootstrap does not have it.
  The only entry point that works from nothing is a URL, so that is what it is:

  ```bash
  curl -fsSL https://raw.githubusercontent.com/Harwasch/MakeHardware/main/env/bootstrap.sh | bash
  ```

  It installs `uv` if the container lacks it, fetches the same `setup.sh`, and
  runs it with KiCad and magnetics off unless you pass `--full` — those are
  minutes each and both need `ppa.launchpadcontent.net`, and failing there
  should not cost you the Python environment too. This is the Codex path,
  where the plugin manifest imports but there is no environment dialog and no
  setup-script field, so the skills arrive and the tools they name do not.

* **`tests/python-groups.sh`** — `setup.sh` and `hw-repair.sh` still agree
  about what installs what.

  They cannot share a definition: `setup.sh` is pasted into the environment
  dialog as one self-contained file and cannot source anything from this repo,
  while `hw-repair.sh` ships inside the plugin. So the tables are duplicated
  and checked instead of hand-synced, which is the same answer
  `tests/version-bump.sh` gives for the two version files.

### Changed

* **`phase_base` installs `socat`.** `claude plugin eval` runs any Bash it
  grants under an OS sandbox and needs bubblewrap *and* socat. `bwrap` is in
  the image; socat was not, and without it every sandboxed run refuses rather
  than running unconfined — which reads as the eval being broken rather than
  as a missing package.

* **`phase_plugin` merges the permission allowlist into
  `/root/.claude/settings.json` at user scope.** This is the fix 0.9.0 could
  not make. A cloud session has no trust dialog, an untrusted workspace
  ignores project-scope `permissions.allow` entirely, and so the three
  checked-in `settings.json` files — the ones 0.9.0 corrected — do nothing
  there. This is the copy that is actually read.

  Merged with `jq`, never overwritten: that file may already hold the user's
  own settings, and clobbering those to add a convenience is a bad trade. A
  file that does not parse is left alone rather than replaced.
  `tests/settings-allowlist.sh` now checks this fourth copy of the list too,
  including that `hw-repair` stays out of it.

* **`hw-repair` says where the line is, and `hw-doctor` and the docs agree.**
  A repair reaches anything consumed by a **subprocess it spawns** — apt
  packages, Python packages, cloned repos, `/usr/local/bin`. It reaches
  nothing consumed by the **session's own tool registry** — MCP servers,
  skills, slash commands, `bin/` on PATH, environment variables — because
  those are read once at session start.

  That distinction is why `hw-repair python cad` now prints, in as many
  words, that it fixed `build123d` for scripts and did **not** fix the
  build123d MCP server, which lives in its own venv and whose process started
  with the session. Without the line, the agent repairs, sees no MCP tools,
  and concludes the repair failed when it did not.

  `hw-repair bootstrap` is a recognised argument purely so it can explain
  why it does not exist and point at `env/bootstrap.sh`.

## 0.9.0

The loop back to this repository had no plumbing in it. `hw-retro` has told the
agent to "offer to file the proposed changes as a GitHub issue on
`Harwasch/MakeHardware`" since 0.5.0 and never named a mechanism, because there
isn't one: `gh` is not in the environment, and a cloud session's GitHub token is
scoped to the project repo, so it cannot reach this one at all. Every retro that
ever ran finished by offering something impossible.

### Added

* **`hw-feedback`** — a finding about the toolbox becomes a record here and an
  issue there.

  The design decision worth arguing with: **an issue tracker is the right place
  to publish a finding and the wrong place to capture one.** Issues are good at
  what nothing else gives free — evidence accumulating on one finding,
  discussion, labels, search, PR linkage. They are bad at capture, because they
  want an account, a browser and a context switch at exactly the moment —
  mid-work, mid-correction — when a finding is cheapest to write down and most
  likely to be lost.

  So capture is local and always, and publication is batched at the retro:

  ```bash
  hw-feedback new --file skills/hw-sourcing/references/connectors.md \
      --title "Connector choice is relitigated every project" \
      --edit "Fill in the board-to-wire row with Molex PicoBlade, and say why" \
      --evidence "friction log 2026-08-28; commits a1b2c3, d4e5f6"
  hw-feedback list       # every record and its state
  hw-feedback publish    # prepare the unpublished ones
  hw-feedback mark <slug> <url>   # where it actually went
  ```

  `new` writes `docs/design/feedback/<date>-<slug>.md` in the project repo with
  no network and no credentials. `publish` prepares one issue for the batch:
  a prefilled link, a dedup search, and the body to paste. It **prepares** —
  it prints `NOT FILED` and the skill forbids the word "filed", because
  claiming an issue exists when what exists is a URL is the kind of wrong
  nobody catches until they go looking for it. Where the session does have a
  working `gh` channel to this repo, which locally it often does, it files
  directly and marks the record itself.

  Two things it does deliberately. It **inlines evidence rather than linking**
  — the project repo is usually private, so a blob URL 404s for whoever has to
  act on the finding. And it **prefills a summary, not the issue**: GitHub
  answers an over-long GET with 414 and percent-encoding inflates markdown
  1.8-3.0x, so a real finding does not fit in a URL. The form arrives
  pre-addressed and the body is pasted.

  The gate is structural and nothing more: a `--file` that resolves under the
  plugin, a non-empty `--edit`, a non-empty `--evidence`. Whether a finding is
  about the system or about one design is a judgement, it is carried in
  `hw-retro`, and a keyword classifier would get it wrong in both directions.

* **`.github/ISSUE_TEMPLATE/`** — the form `hw-feedback` prefills, plus a
  `config.yml` keeping blank issues on, because adding the directory turns on
  the template chooser for everyone filing by hand.

* **`tests/feedback.sh`** — the gate refuses an observation with no named file;
  the URL's query parameters round-trip back to the exact input text; every
  parameter names a real field `id`; the `kind` value is an exact option match;
  an oversize finding still yields a clickable link. The last three are the
  silent ones: GitHub prefills a form by matching the query parameter name
  against the element's `id`, and a name or a dropdown value it does not
  recognise renders the field blank with no error on any side.

* **`tests/settings-allowlist.sh`** — every tool in `bin/` is allowed in all
  three settings files, the three lists agree as sets, and no doc page quotes
  an entry that does not exist.

### Fixed

* **The friction log is scaffolded.** It was documented in three places —
  `docs/design/README.md`, the project `CLAUDE.md`, and `hw-retro` — and
  created by nothing, so `/hw-retro` step 1 read a file that never existed.
  `templates/project/` now carries it, along with `docs/design/feedback/`, and
  `tests/smoke.sh` asserts both survive a scaffold.

* **Six tools were missing from every allowlist.** `sch-lint`, `pcb-lint`,
  `hw-chart`, `cad-export`, `review-artifact` and `hw-iterate` — which is to
  say every gate added after the list was first written — prompted for
  permission on every call. The cost was not one prompt: the gates are what an
  agent runs most often, so the omission taxed exactly the workflow the gates
  exist to enforce.

  `hw-repair` is deliberately **not** added. It writes apt sources, imports GPG
  keys and installs packages as root; the prompt is the review. The test
  asserts it stays out, with the reasoning in its header, so the omission does
  not get "fixed" later.

  Worth knowing what this does not fix: a cloud session's workspace is
  untrusted, and an untrusted workspace ignores project-scope
  `permissions.allow` entirely. The durable fix is at user scope from the
  setup script, and it is not in this release.

* **`KI_STACK_DIR` is gone from `env/environment-variables.env`.** It belonged
  to ki-stack, the pack 0.8.0 replaced, and pointed into `/opt/ki-stack` —
  which `hw-repair kicad` now deletes as a leftover. Anyone pasting the current
  file into a new environment was setting a variable aimed at a directory the
  repair tool treats as stale.

  Removing it only helps environments built from here on. That file is pasted
  into the environment dialog once and the dialog is the source of truth
  afterwards, so an environment that already sets it still does. `hw-doctor`
  now says so when the path does not exist, which is the only thing that
  reaches a running session.

### Changed

* `scripts/_gh.py` — `repo_slug`, `head_ref`, `blob_url` and `uncommitted`
  moved out of `review_gate.py`, which imports `yaml` at module level.
  `hw_feedback.py` is stdlib-only on purpose: it is the tool you reach for
  *because* the Python environment degraded, so depending on `/opt/hw-py`
  having landed would make it fail in exactly the session that produced the
  finding. `review_gate` re-exports them, so `plan_render` and
  `review_artifact` are unchanged.

## 0.8.0

The KiCad skill pack is now [KiStack](https://github.com/American-Embedded/KiStack)
(American Embedded) rather than [ki-stack](https://github.com/Milind220/ki-stack)
(Milind220). Both are skills, not servers, so the argument in 0.7.0 stands
unchanged — this is a choice between two skill packs, not a change of
architecture.

### Changed

* **KiStack replaces ki-stack.** They are different books. ki-stack is a manual
  for the *substrates* — how to route between live IPC, `kicad-cli` and
  structured file edits. KiStack is house practice from a working shop: what a
  good schematic looks like, how to place before routing, when a pin swap is
  worth it, how to read a Gerber. This toolbox already answered the substrate
  question in `hw-schematic` and `hw-pcb-layout`; what it did not have was the
  craft.

  Ten skills — `kicad-schematic`, `kicad-pcb`, `kicad-layout`, `kicad-symbol`,
  `kicad-footprint`, `kicad-bom`, `kicad-export`, `kicad-gerbers`,
  `kicad-panelize`, `pcb-product-render` — plus a reference page for every
  `kicad-cli` verb, which is the fastest way to get an export flag right.

* **A conflict table, because there is a real conflict.** KiStack overlaps
  `hw-schematic` and `hw-pcb-layout` and disagrees with them in places. The
  rule is **the gate wins** — `sch-lint`, `pcb-lint` and `review-gate` are what
  actually fail a stage, and advice that reads well while failing a gate is not
  shippable. `hw-schematic/references/kicad-channels.md` names the three
  collisions:

  - **Sheet strategy.** KiStack prefers one big sheet you can see at once; this
    toolbox derives a sheet plan from the agreed block diagram. Take the sheet
    plan: `sch-lint --plan` binds every sheet to an architecture a human signed
    off, and a single huge sheet does not render on the review page.
  - **Changing the schematic during layout.** KiStack says do the pin swaps.
    Correct — and `review-gate` will mark the schematic review stale, which is
    also correct. Do it, then re-open the review.
  - **Autorouting.** No conflict; both say manual first.

  One that people expect to collide and does not: KiStack's 50 mil label text
  is exactly the house `text_size_mm: 1.27` that `SCH-TEXTSIZE` checks.

* Skills are linked under their **frontmatter** names, not their directory
  names — `skills/schematic/` declares `name: kicad-schematic`, and frontmatter
  is what the agent sees.

### Fixed

* **`hw-repair kicad` no longer eats the pack it just installed.** Konnect
  shipped skills called `kicad-schematic` and `kicad-pcb`; so does KiStack. The
  leftover cleanup matched on filename, which would have deleted the new pack
  along with the old one. Those two names are now matched on **content** —
  only Konnect's own skills mention Konnect — and `tests/smoke.sh` covers it
  with a fixture that fails if the check ever regresses to name matching.

* `hw-repair kicad` also clears ki-stack's 0.7.0 leftovers: its nine
  `ki-stack-*` skills, its twelve `/usr/local/bin` wrappers (which pointed into
  a clone about to be deleted), the clone itself, and the `KI_STACK_DIR` export
  in `.bashrc`. Measured on this container: 22 leftovers removed.

## 0.7.0

Konnect is out; [ki-stack](https://github.com/Milind220/ki-stack) is in. The
plugin no longer ships a KiCad MCP server at all.

### Changed

* **KiCad automation moved from a tool surface to a substrate.** Konnect was an
  MCP server — one Rust binary, 214 tools over KiCad 10's IPC API. ki-stack is
  nine SKILL.md files and a dozen shell helpers that teach the agent to drive
  the three real substrates itself: `kicad-python` for live IPC,
  `kicad-cli` for render/export/DRC/ERC, and `kiutils-rs` for structured
  offline file edits.

  The argument is what `kicad-cli` cannot do. It has no `add`, `place`, `route`
  or `connect` verb, so *something* has to drive the IPC API; the only question
  is whether that something is pre-sliced verbs or code the agent writes. Two
  things settled it: a tool surface costs context whether or not it is used
  (Konnect loaded 2 of its 20 toolsets at startup and made the agent fetch the
  rest, which failed in ways that read as "the tool is missing"), and a missing
  tool is a wall where a skill that names its fallback is a route — the same
  reasoning `hw-optimize` already applies to everything else.

  **What it costs:** Konnect's design-review audits and its manufacturing
  pipeline have no ki-stack equivalent. `sch-lint`, `pcb-lint`,
  `hw-verification` and kicad-happy already covered most of that ground, which
  is why the loss is acceptable — but it is a loss, not a wash.

* **The rule about editing `.kicad_*` files changed shape.** It was "nothing
  writes one except KiCad or Konnect". It is now "nothing writes one except
  KiCad, its IPC bindings, or a structured parser that round-trips it".
  Parser-backed offline edits are a first-class route now, and for schematic
  work usually the better one. Hand-rolled S-expression edits — `sed`, a regex,
  a string replace — are as forbidden as they ever were, and for the same
  reason: the file still opens and the netlist is quietly wrong. The
  distinction is structural versus textual, not tool versus file.

* **`MH_ENABLE_KONNECT` is now `MH_ENABLE_KICAD`.** The old name is still
  honoured, so an environment carrying it keeps working rather than silently
  losing KiCad. `MH_KONNECT_FROM_SOURCE` is gone — nothing is built from source
  any more, which also drops `cmake`, `pkg-config` and the protobuf toolchain
  from the base packages.

* `templates/kicad/konnect-house.json` is now `house-defaults.json`, merged
  into the project's `.kicad_pro` (plain JSON) rather than loaded through an
  MCP call.

### Added

* **`hw-repair kicad`** — installs ki-stack and deletes the Konnect leftovers.
  This is the important half of the migration: an environment built before
  0.7.0 still carries Konnect's six skills and two agents in its snapshot, and
  they are worse than absent. They tell the agent that every `.kicad_*` change
  MUST go through MCP tools that are no longer registered, so it reads a
  missing tool as a broken environment and stops, instead of reaching for the
  `kicad-cli` and IPC bindings sitting right there. `hw-doctor` flags the
  leftovers and names the command.

### Fixed

* **A wrapper generator that ate the thing it wrapped.** The first cut of the
  ki-stack phase wrote `/usr/local/bin/<helper>` with `cat >`, over a path a
  previous install had left as a symlink into the clone. `cat >` follows a
  symlink, so the wrapper landed *inside* the upstream script as an `exec` of
  itself — an infinite loop that hung the build with no error at all. `rm -f`
  before the write. Caught by running the phase twice.

* Seven ki-stack helpers locate the pack with `dirname "${0}"/../../..`, which
  under a symlink in `/usr/local/bin` resolves to `/`. They are installed as
  wrappers rather than symlinks so `ki-stack-version` and `kicad-render` work
  from any directory.

## 0.6.0

### Removed

* **The Onshape FeatureScript MCP server**, added one release ago in 0.5.0.
  The server entry is out of `.mcp.json`, the `onshape` section is out of
  `hw-cad`, `fs-mcp.labs.onshape.app` is out of the allowlist, and the
  reachability probe is out of `hw-doctor`. `build123d` was already the
  default CAD path and is unaffected — nothing else in the toolbox depended on
  Onshape.

  A minor bump rather than a patch: anyone who installed 0.5.0 and started
  calling the `onshape` tools loses them, and 0.x treats that as breaking even
  when the window was hours. Rebuild the environment to drop it; a session on a
  0.5.0 snapshot keeps the server until then. If you kept
  `fs-mcp.labs.onshape.app` on a Custom allowlist, it is now dead weight rather
  than a problem.

  This removes the *plugin's* wiring only. An Onshape connector attached to a
  claude.ai account is a separate thing and is untouched.

## 0.5.0

Two tools that had never worked, one that failed for a reason nobody had
looked at, a CAD path the human can open in a browser — and the loop itself:
an agent iterating toward a target now leaves a record a reviewer can check
instead of a number they have to trust.

### Fixed

* **Elmer had never installed. In any session, in any environment.** The
  pinned tarball URL — a release asset on this repository — 404s, and always
  did: there are no releases on this repository at all. `phase_magnetics`
  degraded on every build, and because a degraded phase still exits 0 the
  environment came up looking healthy with no `ElmerSolver` in it. It now
  installs `elmerfem-csc` from the upstream elmer-csc PPA, which is on
  `ppa.launchpadcontent.net` — the host KiCad 10 already needs, so it costs no
  new allowlist entry. Verified end to end: v26.2, ~70 s, and a coupled
  magnetostatic/thermal/stress solve of `CoilOnIronCore` in 16 s. The packaged
  build is self-contained, so the `LD_LIBRARY_PATH` export the old one needed
  is gone from both the setup script and the `hw-magnetics` skill.

* **Konnect's two subagents launched with no tools.** `konnect init` writes
  them with `tools: [mcp__konnect__*]`, which is right for a standalone
  install and wrong for ours: Claude Code namespaces a plugin's MCP servers,
  so under this plugin every Konnect tool is
  `mcp__plugin_makehardware_konnect__*` and that glob matched nothing. The
  agents did not error — they came back having "reviewed" a board they could
  not open, which is the worst shape a failure can take. Both patterns are now
  written, at build time and by `hw-repair konnect` for environments already
  snapshotted with the broken files.

* **`hw-doctor` reported build123d as failed when it was fine.** Its first
  import pulls in OCCT and takes ~25 s cold; the probe timeout was 20 s, so
  the one command whose job is to say whether the toolchain works said the CAD
  stack was broken. Ceiling raised to 45 s.

* **An ad-hoc review showed its questions and none of its evidence.** A review
  with no `STANDARD` phase of its own — a design loop, a simulation campaign —
  rendered its title, summary and questions on the review page and dropped its
  artefacts. They were on the markdown packet, but the page is what the
  request links to first.

### Added

* **`hw-optimize` and `hw-iterate` — the closed design loop.** An agent given
  "get the phase margin above 60 degrees without losing the bandwidth" changes
  a value, simulates, reads the number and repeats; by default none of that
  survives, and the repository ends up with the last netlist and a sentence
  claiming a figure. `hw-iterate` records every pass — the variables changed,
  the metrics measured, and the run file each number was read out of — and
  `hw-chart evolution` draws the trajectory: the objective against its target,
  each tracked metric against its own limit, and a strip of which knob moved
  when. A reviewer reads three things off it that no paragraph delivers: that
  it converged rather than stopped, which change bought the improvement, and
  what it cost elsewhere.

  `--track` is the half that matters. An objective alone is a licence to wreck
  everything else to satisfy it, and a loop that does exactly that looks like a
  success from the inside. `hw-iterate record` says when the last three passes
  are within 2% of each other — the signal to change approach rather than run a
  fourth variation of the same idea — and `status --gate` exits 1 unless the
  accepted pass meets the target and names its evidence.

* **The perseverance/escalation policy**, in `hw-optimize`. The two failure
  modes are symmetric: an agent that stops at the first obstacle wastes the
  human's time on things it could have solved, and one that never stops burns a
  day building the wrong thing confidently. The line is drawn where a
  well-informed human could reasonably disagree with either answer — that is a
  decision, and it goes to them. A missing tool, a failed solve, an approach
  that did not work: those are obstacles, and they are the agent's.

* **The Onshape FeatureScript MCP server**, at
  `https://fs-mcp.labs.onshape.app/mcp`. Claude Code runs the sign-in on first
  use, against the human's own account. build123d stays the default — it is in
  the repository, it diffs, and `cad-export --check` gates it; Onshape is for a
  live CAD document the human keeps working in, and for authoring reusable
  custom features, which build123d has no equivalent of. `hw-cad` carries the
  comparison and the warning that every call spends the account's Onshape API
  allocation.

* **`hw-repair`** — run-time repair for what the environment build missed.
  The environment is a snapshot taken once, before any session starts; when a
  phase degrades, every session made from it is missing the tool and the clean
  fix is a rebuild that an agent mid-task cannot do. `hw-repair elmer` is
  ninety seconds. `hw-doctor` now names it where it would help.

* **`hw-schematic/references/kicad-channels.md`** — which of Konnect,
  `kicad-cli` and the lint tools may touch a `.kicad_*` file, and the recovery
  list to work before escalating a Konnect failure. It also answers the
  recurring question with a fact: `kicad-cli` has no `add`, `place`, `route` or
  `connect` verb on KiCad 10, so there is no direct CLI to use instead of
  Konnect. Konnect authors; `kicad-cli` exports and checks, and you may call it
  yourself for those.

### Changed

* **`review-gate` now enforces concision.** A 60-word budget on `--summary`, 25
  on each question, and 80 words per viewable artefact. Over budget on the
  first two and the review is refused before the packet is written — the fix is
  always to shorten text that has not been sent yet, or to generate the figure
  that makes the words unnecessary. The worked example's five reviews run 24-46
  words of summary and 5-14 a question, and none of them are thin. `--long`
  overrides it, and every use of it is a review somebody skimmed.

* **The example project now carries a design loop.** `examples/thermal-probe`
  ends its standby write-up with "the reference could be duty-cycled ... that
  is the obvious lever and it has not been modelled". It is modelled now, as
  five recorded passes: #2 met the current target and was rejected on wake
  time, #4 was better still and rejected harder, and the accepted pass is not
  the best one on the objective. That is the shape the chart exists to show.

## 0.4.0

Drawings somebody can read, files somebody can open, and pictures instead of
paragraphs. The plugin had fourteen skills and none of them was about drawing:
Konnect will place a symbol anywhere it is told to, and nothing had an opinion
about where.

### Added

* **`hw-schematic`** and **`sch-lint`** — house practice for a readable
  drawing, and fourteen checks that measure it: the 1.27 mm grid, orthogonal
  wires, sheet density against the review page's budget, named nets, rails up
  and grounds down, one text size, hierarchical pins matching their labels,
  decoupling drawn beside the pin it serves, designators in reading order,
  and `--plan`, which binds every sheet back to the block diagram the human
  agreed to. `--svg` draws every finding on the sheet — 340 elements against
  the 60,538 KiCad's own plot of that sheet costs.

* **`hw-pcb-layout`** and **`pcb-lint`** — the prose in
  `hw-verification/references/pcb-layout.md` turned into arithmetic that runs.
  A thermal-via array landing on opposite-side copper, a net class no pad on
  its nets can accept, a clearance that violates itself inside a footprint, a
  keepout written from memory, decoupling loops ranked worst-first, silk on
  pads, unreadable designators, courtyard overlap by real polygon area, and a
  signal layer with no reference plane.

* **`hw-cad`** and **`cad-export`** — assemblies rather than one unnamed
  solid. STEP AP242 with the tree, part names, colours and a named datum at
  every joint; GLB for the review page's orbit viewer; STL for GitHub's own 3D
  viewer, the only 3D format it renders; 3MF for print; `joints.json`; a
  FreeCAD 1.0 macro that rebuilds the assembly with real, draggable joints;
  and renders assembled, exploded, sectioned and isometric. The gate fails on
  a part with no label, no colour, or no joint reaching it.

* **`hw-visuals`** and **`hw-chart`** — the seven plots the workflow needs, to
  one set of rules: direct labelling rather than a legend, the limit drawn
  beside the value, the anomaly annotated, small multiples on one shared
  scale, and state never carried by colour alone. Two to seven kilobytes of
  themed SVG each.

* **The review page became usable.** Scroll-to-zoom and drag-to-pan on every
  figure, an orbit viewer for a `.glb`, sortable tables. A plotted A4 sheet
  squeezed into a browser column is legible as a shape and unreadable as a
  document; that is the difference between a picture of a schematic and a
  schematic.

* **House KiCad templates** — an A3 drawing sheet whose every field is a KiCad
  text variable, and the grid, text sizes and net classes as Konnect config.

* **`block-diagram --summary --csv`**, so the power budget chart comes from the
  same numbers the table prints rather than from a retyped copy.

### Notes

Nine things were found by measuring rather than by reading, and each is
written down where it will be met again — the plugin's own `CLAUDE.md`, the
skill that owns it, or the script's docstring. The ones that would have
silently produced wrong output:

* **Net classes are not in the `.kicad_pcb`.** They are in the sibling
  `.kicad_pro`. A board linter written to the obvious design reports every
  board clean.
* **STEP AP242 cannot be selected from outside `build123d`.** `export_step`
  resets `write.step.schema` partway through its own body, so setting it
  returns True and changes nothing.
* **`Compound(children=[...])` reparents.** Building a second compound from an
  assembly's children empties the assembly, and every export after it writes a
  few hundred bytes of nothing.
* **KiCad's page-layout parser rejects `;;` comments**, and on a parse error
  `kicad-cli` prints one line to stderr, exits 0, and plots with the built-in
  frame.
* **Sheet size cannot be estimated from character count** — the two committed
  example sheets measure 60 and 29 SVG elements per rendered character. So
  `sch-lint` shells out to `kicad-cli` and measures; the estimate only warns.
* **GitHub's 3D viewer renders `.stl` only.** Not `.step`, not `.glb`.

## 0.3.0

Magnetics. SPICE cannot tell you an inductance; now something can.

### Added

* **`hw-magnetics`** — a skill for field simulation: which of FastHenry,
  Elmer, GetDP, Gmsh, CalculiX and magpylib answers which question, and the
  ten or so ways each of them returns a wrong answer without saying so. It is
  a separate skill from `hw-simulation` on purpose: that skill's triggers are
  circuit words, and one skill that fires on both "check the bias point" and
  "what is the coupling coefficient" would be wrong about one of them.

* **`phase_magnetics` in `env/setup.sh`** — Elmer 26.2, FastHenry 3.0.1 and
  GetDP 3.2.0. Measured at ~3 minutes, run concurrently with the KiCad and
  Python phases, and needing nothing outside the existing allowlist. Elmer
  comes from a prebuilt tarball because it is not in the Ubuntu repos and its
  PPA is off the allowlist; building it from source is ~20 minutes, which does
  not fit the build budget. `MH_ENABLE_MAGNETICS=0` turns the phase off.
  Also clones `elmer-elmag`, because `.sif` is a niche format whose failure
  mode is a solver that runs happily and reports zero — copy a working file.

* **`hw-doctor`** reports the four new tools and whether the worked `.sif`
  cases are present.

### Notes

Everything above came out of the `wpt-pcb-coils` demo in
[MakeHardwareDemos](https://github.com/Harwasch/MakeHardwareDemos), which
reverse-engineers a wireless-power coil from the physical part. Six of the
gotchas in the skill are silent-wrong-answer paths found there, including
FastHenry writing `nan` into its output while exiting 0, and an Elmer
homogenised winding behaving as turns in parallel and reporting an inductance
33 % low with the mesh fully converged.

## 0.2.0

Human review, and a review page the human actually reads.

### Added

* **`review-gate`** — the sign-off ledger. Every milestone (vision, plan,
  requirements, architecture) and every design stage records what the human
  agreed to, in their words, against the digest of the artefacts they saw. A
  tracked artefact that changes afterwards makes the review **stale** and the
  gate fails, because a sign-off against a moving target is not a sign-off.
  `plan-render --check` refuses to call a chunk `done` while its review is
  open or stale.
* **`review-artifact`** — builds `docs/review/artifact.html`, one page per
  project with a tab per phase, published as a Claude Artifact. Every figure
  and number is read from the file that owns it; nothing on the page is typed
  by hand.
  * `--init` writes `docs/review/artifact.yaml` from what the repo contains,
    with the stages whose artefacts do not exist yet commented out.
  * `--check` exits 1 naming anything it cannot show, which is much cheaper
    than the human finding out.
  * `--url` records where the page was published, so later sessions update it
    instead of creating a second page.
* **`.drawio` alongside every generated diagram**, with *Open in draw.io*
  under the picture — one click to an editable diagram, nothing to install.
* **Manufacturing release checklist** — the documents a run needs, grouped,
  with a present/missing tally. Rows for documents that do not exist yet stay
  listed, because that is the whole value of a checklist.
* **`tests/real-tool-output.sh`** — what the review page does with real
  exporter output rather than tidy fixtures.
* **`tests/version-bump.sh`** — this file's reason for existing.

### Fixed

* **An A4 schematic rendered 331 px wide.** KiCad writes the page size in
  millimetres twice meaning different things — `width="297.0022mm"` is the
  intrinsic size, `viewBox="0 0 297.0022 210.0072"` is the user-unit system —
  and the inliner preferred the viewBox.
* **SVG had no size budget.** KiCad emits one `<path>` per line segment,
  including every stroke of every character, so one dense sheet is 3.0 MB and
  61,681 elements. Now budgeted per figure and across the page, with anything
  over reported rather than silently inlined.
* **Light-background plots on a dark page.** A full-page light fill is
  detected and matted, the way an opaque raster already was. Recolouring it
  would misrepresent the artefact.
* **KiCad 10 names its layer groups** (`<g id="Wire">`), so two sheets on one
  page collided on ids that repeat in every project.
* **Power budget added child-rail currents without referring them** through
  the voltage ratio, so a 400 V rail's headroom was computed from 48 V amps.
* **Wrapped list items split into separate paragraphs**, and ordered lists
  were not supported at all — which turned an assembly traveller into one
  run-on paragraph.
* **An inlined `@media` block leaked the exporter's dark palette** onto the
  whole page and unbalanced the CSS.

## 0.1.0

First release as a plugin: the vision, planning, requirements, architecture,
sourcing, simulation, verification and documentation stages, with
`plan-render`, `req-trace`, `block-diagram`, `vision-board` and `hw-doctor`.

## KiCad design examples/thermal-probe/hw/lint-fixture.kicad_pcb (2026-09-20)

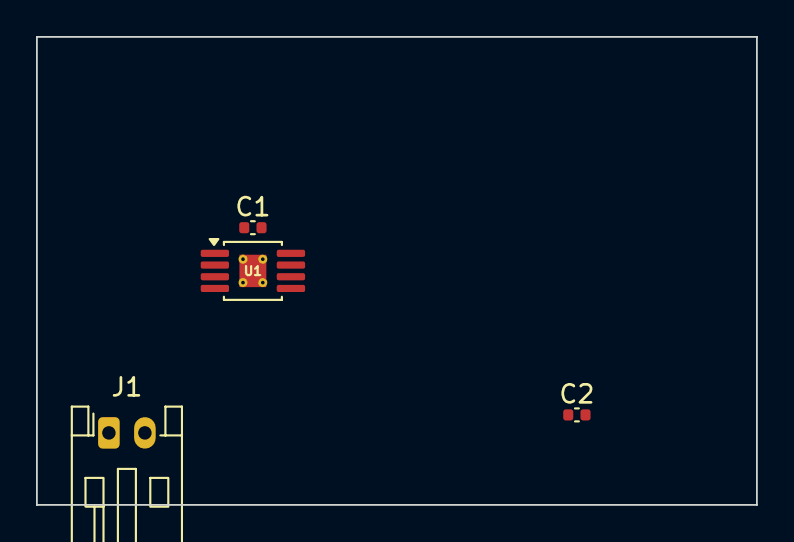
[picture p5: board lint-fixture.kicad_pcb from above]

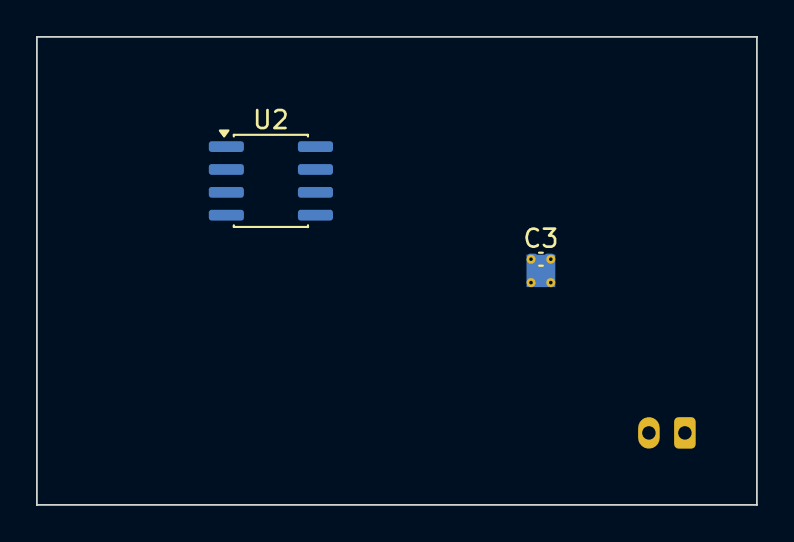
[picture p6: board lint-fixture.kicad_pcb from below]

Board: 2 copper layers, 40.0 x 26.0 mm, 6 parts (2 on the bottom side), 4 nets, no tracks yet.

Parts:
C1, C2: 100nF; C_0402_1005Metric
C3: 1uF; C_0402_1005Metric
J1: VIN; JST_PH_S2B-PH-K_1x02_P2.00mm_Horizontal
U1: TPS62840; MSOP-8-1EP_3x3mm_P0.65mm_EP1.5x1.8mm_ThermalVias
U2: OPA377; SOIC-8_3.9x4.9mm_P1.27mm

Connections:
GND: C1.2, C2.2, J1.2, U1.2, U1.9, U2.4
SENSE: C3.1, U2.1, U2.7
SW_NODE: C3.2, U1.1
VDD: C1.1, C2.1, J1.1, U1.5, U1.8, U2.8

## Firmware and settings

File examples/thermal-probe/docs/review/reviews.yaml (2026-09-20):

# Human review sign-off ledger — written by `review-gate`.
#
# A stage is done when its review here says `approved` and no artefact
# has changed since. The digests are how staleness is detected; do not
# hand-edit them. To record a decision:
#
#   review-gate sign <id> --approve --by <name> --note "what they said"
#   review-gate sign <id> --changes "what they want different"
reviews:
- id: vision
  title: Vision and concept selection
  stage: vision
  summary: 'Two concepts that differ in a nameable way: a one-handed wand

    with the probe on a lead, and a bench instrument that lives on a shelf. Both

    envelopes are measured off real geometry.'
  questions:
  - Which concept, and what made you pick it?
  - Is 164 mm too long to hold comfortably in a glove?
  artifacts:
  - path: docs/design/vision.md
    sha256: 6b13cff555cf5aa7
  - path: docs/design/vision/concept_a/elevation.svg
    sha256: cfcab37980ce60cf
  - path: docs/design/vision/concept_b/elevation.svg
    sha256: a1e368103887f426
  references:
  - concepts
  requested: '2026-09-20'
  requested_commit: 9f31024
  status: approved
  packet: docs/review/vision.md
  history:
  - 'on': '2026-09-20'
    action: requested
    commit: 9f31024
    questions:
    - Which concept, and what made you pick it?
    - Is 164 mm too long to hold comfortably in a glove?
    summary: 'Two concepts that differ in a nameable way: a one-handed wand

      with the probe on a lead, and a bench instrument that lives on a shelf. Both

      envelopes are measured off real geometry.'
    added:
    - docs/design/vision.md
    - docs/design/vision/concept_a/elevation.svg
    - docs/design/vision/concept_b/elevation.svg
  - 'on': '2026-09-20'
    action: approved
    commit: 9f31024
    by: harrison
    note: 'The wand. A freezer walk is one-handed and you are already carrying

      a clipboard — the bench version solves a problem we do not have.'
  note: 'The wand. A freezer walk is one-handed and you are already carrying

    a clipboard — the bench version solves a problem we do not have.'
  decided: '2026-09-20'
  decided_commit: 9f31024
  reviewer: harrison
- id: plan
  title: Project plan
  stage: plan
  summary: 'Eleven chunks, nine sessions on the critical path. Layout is

    blocked on the enclosure envelope, which is the dependency I am least sure

    about.'
  questions:
  - Is this all the work?
  - Is the order right — do you know a lead time we do not?
  artifacts:
  - path: docs/plan.md
    sha256: e49289ee63c3ac20
  references:
  - docs/plan.drawio
  - docs/plan.svg
  - plan.yaml
  requested: '2026-09-20'
  requested_commit: 9f31024
  status: approved
  packet: docs/review/plan.md
  history:
  - 'on': '2026-09-20'
    action: requested
    commit: 9f31024
    questions:
    - Is this all the work?
    - Is the order right — do you know a lead time we do not?
    summary: 'Eleven chunks, nine sessions on the critical path. Layout is

      blocked on the enclosure envelope, which is the dependency I am least sure

      about.'
    added:
    - docs/plan.md
  - 'on': '2026-09-20'
    action: approved
    commit: 9f31024
    by: harrison
    note: 'Add the drop test earlier if the enclosure is printed rather than

      moulded. Otherwise the order is right.'
  note: 'Add the drop test earlier if the enclosure is printed rather than

    moulded. Otherwise the order is right.'
  decided: '2026-09-20'
  decided_commit: 9f31024
  reviewer: harrison
- id: requirements
  title: Requirements tree
  stage: requirements
  summary: 'Fifteen requirements. SYS-001 moved from 12 h to 7 d after the

    logging interval was settled at one minute, which is the number worth arguing

    about.'
  questions:
  - Is 7 days the right target, or is 5 with a smaller cell better?
  - Is anything here that nobody asked for?
  artifacts:
  - path: docs/design/requirements-map.svg
    sha256: 16283c1f6496aa11
  references:
  - requirements/00-vision.sdoc
  - requirements/10-system.sdoc
  - requirements/hardware.sgra
  requested: '2026-09-20'
  requested_commit: 9f31024
  status: approved
  packet: docs/review/requirements.md
  history:
  - 'on': '2026-09-20'
    action: requested
    commit: 9f31024
    questions:
    - Is 7 days the right target, or is 5 with a smaller cell better?
    - Is anything here that nobody asked for?
    summary: 'Fifteen requirements. SYS-001 moved from 12 h to 7 d after the

      logging interval was settled at one minute, which is the number worth arguing
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

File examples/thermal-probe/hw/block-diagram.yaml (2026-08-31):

project: Thermal Probe
revision: C

rails:
  - id: VBUS
    voltage: 5.0
    source: J1
    max_current_a: 0.50
    notes: USB-C sink, 5 V @ 500 mA default. Charging only; not a run rail.

  - id: VBAT
    voltage: 3.7
    source: BT1
    max_current_a: 1.20
    notes: >-
      900 mAh LiPo, 3.0-4.2 V. Limit is the cell's 1C discharge rating, not a
      regulator. Peak is set by the display backlight inrush.

  - id: V3P3
    voltage: 3.3
    from: VBAT
    source: U2
    max_current_a: 0.25
    notes: MCP1700 LDO, 250 mA. Always-on rail; the 40 uA standby budget lives here.

  - id: VREF
    voltage: 2.5
    from: V3P3
    source: U4
    max_current_a: 0.010
    notes: REF3025 reference for the thermistor divider. Gated off in standby.

blocks:
  - id: J1
    name: USB-C receptacle
    kind: connector
    part: TYPE-C-31-M-12

  - id: BT1
    name: LiPo cell, 900 mAh
    kind: power
    part: LP503035

  - id: U1
    name: Battery charger
    kind: regulator
    part: MCP73831T-2ACI/OT
    powered_by:
      - rail: VBUS
        typ_current_a: 0.100
        max_current_a: 0.450

  - id: U2
    name: 3.3 V LDO
    kind: regulator
    part: MCP1700T-3302E/TT
    powered_by:
      - rail: VBAT
        typ_current_a: 0.0000016
        max_current_a: 0.000004

  - id: U3
    name: MCU
    kind: mcu
    part: STM32L071KBU6
    powered_by:
      - rail: V3P3
        typ_current_a: 0.00420
        max_current_a: 0.00810

  - id: U4
    name: Voltage reference
    kind: analog
    part: REF3025AIDBZR
    powered_by:
      - rail: V3P3
        typ_current_a: 0.0000420
        max_current_a: 0.0000650

  - id: U5
    name: Log flash, 16 Mbit
    kind: memory
    part: W25Q16JVUXIQ
    powered_by:
      - rail: V3P3
        typ_current_a: 0.000001
        max_current_a: 0.00400

  - id: DS1
    name: Segment LCD module
    kind: interface
    part: VIM-878-DP-RC-S-LV
    powered_by:
      - rail: V3P3
        typ_current_a: 0.000012
        max_current_a: 0.000025

  - id: RT1
    name: Probe thermistor, NTC 10k
    kind: sensor
    part: NTCLE100E3103JB0
    powered_by:
      - rail: VREF
        typ_current_a: 0.000250
        max_current_a: 0.000250

  - id: SW1
    name: Wake button
    kind: interface
    part: TL3305AF160QG

buses:
  - id: SPI1
    kind: spi
    controller: U3
    members: [U5, DS1]
    notes: 8 MHz, two chip selects. Flash and LCD share the bus.

  - id: ADC1
    kind: analog
    between: [RT1, U3]
    notes: Ratiometric against VREF, 12-bit, 16x oversampled

  - id: SWD1
    kind: swd
    between: [U3, J1]
    notes: Debug on the USB-C sideband pins via a test fixture

  - id: GPIO1
    kind: gpio
    between: [SW1, U3]
    notes: Wake interrupt, pulled up internally

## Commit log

2026-08-28 Define the AI hardware engineering environment, stack and workflow
    Sets up MakeHardware as an agent-driven hardware design repo: a cloud
    environment that provisions the toolchain, four stage skills, and a
    requirements system with enforced traceability.
    Fixes five failure modes in the drafted setup script, four of which had
    not surfaced yet because the first one aborted the run:
    1. add-apt-repository died with ModuleNotFoundError: apt_pkg. The base
    image points /usr/bin/python3 at Python 3.11 via update-alternatives,
    while Ubuntu 24.04's python3-apt only ships apt_pkg.cpython-312. The
    PPA is now added by writing the sources file and dearmouring the
    pinned signing key directly, w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
2026-08-28 Restructure as a plugin; add planning, sourcing and documentation stages
    Answers the "what even is this repo" question by making it one: a Claude
    Code plugin and marketplace that hardware project repos install, rather
    than a hardware project itself. Projects opt in with four lines in
    .claude/settings.json and scaffold with /hw-new-project.
    A template repo was the alternative and was rejected because copies
    diverge — a house practice learned on project three would never reach
    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
2026-08-28 Explain how the repo is used, and make the network choice explicit
    Adds docs/03-using-it.md: the two-repo model, what "plugin" means in
    concrete terms, the one-time environment and project bootstrap, and the
    one-session-per-chunk rhythm with who decides what at each checkpoint.
    Rewrites the network access guidance around the fact that a new
    environment can be given any policy. Previous measurements were taken in
    a Trusted-preset VM and read as fixed constraints; they are not. Custom
    with one extra host unlocks KiCad 10, and Full is worth considering here
    because sourcing and documentation both mean fetching from vendor sites
    you cannot enumerate in advance.
    Separates that from the constrai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
2026-08-28 Add image backends, kicad-happy, a retro loop; cut the hook to one job
    Image generation, extensibly. The skill defines a three-rung ladder the
    agent works down rather than assuming a backend: an already-connected MCP
    image server first (the Hugging Face connector's Spaces need no key at
    all), then a keyed API through the new imagegen script, then geometry
    only — said plainly rather than skipped silently.
    imagegen.py is a provider table, so adding a backend is an entry with
    four parts: the env var holding the key, how to build the request, how to
    extract an image, and whether it accepts an init image. fal, Black Forest
    Labs and OpenAI ship. Keys come from .env (gitignored) or the
    environme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
2026-08-28 Install Konnect from the release asset; make the build survive its budget
    The environment build was being killed at the ~5 minute budget partway
    through Konnect's Rust compile, and because status.json and the hw-*
    helpers were written after the phases, sessions came up with a half-built
    toolchain and nothing to explain why.
    Konnect: download instead of build. The premise that the GitHub proxy
    403s release assets was tested against the wrong URLs — the API and the
    release web pages are scoped to attached repositories, but
    /releases/download/<tag>/<file> is served. Verified on the image: 11 MB,
    seconds to fetch, runs, and needs glibc 2.39 exactly as Ubuntu 24.04
    ships. `konnect init` instal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
2026-08-28 Add block-diagram stage, project template repo, fix build123d MCP
    Three changes.
    **Electrical block diagram (new workflow stage 4).** The architecture is now
    settled before schematic capture: major ICs, the power tree with a current
    budget, and the data buses. `hw/block-diagram.yaml` is the source of truth;
    `block-diagram` renders it to an editable draw.io file and to an SVG that
    renders inline on GitHub, plus an optional PNG. Generating both from one spec
    is what stops the picture and the architecture disagreeing.
    The budget is the part that earns its keep — a rail carries its own loads plus
    everything on the rails derived from it, and `--check` exits 1 when a rail
    draws more than its s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
    [block-diagram.yaml]
2026-08-28 Add a script to create the project template repository
    `templates/github-repo/create-template-repo.sh` creates the repo, pushes the
    template contents, and flips GitHub's is_template switch in one command. It
    excludes itself and README-TEMPLATE-NOTES.md, which belong to MakeHardware
    rather than to projects made from the template, and refuses to touch a repo
    that already exists since it pushes an initial commit.
    It has to run locally. A Claude Code cloud session's GitHub token is scoped to
    the repository the session started on, so creating a repo returns 403, and
    nothing available in a session can set is_template. The doc now says so at the
    point where someone would otherwise try.
    Co-Authore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
2026-08-28 Point template docs at the real template repo
    The template repository now exists as Harwasch/makehardware-template, so
    the script default, the docs and the gh example use that name instead of
    the placeholder hardware-project-template.
    Also switches the two MakeHardware links in the template README from
    /main to /HEAD — this repo has no main branch, so those links were dead
    in every project created from the template.
    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
2026-08-29 Add the review-gate mechanism and fix the friction-log defects in the tooling
    The workflow stated an exit condition for every stage and had nothing that
    made one happen, so four stages ran with no human review and the plan,
    requirements and architecture were built on an agreement never made. The
    agent also works in a cloud VM, so the human's only review surface is the
    repository on github.com — an artefact under build/ is an artefact nobody
    sees.
    review-gate (new, plus bin wrapper):
    A review is an artefact the browser can open, a request carrying the
    github.com URLs, and a decision recorded in docs/review/reviews.yaml with
    the digest of every artefact as it stood. Changing a signed-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
2026-08-29 Make human review a stage of the workflow, not a sentence in it
    Adds the hw-review skill and /hw-review command, and wires the gate into
    every stage skill, the workflow doc, the commands and the project template.
    The rule the whole thing turns on: an artefact the human has not seen is not
    a deliverable. And since the agent is normally in a cloud VM, the only
    surface the human has is the repository on github.com — so each stage now
    commits something that renders there, asks with the link, and blocks.
    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
2026-08-29 Write the review packet for the human who lands on it
    The Decision section showed `review-gate sign ...` — agent commands, on the
    one page a human reaches by clicking the link. It now tells them what is
    actually being asked of them (answer in the Claude session; say which and
    why), with the agent's commands folded away. The approved, changes-requested
    and stale wordings are addressed to them too: "you approved it, and then
    something you agreed to changed" rather than a status line.
    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
2026-08-31 Add review-artifact: the project review page, generated from the repo
    A second review surface alongside the GitHub packets — one tabbed page,
    published as a Claude Artifact, that gains a tab per phase and carries the
    whole project by the end. Artifacts take anchored comments, which beats a
    paragraph in a chat log, and the comments come back to the agent.
    Nothing on the page is typed by hand. Every number, table, diagram and status
    is read from the file that owns it: plan.yaml, hw/block-diagram.yaml, the
    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
2026-08-31 Rework the block diagram layout, and carry CAD, schematic and plots
    Block diagram (the "reads like a data table, and the lines all cross"):
    Blocks within a column are now ordered by the median of their neighbours,
    swept both ways a few times — the standard crossing-reduction heuristic —
    so connected blocks end up level with each other and columns are centred
    rather than top-aligned. A two-block bus is drawn as one line between the
    two blocks, which is what it is; only a bus with three or more members
    gets a spine, and that spine runs vertically in the corridor between
    columns instead of in a band underneath everything. The old band forced
    every member to drop a stub past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
    [reviews.yaml]
2026-08-31 Fan out block diagram ports, add a Review tab, and de-risk real tool output
    Block diagram, second round. Fanning the columns out was only half of it:
    every connection still left its block at the vertical centre, so an MCU with
    four of them drew four lines from one point — and every vertical run sat at
    the same x, so two links between the same pair of columns overlapped for
    their whole length. Connections are now distributed along each block's edge,
    ordered by where the other end sits, and spines and link verticals share one
    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
    [bom-summary.csv]
2026-08-31 Fix dark mode in inlined SVGs, and add a keyed image-generation path
    The dark-mode breakage was mine, from the previous commit. Scoping the
    inlined SVG's CSS by splitting on `}` and prefixing whatever looked like a
    selector got the one case wrong that mattered most: an @media block's first
    rule kept `@media (...)` in its prelude, so it was left global while the rules
    after it were scoped and the braces stopped balancing. The exporter's dark
    palette leaked onto the page and its own light rules outranked the dark ones,
    which is why a dark page rendered a light diagram with dark boxes in it.
    The scoper now walks the stylesheet with brace matching and descends into
    at-rules properly. It also tr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
    [reviews.yaml]
2026-08-31 Test against real KiCad output, and rebuild the manufacturing tab
    Installed kicad-cli and pointed it at KiCad's own demo projects instead of
    guessing at what the exporter emits. Several guesses were wrong, and one of
    them was a real bug.
    **The intrinsic-width bug.** KiCad writes the page size in millimetres twice,
    meaning different things: `width="297.0022mm"` is the intrinsic size, while
    `viewBox="0 0 297.0022 210.0072"` is the user-unit system. The inliner
    preferred the viewBox, so an A4 schematic was laid out 297 px wide — a
    thumbnail of a drawing nobody could read. The test suite missed it because its
    fixture used a px-shaped viewBox, which no plotter writes.
    **SVG had no budget at a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
    [pic_programmer.kicad_sch, pic_sockets.kicad_sch, quotes.csv]
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2026-08-31 Manufacturing is a checklist; every diagram opens in draw.io
    Two things the manufacturing tab was getting wrong. It rendered the drawings
    inline, and a fabrication drawing shrunk to page width tells nobody anything
    they can act on. And it had no way to say what was *missing*, which is the
    only question that stage is really asking.
    So the tab is now one grouped checklist — fabrication, assembly, commercial —
    with a present/missing tally, a link to every document that exists, and a
    row that stays put saying "Not produced" for every one that does not. The
    example reads 7 of 12 present, 5 still to produce, which is what a release
    decision actually hangs on. The drawings, notes, quotes and p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
    [reviews.yaml]
2026-08-31 Make the review page something a new project actually gets
    The page worked, but only for the one project it was developed against.
    Everything that made it work there had been done by hand in this session, so a
    fresh project would have got the four standard milestones and nothing else,
    and nobody would have noticed the design stages were missing — there was
    nothing to notice.
    Three gaps, in order of how much they cost.
    **`review-artifact --init`.** `docs/review/artifact.yaml` is what decides
    whether a schematic, a layout, an enclosure or a release checklist ever
    appears, and nobody writes that from a blank file. `--init` now generates it
    from what the repo contains: phases whose artefacts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
    [reviews.yaml]
2026-09-01 Add magnetics: FastHenry, Elmer and GetDP, and a skill that knows them
    SPICE cannot tell you an inductance. Until now neither could this toolbox,
    which is a whole discipline missing rather than a feature.
    `phase_magnetics` installs Elmer 26.2, FastHenry 3.0.1 and GetDP 3.2.0 in a
    measured three minutes, concurrently with the KiCad and Python phases, and
    needs nothing outside the existing allowlist. Elmer comes from a prebuilt
    tarball because it is not in the Ubuntu repos and its PPA is off the
    allowlist; from source it is ~20 minutes, which does not fit the build
    budget. MH_ENABLE_MAGNETICS=0 turns the phase off. It also clones
    elmer-elmag, because `.sif` is a niche format whose failure mod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
2026-09-04 Add sch-lint: a readability gate for KiCad schematics
    ERC answers whether a circuit is consistent. Nothing answered whether a
    human can read the drawing, so schematics came out as whatever the
    placement loop emitted.
    kicad_sexpr.py is a read-only S-expression reader — Konnect's
    never-edit-a-.kicad_*-file rule is about writes and is untouched, but a
    gate has to run headless with no KiCad and no MCP server, so it needs its
    own parser. Verified against both dialects present here: the KiCad 7
    schematic fixture and KiCad 10's shipped boards.
    sch_lint.py runs fourteen checks. The load-bearing one is the library-to-
    sheet pin transform (mirror, rotate, flip Y); it is verified by the fact
    that i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
2026-09-04 Add hw-schematic: house practice for a readable drawing, and the sheet it goes on
    Konnect will place a symbol anywhere it is told to. Nothing had an opinion
    about where, so a capture loop trying only to satisfy a netlist produced
    drawings that were correct and unreadable — and the review that should
    have caught the design error got spent on deciphering the picture.
    The skill states the partition (root = the block diagram, power its own
    sheet, decoupling always beside its pin, one sheet one job), the rules
    worth a gate, and points every rule at its sch-lint code.
    references/readability.md gives each rule the failure it prevents;
    references/sheet-plan.md derives the sheets from the agreed
    b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
2026-09-04 Add pcb-lint and hw-pcb-layout: the pre-route checks, run rather than remembered
    Every check here is a section of hw-verification/references/pcb-layout.md
    turned from prose somebody has to remember into arithmetic. Each finding
    cites its section, because the reasoning is worth reading once and the
    check is worth running every time.
    The fact that decided the design: **net classes are not in the .kicad_pcb.**
    They live in the sibling .kicad_pro under net_settings.classes. Grepping the
    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
    [lint-fixture.kicad_pcb]
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2026-09-04 Add cad-export and hw-cad: assemblies somebody can open, not one unnamed lump
    The example enclosure was a single BuildPart exported as one STEP. What
    arrived at the other end was a solid — no part names, no colours, no way to
    hide the lid and look inside, nothing saying which face mates to which.
    cad-export takes a build123d module exposing ASSEMBLY and writes STEP
    (AP242, tree, names, colours, plus a named datum cross at every joint), GLB
    for the review page's viewer, STL for GitHub's blob viewer — the only 3D
    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
    [enclosure.3mf, enclosure.step, enclosure.stl]
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2026-09-04 Review page: pan and zoom on every figure, a 3D viewer, sortable tables
    The plumbing was good and the page was static. A plotted A4 schematic
    squeezed into a browser column is legible as a shape and unreadable as a
    document, which makes it decoration on the one page that is supposed to be
    the review.
    * Scroll-to-zoom, drag-to-pan, double-click-to-reset on every inlined SVG
    and raster, anchored at the cursor so it feels like moving a magnifier
    rather than resizing a picture. Verified in headless Chromium: wheel gives
    scale(1.18) with the anchor translate, the button gives scale(1.4), and
    double-click returns to scale(1).
    * A .glb in a phase's `images:` becomes an orbit viewer — thr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
    [enclosure.3mf, enclosure.step]
2026-09-04 Wire the new gates and figures into the workflow, and bump to 0.4.0
    A skill nothing points at is a skill nothing runs. This connects the four
    new subsystems to the stages that should use them.
    * The project CLAUDE.md gains the precedence rows (Konnect places, the new
    skills decide where), the commands, "show it, do not describe it", the
    three drawing rules, and six gotchas that will otherwise be rediscovered:
    the .kicad_wks parser that fails silently, net classes living in the
    .kicad_pro, KiCad's legitimately off-grid property text, build123d's
    reparenting Compound, and GitHub's 3D viewer being STL-only.
    * hw-review becomes artifact-first without abandoning the repository: the
    p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
    [enclosure.3mf, enclosure.step, lint-fixture.kicad_pcb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]
2026-09-04 Rebuild the thermal-probe fixture from the real tools
    Every artefact under examples/thermal-probe/docs/ now comes from the tool
    that owns it: cad-export for the assembly and its renders, pcbnew for the
    board fixture, sch-lint and pcb-lint for the overlays, block-diagram --csv
    plus hw-chart for the power budget, and kicad-cli for the sheets.
    The architecture tab leads with the budget chart rather than the diagram,
    which is the point: VBUS at 90% of a 500 mA port is the fact that review is
    about, and it is invisible in the block diagram.
    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
    [enclosure.3mf, enclosure.step, lint-fixture.kicad_pcb]
2026-09-04 hw-doctor: stop it hanging, and say plainly when a tool is absent
    `fasthenry` with no arguments reads a deck from stdin and waits forever, so
    `hw-doctor` — the command the workflow tells you to run first, and which an
    agent runs non-interactively — produced no output at all and never
    returned. Found by running it: twelve minutes, zero bytes.
    Every probe now runs with stdin closed and under a timeout, which is the
    general fix rather than a special case for one tool. A diagnostic that hangs
    is worse than one that reports a failure, because there is nothing to read
    and nothing to act on.
    While there: `timeout` reports its own "failed to run command" for anything
    absent, which buries the f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
2026-09-10 Fix Elmer and Konnect, add Onshape, and make the design loop visible
    Four things that were broken or missing, and one that changes how every
    review reads.
    Elmer had never installed, in any session, in any environment. The pinned
    tarball URL is a release asset on this repository and there are no releases on
    this repository — it 404'd on every build from the day it was written.
    phase_magnetics degraded every time, and because a degraded phase still exits
    0 the environment came up looking healthy with no ElmerSolver in it. It now
    comes from the upstream elmer-csc PPA, on the same host KiCad 10 already
    needs, so it costs no allowlist entry. Verified: v26.2, ~70 s, and a coupled
    magnetostatic/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
    [enclosure.3mf, enclosure.step, lint-fixture.kicad_pcb]
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2026-09-10 Replace Konnect with ki-stack
    Konnect was an MCP server: one Rust binary, 214 tools over KiCad 10's IPC API.
    ki-stack is nine SKILL.md files and a dozen shell helpers that teach the agent
    to drive the three real substrates itself — kicad-python for live IPC,
    kicad-cli for render/export/DRC/ERC, kiutils-rs for structured offline edits.
    The argument is what kicad-cli cannot do. It has no add, place, route or
    connect verb, so something has to drive the IPC API; the only question is
    whether that something is pre-sliced verbs or code the agent writes. Two things
    settled it. A tool surface costs context whether or not it is used — Konnect
    loaded 2 of its 20 toolsets at startup and made the ag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
2026-09-10 Swap the KiCad skill pack: ki-stack out, KiStack in
    Both are skills rather than servers, so 0.7.0's argument against an MCP tool
    surface stands unchanged. This is a choice between two packs.
    They are different books. Milind220/ki-stack is a manual for the substrates —
    how to route between live IPC, kicad-cli and structured file edits.
    American-Embedded/KiStack is house practice from a working shop: what a good
    schematic looks like, how to place before routing, when a pin swap is worth it,
    how to read a Gerber. This toolbox already answered the substrate question in
    hw-schematic and hw-pcb-layout. What it did not have was the craft.
    Ten skills, linked under their frontmatter names rather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
2026-09-14 Close the loop back to this repo: hw-feedback
    `hw-retro` has told the agent to "offer to file the proposed changes as a
    GitHub issue on Harwasch/MakeHardware" since 0.5.0 and never named a
    mechanism, because there isn't one. `gh` is not in the environment, and a
    cloud session's GitHub token is scoped to the project repo, so it cannot
    reach this one. Every retro that ever ran ended by offering something
    impossible.
    The design decision behind the fix: an issue tracker is the right place to
    publish a finding and the wrong place to capture one. It wants an account, a
    browser and a context switch at exactly the moment — mid-work, mid-correction
    — when a finding is cheapest to write down and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
2026-09-14 Close the repair gap: python groups, base, and a bootstrap from nothing
    hw-repair could repair two of the seven things setup.sh installs, and
    `hw-repair kicad` installed the skill pack rather than KiCad. The phase most
    likely to fail was the one it could not touch: phase_python pulls
    cadquery-ocp, a ~400 MB wheel and by far the most likely thing in the build to
    time out. A session learned its toolchain was broken and could do nothing but
    wait for someone to rebuild the environment.
    hw-repair python [group] re-runs one of phase_python's install groups. The
    groups exist so one flaky dependency cannot take out the rest; this finishes
    the thought. It is more likely to succeed than the build was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
2026-09-20 Close the design loop: run the verifier, extract the numbers, verify them
    The loop was a diary. hw-iterate recorded what the agent said it had done and
    executed nothing: every metric arrived on the command line, read off a
    simulator's output by the agent and typed back in. --evidence named the file
    the number came from and nothing ever opened that file. The chart looked like
    evidence and was testimony.
    That broke this repository's second founding rule, in its newest subsystem.
    Every number on an evolution chart is a number on a review page, and CLAUDE.md
    has said since the beginning that a figure a tool could compute and a human
    typed is already wrong.
    hw-iterate run executes the verifier,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
    [enclosure.3mf, enclosure.step, lint-fixture.kicad_pcb]
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2026-09-20 The board documentation gate, the design at every zoom level, and CI
    Three things, all aimed at the same bar: a board somebody can build without
    asking questions, and a page that shows what was built.
    Four new pcb-lint rules ask whether anybody can build, stuff, test and trace
    the board. The nine existing rules ask whether it works; these ask about the
    half a contract manufacturer and a bring-up engineer see first, and the half
    that is invisible until the boards arrive and nobody can tell rev B from rev
    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
    [enclosure.3mf, enclosure.step, lint-fixture.kicad_pcb]
